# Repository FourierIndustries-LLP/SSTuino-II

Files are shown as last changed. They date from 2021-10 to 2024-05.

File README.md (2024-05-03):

Designed by FourierIndustries LLP | Designed and tested in Singapore

# SSTuino II

SSTuino II is an easy to use and industrial-ready Wi-Fi enabled microcontroller, designed and fabricated by SST Alumni. With a smaller form factor, improved Wi-Fi and processing capabilities, this is the next generation of SSTuino.

**SSTuino II documentation available at: https://knowledge.fourier.industries**

## Technical information

### Pinout diagram

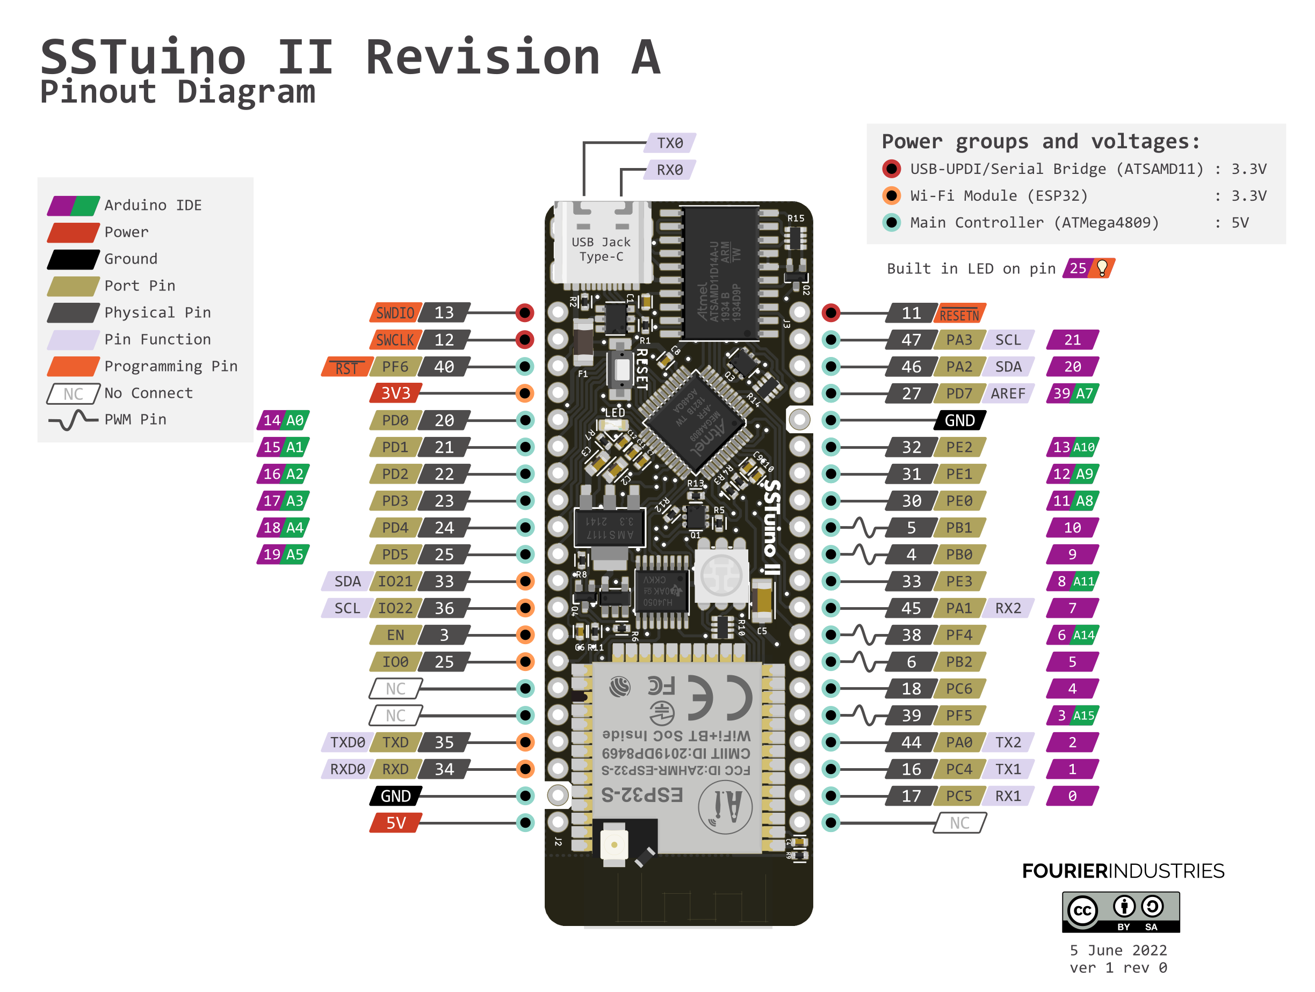
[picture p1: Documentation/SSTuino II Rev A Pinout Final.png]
Pinout


### Repository Layout

* **SSTuino_II**: CAD files for SSTuino II
* **SSTuinoII_Jig**: CAD files for the SSTuino II test jig
* **Manufacturing**: Manufacturing files (Gerbers, BOM, component placement)
* **Documentation**: Documentation for design and manufacturing (not user manuals)
* **Tooling**: Software tools for production and debugging of the SSTuino II

### Automatic repair tool

Paste and run the following command in your terminal to run the autorepair tool, should you run into difficulty launching Arduino IDE or uploading programs onto your SSTuino II. Follow the on-screen instructions carefully. 

Note: This tool is only compatible with Arduino IDE 2. 

```shell
/bin/bash -c "$(curl -fsSL https://raw.githubusercontent.com/FourierIndustries-LLP/SSTuino-II/HEAD/Tooling/sstuino-autorepair.sh)"
```

## Contributing

Contributing to the SSTuino II Git Repository requires you to have EAGLE 8.4 or newer which supports Managed Libraries.

SSTuino II primarily uses EAGLE's Managed Libraries made by Sparkfun, but also contain our own custom footprints and SMD component footprints from various manufacturers.

SSTuino II is derived from the [Arduino Uno WiFi REV2](https://store-usa.arduino.cc/products/arduino-uno-wifi-rev2), and is licensed under a [CC BY-SA 4.0 International license](http://creativecommons.org/licenses/by-sa/4.0/).



## Our team

* Goh Qian Zhe ([@QianZheGoh](https://twitter.com/QianZheGoh))
* Pan Ziyue ([@d3lta-v](https://twitter.com/sammy0025))

And special acknowledgement to the awesome folks at Arduino, Sparkfun and Adafruit for technical reference and ECAD models.

OSHW

Open Source Hardware (OSHW)

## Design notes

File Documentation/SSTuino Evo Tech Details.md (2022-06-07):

# SSTuino Evo Technical Information

This document outlines the deep technical information regarding the SSTuino Evo ("the device") and its constituent modules on the board ("module"), ensuring a high level of design stability, documentation and conformity to standards.

{{TOC}}

## Board layout

The board is routed in imperial units on a 12.5 mil (mili-inch, thousandths of an inch, 1/1000).

Power traces are mostly 24-16 mils, while signal traces are 10 mils standard, going down to a minimum of 8 mils when needed.

Isolate is set at 10 mils, same as majority of signal traces to ensure good manufacturability. 

Text is set at 32 mils, 14% ratio for component identifiers for optimal legibility across manufacturers.

## External Interface (pins)

The pinout of the device is as follows:

**Left Side:**

| Pin | Name | Purpose |
| :-: | :--- | :--- |
|  1  | SWDIO | COM: Programming port |
|  2  | RST (PF6) | MCU: Reset (active low) |
|  3  | 3.3V | Power, 3.3V out |
|  4  | SWCLK | COM: Programming port |
|  5  |  A0 (PD0) | MCU: Analog in |
|  6  |  A1 (PD1) | MCU: Analog in |
|  7  |  A2 (PD2) | MCU: Analog in |
|  8  |  A3 (PD3) | MCU: Analog in |
|  9  |  A4 (PD4) | MCU: Analog in |
|  10 |  A5 (PD5) | MCU: Analog in |
|  11 |  ESP/SDA  | ESP: I2C SDA pin |
|  12 |  ESP/SCL  | ESP: I2C SCL pin |
|  13 | ESP/EN  | ESP: EN pin (active high) |
|  14 |  ESP/IO0  | ESP: IO0 pin for bootup |
|  15 | NC | |
|  16 | NC | |
|  17 | ESP/TX  | ESP: UART Tx (5v logic) |
|  18 | ESP/RX  | ESP: UART Rx (5v logic) |
|  19 | GND | Ground |
|  20 | 5V | Power, 5V out/in |

**Right Side:** 

| Pin | Name | Purpose |
| :-: | :--- | :--- |
|  1  | RESETN | COM: Programming port |
|  2  | 21 (SCL/PA3) | MCU: I2C SCL pin |
|  3  | 20 (SDA/PA2) | MCU: I2C SDA pin |
|  4  | AREF (7/PD7) | MCU: AREF pin |
|  5  | GND | GND |
|  6  | 13 (PE2) | MCU: digital IO 13 |
|  7  | 12 (PE1) | MCU: digital IO 12 |
|  8  | 11 (PE0) | MCU: digital IO 11 |
|  9  | 10 (PB1) | MCU: digital IO 10 (PWM capable) |
|  10 | 9 (PB0) | MCU: digital IO 9 (PWM capable)  |
|  11 | 8 (PE3) | MCU: digital IO 8 |
|  12 | 7 (PA1) | MCU: digital IO 7 |
|  13 | 6 (PF4) | MCU: digital IO 6 (PWM capable)  |
|  14 | 5 (PB2) | MCU: digital IO 5 (PWM capable)  |
|  15 | 4 (PC6) | MCU: digital IO 4 |
|  16 | 3 (PF5) | MCU: digital IO 3 (PWM capable)  |
|  17 | 2 (PA0) | MCU: digital IO 2 |
|  18 | 1 (PC4) | MCU: digital IO 1 (TX) |
|  19 | 0 (PC5) | MCU: digital IO 0 (RX) |

This needs further validation with the MegaCoreX pin designations.

| Validation Type | Result  |
| :--- | :--- |
| Pinout Validation | Pending |
| Logic Validation  | Pending |

## USB Interface

### USB 2.0 Type C Plug

This module includes the Type-C (USB 2.0 protocol only) receptacle and the appropriate CC1 and CC2 pull-down resistors of 5.1kOhm 0402 SMD resistors. 

For standards surrounding the USB PD protocol for Type-C, please refer to [Microchip's AN1953 Application Note](http://ww1.microchip.com/downloads/en/appnotes/00001953a.pdf), section 3.2.

It is very similar to a [reference design made by Tyler Ward](https://www.scorpia.co.uk/2016/03/17/using-usb-type-c-on-hobyist-projects/)

| Validation Type | Result |
| :--- | :----- |
| Pinout Validation | PASS |
| Logic Validation  | PASS |

The shield of the USB Connector is connected to ground, as per design reference from many designs such as the Adafruit Feather series. A potential future improvement is to connect it to an RC circuit of 4.7nF and 1MOhm components. As mentioned in the SAMD11 data sheet, "Tying the shield directly to ground would create a direct path from the ground plane to the shield, turning the USB cable into an antenna. To limit the USB cable antenna effect, it is recommended to connect the shield and ground through an RC filter.".

### Overcurrent and ESD Protection

This module protects the rest of the device from dangerous electrical conditions, namely overcurrent and electrostatic discharge (ESD). 

The overcurrent protection is handled by a [Littelfuse 1206L075THYR](https://datasheet.lcsc.com/lcsc/1810111934_Littelfuse-1206L075THYR_C99563.pdf) polyfuse packaged in 1206, which cuts off at 6V, 0.75A, with a maximum time to trip of 0.2s at 8A.

ESD protection is handled by a [TechPublic TPUSBLC6](https://datasheet.lcsc.com/lcsc/2005211235_TECH-PUBLIC-TPUSBLC6-2SC6_C558442.pdf) TVS diode array specifically designed for USB 2.0 interfaces.

| Validation Type | Result |
| :--- | :----- |
| Pinout Validation | PASS |
| Logic Validation  | PASS |

### Serial Interface

#### Hardware

The serial interface of the device is provided by an ATSAMD11D14A-SSUT/SSNT (20-pin SOIC) ARM Cortex-M0 processor acting as a USB to TTL Serial and USB to UPDI two-in-one converter. This design is based on the Arduino Nano Every, modified to use a larger 20-pin SOIC chip due to board density constraints as well as the 2020/2021 global chip shortage.

The chip itself contains a pinout for RESETN, SWDIO and SWCLK (standard ARM MCU programming port using CWSIS-DAP). Keep in mind that all of this is 3.3V I/O.

The chip is supported by a 0.1uF (100nF) capacitor for decoupling.

RESETN (PA28) and SWCLK (PA30) is tied to logic high through a 4.7kOhm resistor, while SWDIO (PA31) is floating. This is validated.

PA24 and PA25 on the MCU are connected to USB D- and D+ respectively. This pinout is validated.

PA14 and PA15 are programmed as a normal serial port, bit-banged to UPDI spec, and goes through bidirectional level shifting `(3.3V<->5V)`. This pinout is validated.

PA22 and PA23 are the TX and RX lines respectively. Both of them go through bidirectional voltage shifting `(3.3V<->5V)`.

The only component that was not integrated with this design compared with the Arduino Nano Every are the two LED lights sitting on the TX/RX lines.

| Validation Type | Result  |
| :--- | :--- |
| Pinout Validation | PASS |
| Logic Validation  | PASS |

#### Software

The software of the Serial Interface shall convert USB signals to TTL-Serial and Atmel UPDI signals for programming and communication between the host computer and the device.

Reprogramming the software on the SAMD11 requires a CMSIS-DAP ARM programmer running at 3.3V logic levels, to target the RESETN, SWDIO and SWCLK pins exposed on the board. Power is still provided by 5V and GND.

The [breadboard SAMD11 tutorial](https://funwithsoftware.org/posts/2019-09-01-breadboard-samd11-part1.html) is an excellent place to start for ARM-based firmware flashing.

The full procedures are [here](https://www.avrfreaks.net/comment/2832921#comment-2832921).

How to load the Bootloader:

1. Install OpenOCD on your Mac if you haven't already: `brew install openocd`
2. Create a folder for two files: the bootloader file itself (looks like `sam_ba_arduino_MuxTO_SAMD11D14AM.bin`) and the `openocd.cfg` file
3. Copy the SAMD11 tutorial's default code for OpenOCD into the configuration file and edit the file name
4. Type `sudo openocd` to begin programming

How to load the Bootloader (PyOCD version)

1. Install PyOCD if you have not: `brew install libusb; python3 -mpip install -U pyocd`
2. Create a folder for 3 important files: the target chip's .pack file, the programmer's .pack file, and the bootloader
3. Download the bootloaders from the [Arduino Core SAMD MuxTO branch repo](https://github.com/arduino/ArduinoCore-samd/tree/muxto/bootloaders/zero/binaries)
4. Erase the chip with `pyocd erase -t atsamd11d14as --chip --pack ~/Downloads/Microchip.SAMD11_DFP.2.5.61.atpack`
5. Execute the command `pyocd flash -t atsamd11d14as --base-address 0x0 sam_ba_arduino_MuxTO_SAMD11D14AM.bin --pack ~/Downloads/Microchip.SAMD11_DFP.2.5.61.atpack`
6. Protect the bootloader by executing a custom OpenOCD script to set the bootloader length to 4096 bits. Run `sudo openocd -f protect_bootloader.cfg`

After the Bootloader is loaded onto the SAMD11, it's time to load the firmware. You might want to compile the firmware for yourself first with the [steps in this guide](https://forum.arduino.cc/t/compiling-and-loading-the-muxto-code/627145)

1.  Add board manager URL: 
2.  Install MattairTech SAM D|L|C core for Arduino - Beta build v1.6.18-beta-b1
3.  Download **bootloader** binary blob from 
4.  Flash bootloader to device
5.  Short SWDIO to GND
6.  Flash the MuxTO **firmware** to device with the following command over the native USB port: 
        
    ```
    ./bossac --port=/dev/cu.usbmodem14101 -U true -i -e -w -v ./MuxTO_SST.bin -R
    ```

Alternatively, it should be possible to flash the hex file directly to the system through the same CMSIS-DAP PyOCD interface by running the following command: `pyocd flash -t atsamd11d14as ~/Library/Arduino15/packages/arduino/hardware/megaavr/1.8.7/firmwares/MuxTO/MuxTO.hex --pack ~/Downloads/Microchip.SAMD11_DFP.2.5.61.atpack`

At this point, we're not done yet. We need to patch MegaCoreX's `boards.txt` with our own custom configuration to let MuxTO work through a hacky version of JTAG2UPDI:

```
################################################
4809.menu.pinout.sstuinoii=SSTuino II
4809.menu.pinout.sstuinoii.build.variant=uno-wifi
4809.menu.pinout.sstuinoii.upload.tool=avrdude_nanoevery
4809.menu.pinout.sstuinoii.upload.use_1200bps_touch=true
4809.menu.pinout.sstuinoii.upload.protocol=jtag2updi
4809.menu.pinout.sstuinoii.program.extra_params=-P{serial.port} -e
4809.menu.pinout.sstuinoii.build.compat=
#################################################
```

If you need to build from source, you will need to patch Arduino specific changes to MT's core. 

Compilation options available here: `arduino:samd:muxto:float=default,config=enabled,clock=internal_usb,timer=timer_732Hz,bootloader=4kb,serial=two_uart,usb=cdc`

[Link](https://github.com/arduino/ArduinoCore-megaavr/blob/master/.github/workflows/compile-muxto.yml)

If you wish to change the MuxTO firmware without recompilation, you can directly edit the `MuxTO.bin` file using a hex editor. 

For example, the USB VID and PID can be edited at offset 0x2E3C, with an order of `[VID LSB][VID MSB][PID LSB][PID MSB]` (least and most significant *byte*, not bit). For more details, see this [line of code in Arduino Core](https://github.com/arduino/ArduinoCore-samd/blob/9f91accecc8298976670234e4d6ac0afef5c7a39/bootloaders/zero/sam_ba_usb.c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)

If the bootloader + an existing firmware is already on the chip, short SWDIO to GND to enter bootloader mode for direct USB programming.

During the flashing of the ATmega4809 target, the programmer type needs to be JTAG2UPDI, as it essentially pretends to be a JTAG device, with a bit of a special 1200bps handshake in between to initiate the UPDI process. You will need to specify the target serial port.

These were the fuses returned by avrdude:

```
fuse0: 0x0 (WDTCFG)
fuse1: 0x0 (BODCFG)
fuse2: 0x2 (OSCCFG)
fuse4: 0x0
fuse5: 0xe4 (SYSCFG0)
fuse6: 0x7 (SYSCFG1: startup time only)
fuse7: 0x0 (APPEND: end of application section)
fuse8: 0x0 (BOOTEND: end of boot section)
lock: 0xc5 (LOCK)
```

`OSCCFG` is configured as: 0x02, same as default factory setting, which is to run at 20MHz, with no oscillator lock meaning that calibration registers can be adjusted at runtime.

`SYSCFG0` seems to be configured as: 0xe4. Note that default factory value is 0xCO, which echoes exactly the same fuse settings (but not as corrupted)! It appears that the reserved fuses are not even properly cleared as 0? The correct hex value is 0xc9,

**Current chip settings**: 

* CRCSRC: BOOTAPP
* RSTPINCFG: GPIO <- this is interesting! Because it should have been set to RESET. A fuse configuration error?
* EESAVE: EEPROM erased by chip erase

**Correct settings as per board definition**:

* CRCSRC: BOOTAPP
* RSTPINCFG: RESET
* EESAVE: EEPROM NOT erased by chip erase

`LOCK` is as factory default, no need to change as altering it will lock the chip.

Comparison between the two settings:

```
0xe4: 1110 0100
0xc9: 1100 1001
```

**Further Reading**

* [PyOCD Tutorial](https://www.hackster.io/sabas1080/how-to-debug-hardware-with-openocd-or-pyocd-e7e718)
* [PyOCD Tutorial #2](https://chowdera.com/2021/08/20210825013223713b.html)
* [PiOCD GitHub](https://github.com/pyocd/pyOCD)
* [Keil .pack library](https://www.keil.com/dd2/pack/#!#third-party-download-dialog)
* [OpenOCD CPU configuration](https://openocd.org/doc/html/CPU-Configuration.html)
* [OpenOCD Debug Adapter config](https://openocd.org/doc/html/Debug-Adapter-Configuration.html)
* [OpenOCD Config File Guide](https://openocd.org/doc/html/Config-File-Guidelines.html)

### Level Shifting

The level shifting portion of the USB interface is handled by a dual transistor BSS138PS IC and a single transistor BSS138PW, which shifts 3.3V to 5V and vice versa, fully bidirectional.

All transistors use 4.7kOhm resistors.

| Validation Type | Result  |
| :--- | :--- |
| Pinout Validation | PASS |
| Logic Validation  | PASS |

## Voltage Regulator

The onboard voltage regulation is handled by an AMS1117-3.3 Low Dropout (LDO) linear voltage regulator. The voltage regulator is responsible for delivering adequate current and stable power at the correct voltage to the ESP32 and ATSAMD11D14A chips. 

This particular type of LDO is cheap and widely available, but is not the most efficient, especially at low power, due to its higher quiescent current.

For reference, [Andrea's video on ESP32 boards](https://www.youtube.com/watch?v=ajt7vtgKNNM) offers a fantastic comparison of the different power supplies used by the different boards. Future boards may use more efficient power conversion circuitry.

The current voltage regulator circuitry has an input and output capacitor of 10uF. Further decoupling capacitors are closer to the individual chips and will not be discussed in this section.

| Validation Type | Result |
| :--- | :----- |
| Pinout Validation | PASS |
| Logic Validation  | PASS |

## Main Controller

### Pinout

The pinout of the main controller needs to be validated against the datasheet and firmware. The current firmware we are intending to run is the MegaCoreX (Uno Wifi Rev2) configuration, with the following settings:

* Chip: 4809
* Clock: Internal 16MHz
* BOD: 2.6V
* Pinout: Uno Wifi
* Reset pin: Reset
* Bootloader: No
* Programmer: JTAG2UPDI

```
#define SPIWIFI_SS    35   // Chip select pin PF2
#define SPIWIFI_ACK   36   // a.k.a BUSY or READY pin PF3
#define ESP32_RESETN  29   // Reset pin PA7
#define ESP32_GPIO0   28   // GPIO0 PA6
// MOSI: PC0
// MISO: PC1
// SCK:  PC2
```

### Reset switch

The reset switch is tied to PF6, which is pulled to logic high by a 100kOhm resistor. This design has been proven in the Curiosity Nano demo board.

| Validation Type | Result  |
| :--- | :--- |
| Pinout Validation | PASS |
| Logic Validation  | PASS |

### Decoupling

The decoupling capacitors C7-C12 are important in decoupling the MCU from the rest of the electrical noise on the board. VDD1 and AVDD uses 0.1uF capacitors, while VDD2 and PD7/AREF uses a 0.1uF and 4.7uF capacitor in parallel.

This design has been validated with the Arduino Uno Wifi's design for correctness.

| Validation Type | Result  |
| :--- | :--- |
| Pinout Validation | PASS |
| Logic Validation  | PASS |

### Built-in LED

The device comes with a user-controllable built in LED on PD06 (A6), which can be invoked with the LED_BUILTIN. It is connected to a 1kOhm resistor to prevent burnout. (Might want to calculate the LED's brightness here) This design is validated against the Arduino Uno Wifi Rev2.

Need to double check the LED's polarity markings for a proper placement.

| Validation Type | Result  |
| :--- | :--- |
| Pinout Validation | PASS |
| Logic Validation  | PASS |

## ESP32 Module

The ESP32 Module acts as a wireless coprocessor and handles Wi-Fi and Bluetooth connections. Given the right tools, it can be modified or "hacked" to behave as if it's the master. The design of the ESP32 Module can be traced back to the design of the [Adafruit AirLift breakout board](https://learn.adafruit.com/adafruit-airlift-breakout/downloads)

### Firmware uploading

One can upload the firmware using a Serial bypass called `SerialNINAPassthrough`, which passes through the USB serial port to Serial1, which is then manually linked to the ESP32's 5V tolerant serial port (so you just need a jumper cable).

Flash the firmware using the following command:

`esptool.py --port /dev/cu.usbmodem14101 --before no_reset --baud 115200 write_flash 0 ~/Downloads/NINA_W102-1.7.4.bin`

### Decoupling circuitry

Decoupling is handled by a 100uF tantalum capacitor and a 0.1uF ceramic capacitor. This design is validated with the NodeMCU-32 design.

| Validation Type | Result  |
| :--- | :--- |
| Pinout Validation | PASS |
| Logic Validation  | PASS |

### Voltage shifting circuitry

#### MOSFET parts

The voltage shifting circuitry closely tied to the ESP32 are based on the BSS138 MOSFET. Design is based on Arduino Uno Wifi Rev2 and will require further validation. In addition, IO0 has a  jumper to D28/PA6 for ATMega to ESP32 reprogramming needs.

| Validation Type | Result  |
| :--- | :--- |
| Pinout Validation | PASS |
| Logic Validation  | PASS |

#### Logic IC parts

The voltage shifting circuitry that is further away from the ESP32 module on the schematic includes a CD74HC4050 buffer (operating at 3.3V, referred as the '4050 for brevity) and a 74AHC1G125 single buffer gate (referred to as the '1G125 for brevity)

The '4050 acts as a uni-directional logic level shifter to convert 5V to 3.3V at reasonable signal speeds. The '1G125 has a single buffered gate through which MISO is toggled by the ESP side "chip select" pin. This is to free up the MISO bus when the ESP is not actively communicating with the Main Controller, and doubles as a logic level shifter.

| Validation Type | Result  |
| :--- | :--- |
| Pinout Validation | PASS |
| Logic Validation  | PASS |

### RGB LED

The RGB LED is a 5050 sized RGB LED utilising a 1k resistor array. It is controllable from the Arduino by instructing the ESP32 module to power up and down those pins to indicate state.
The model of the RGB LED is [TC5050RGBF08](https://datasheet.lcsc.com/lcsc/2009231707_TCWIN-TC5050RGBF08-3CJH-AF53A_C784540.pdf).

Do take note of a few things during validation: cathode/anode markings and pinout with ESP32.

| Validation Type | Result  |
| :--- | :--- |
| Pinout Validation | PASS |
| Logic Validation  | PASS |

## Testing programs

The SSTuino II shall be put through a series of acceptance testing to ensure it fully meets the needs of our customers. We adapted our testing program from a select subset of industry-standard testing programs.

The tests are: Engineering Validation Test (EVT), Product Validation Test (PVT), and finally Mass Production QC (MPQC). 

For an overview of standard development processes, please check out [this article](https://formlabs.com/asia/blog/validation-testing-product-development-poc-evt-dvt-pvt-mp/)

### Engineering Validation Testing (EVT)

The primary goal of EVT is to determine the feasibility of the entire project in technical terms. Essentially, it boils to "whether the product works as a fully built prototype".

This section will go through all the exact tests that the EVT stage will conduct to ensure the success of the product. This will also involve replicating common projects from previous existing SSTuino 1 projects so that we can be assured that all previous projects will work perfectly.

#### EVT1: Digital I/O

All digital I/O must be able to write and read a digital signal with no error. They must be able to generate a stable clock signal and inspected by an oscilloscope to verify their signal characteristics (bit-bang). For pins with PWM capability, they must be able to emit the desired PWM percentage at the pre-defined frequency, validated by means of an oscilloscope. For the purposes of this test, a simple program is used to trigger pins based on serial input. [WORKING]

It would also be good to test the performance of Servo-related libraries, to check if it is able to actuate a servo under certain circumstances. [WORKING]

For digital inputs, they must be tested with a simple pushbutton test with pull-up/down resistor. [WORKING]

#### EVT2: Analogue inputs

All pins capable of analogue inputs must be tested with a simple potentiometer and serial readout of the analogue voltage. [WORKING]

#### EVT3: Serial ports

The sole external serial port provided to the user, `Serial1`, will need to be validated with a simple loopback functionality (connect TX to RX and watch it read back whatever you type into it) at 9600bps 8N1 and 115200bps 8N1 protocols. [WORKING]

#### EVT4: I2C functionality

Test out I2C peripherals, such as screen and sensors. [WORKING]

#### EVT5 Series: Basic projects

This section will go over all the basic projects that the SSTuino II should be perfectly capable of performing.

##### EVT5-1: Ultrasonic sensor

An ultrasonic sensor is a basic sensor that requires precise signal timing to produce correct results. As such, an ultrasonic sensor should be tested with the SSTuino for accuracy. [WORKING]

##### EVT5-2: HTTP(S) connected applications

The device shall be able to connect to HTTP(S) endpoints to GET as well as to POST requests. Adafruit IO's HTTP interface is an ideal playground to get started with these requests. To extend the HTTP(S) testing, simple JSON decoding should also be tested. [WORKING]

##### EVT5-3: MQTT connected applications

The device shall be able to connect to MQTT endpoints to publish and subscribe to endpoints. More importantly, the publish and subscribe should be mixed together in the same program (reflecting many real life applications) and the subscribe function must not drop out during normal operations due to signal integrity issues. A good example would be to subscribe to a colour and hence reprogram the RGB LED on the board through the internet. [WORKING]

In addition, a test should be done for simultaneous subscribe and publish, to ensure that extended functionality like this works. [WORKING]

This is also a good chance to test the QoS capabilities of MQTT, with the ability to guarantee delivery of messages with QoS level 1. [WORKING]

#### EVT6: Connection with host computers

This device will need to test its connection of device with various host computers including:

* Intel Mac with USB-A (USB 3) [WORKING]
* Intel Mac with USB-C (TB3/4) [WORKING]
* Apple Silicon Mac with USB-C (TB4) [WORKING]
* Windows PC with USB-A (USB 3/2) [WORKING]
* Windows PC with USB-C (USB 3/TB3/TB4) [WORKING]

Our USB PID/VID combo is 0x557D/0x1206. For reference to our application on `pidcodes`, please click [this link](https://github.com/pidcodes/pidcodes.github.com/pull/704)

### Product Validation Test (PVT)

PVT performs an initial production batch of 5% of the full production run, locking in all aspects of the project such as the Bill-of-Materials, circuit board and mechanical design, circuit board specifications among many other factors.

This final test will run identical tests to those defined in EVT, but on a different subset of products. Additionally, it will lay down the required specifications for the test jigs and automated testing programs in anticipation of the next stage, MPQC. 

### Mass Production Quality Control (MPQC)

In mass production, the product will have to go through a short but comprehensive automated test to both flash the firmwares to the 3 major chips on the board, but also to test for end-to-end functionality.

For more information regarding the good use of rigorous testing programs, check out [this article](https://www.bunniestudios.com/blog/?p=5450). For testing and reverse logistics, check out [this article](https://www.bunniestudios.com/blog/?p=4981).

The proposed program scheme is as follows. It will be split into 2 phases:

Phase 1, ARM Mode:

1. Upload **SAMD11**'s bootloader and program both through PyOCD
2. (Optional) Protect the bootloader by locking the boot sector

Phase 2, USB Mode:
1. Check if USB device is connected and recognised (with VID and PID)
2. Upload to **Mega4809** the passthrough program to reprogram the ESP32
3. Invoke `esptool.py` to upload to **ESP32** the AirLift firmware
4. Upload to the **Mega4809** a testing firmware to QC it, with serial responses

The final QC program will consist of the following functions:

* Blink the LED_BUILTIN for 3 seconds [DONE]
* Run an RGB routine on the ESP32's RGB LED for 3 seconds, all the way to full power [DONE]
* (Optional?) Test every pin's digital power out. This will need some sort of an external device that's reading every single pin. A cheaper way is to use LED lights, but that may result in more operator error. In addition, add a buzzer connected to one of the pins to indicate success or failure of QC. [NOT IMPLEMENTED]
* (Optional?) Test analog values (maybe using resistive dividers?) for all the analog pins [NOT IMPLEMENTED]
* Connect to Wi-Fi [DONE]
* Run a MQTT publish operation
* Run a HTTPS GET operation on an endpoint (validating if the MQTT publish action has completed correctly, for example)

Some of the other factors we need to take into consideration are:

* "Auditability" of test: how auditable the test is. The article above proposed a log that's burnt into the chip, giving each and every board a fully auditable history right in the silicon.
* Updating the test jig and remote testing: make sure that in larger production runs where the testing is done offsite, that you are able to OTA update the test jig and to be able to fully replicate a test jig's behaviour locally before transmitting the testing firmware offsite. Currently the SSTuino II has no such requirement

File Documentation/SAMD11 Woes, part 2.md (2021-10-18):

# SAMD11 Woes, part 2

The SAMD11D14A (hereby referred to as SAMD11, not to be confused with the other variants like the C14) solution for a unified UPDI programmer and TTL serial device is elegant and cheap to implement, relative to the more in demand USB-UART chips that we've seen go out of stock everywhere, with existing stock rising to sky-high prices.

However, it is not without its downsides, as shown in the badly documented procedures and ill-maintained repositories, the SAMD11 approach to solving the two-birds-in-one-stone UPDI+UART problem is hardly a straightforward one.

## Rough overview

The SAMD11 acts as a bridge between the host computer's USB port  and the Mega4809, and utilises a total of 3 protocols: USB, UPDI and Serial. 

The SAMD11 is quite different from the AVR microcontrollers that we've seen so far, but are also similar in some major ways. For example, the SAMD11 has a bootloader that allows users to flash programs directly through its native USB port without having to use its specialised programming port called SWD. This is similar to how AVR microcontrollers can be flashed directly with their Serial ports instead of going through a complicated AVR-ISP.

On the firmware side, this implementation of a hybrid adapter, called MuxTO, exposes 3 peripherals: the USB port and 2 Serial ports. One of the Serial ports is bitbanged to simulate a UPDI interface, connected to USB. The other Serial port communicates with the Mega4809, and forwards information to and from this physical Serial port to USB as a virtual Serial port. 

## Prelude

The first problem started when I attempted uploading the bootloader: OpenOCD refused to upload regardless of the settings I used. I eventually solved the issue by using PyOCD for actual erasure and uploading of flash, while using OpenOCD to perform maintenance tasks such as locking the boot sector (4096 bytes). 

## The "last known working"

The last known working method I used to upload the MuxTO firmware is as below:

1. Connect the board to an SWD programmer
2. Erase the chip with `pyocd erase -t atsamd11d14as --chip --pack ~/Downloads/Microchip.SAMD11_DFP.2.5.61.atpack`
3. Flash the bootloader with `pyocd flash -t atsamd11d14as --base-address 0x0 sam_ba_arduino_MuxTO_SAMD11D14AM.bin --pack ~/Downloads/Microchip.SAMD11_DFP.2.5.61.atpack`
4. Protect the bootloader by executing a custom OpenOCD script to set the bootloader length to 4096 bits. Run `sudo openocd -f protect_bootloader.cfg`
5. Flash the rest of the firmware with `pyocd flash -t atsamd11d14as ~/Library/Arduino15/packages/arduino/hardware/megaavr/1.8.7/firmwares/MuxTO/MuxTO.hex --pack ~/Downloads/Microchip.SAMD11_DFP.2.5.61.atpack`

The alternative using `bossac` and the native USB port would be to replace step 5 with: Flash the rest of the firmware with `./bossac --port=/dev/cu.usbmodem14101 -U true -i -e -w -v ~/Library/Arduino15/packages/arduino/hardware/megaavr/1.8.7/firmwares/MuxTO/MuxTO.bin -R`.

## The problem

The SAMD11 solution worked flawlessly for its 1st goal: to flash the Mega4809 target through UPDI. However, the 2nd goal, which is to deliver a serial interface bridge between USB at the ATmega4809's serial port, had serious issues. Getting the serial port to write strings to the host computer resulted in consistently garbled text, implying there's something wrong with the serial signal timings. 

The flow of data is as below:

```
[ATmega4809] -> (Serial) -> [SAMD11] -> (USB) -> [USB on host computer]
```

The garbled text seems to have a consistency to it, and is not resolved by changing around the serial configuration (adding parity and stop bits, changing the baud rate).

## Possibilities

The possibilities here are ordered in easiest to hardest to identify and/or fix.

### Board design or build

It could possibly be a design/build issue with the board, with how thin the serial lines are, they might have caused signal integrity issues. However, at these low speeds, signal integrity is very unlikely to be a concern...

This possibility of a build issue can be more or less eliminated by flashing the firmware to a different board, but for design issue that would need a more skilled pair of eyes to take a look...

### Flash overfill

My first suspicion focused on the bootloader and program size. The MuxTO firmware is known to be too large to feasibly fit into the flash. I was unable to flash the firmware through the native USB port with `bossac` as it complained about flash overfill, but was able to flash the firmware over SWD. This is weird and possibly implies a flash corruption, which will certainly explain the corrupted transmission when transmitting back to the host.

Through a flash dump and by comparing the hex files of the original and the data retrieved from the chip, we might be able to inspect what went wrong with the flashing process (and whether PyOCD overfilled the flash without warning the user). This issue can be extended to my next point, which would be an inherent issue with the firmware provided on official repositories.

### Inherent issue with the firmware or build environment

We preferably want to have a copy of the exact build environment (including pinning down the exact `arm-eabi-g++` toolchain) to ensure that the build passes with no problems or overflows.

Alternatively...it appears from some forum posts imply that a newer compiler might fix the issues. Alternatively, an older version of MattairTech's SAMD11 Core might also be the key to the fix, although all of this are just speculations.

### Mega4809 at fault?

All of our efforts have focused on the SAMD11, but it's also possible that the Mega4809 was at fault. `MCUdude/MegaCoreX` repository had [Issue #59](https://github.com/MCUdude/MegaCoreX/issues/59) saying that the Serial baud rate was incorrect at a certain clock speed, due to a very specific host and client configuration. The author said that it is possibly a chip level issue on the 4809 (internal oscillator being out of whack), while the contributor said it is likely an issue with the host machine. 

Given this precedence, an out-of-whack oscillator theory may not be far fetched. SAMD11 is able to calibrate its own oscillator through its USB host, but the Mega4809 has no such capability. If this was really the fault of the Mega4809, it means we may have to "eat up" some of the responsibility through either a partial redesign, or to perform board-level repairs as and when it fails QC.

### Mega4809 at fault: validation

This theory might be able to be validated through a serial monitor on any of the Mega4809's other serial pins (although this may not be a perfect fix).

## Recreating the build chain

Given the lack of Arduino's official documentation on the matter, it is very difficult to recreate their build chain. 

To recreate Arduino's build chain, we need to construct a timeline of how they built MuxTO:

* Dec 2017 - The last stable version of `mattairtech/ArduinoCore-samd` was introduced, 1.6.17
* June 2018 - The last beta version of `mattairtech/ArduinoCore-samd` was introduced, 1.6.18-beta-b1
* May 2019 - Nano Every is announced, MuxTO bootloader and modifications added to `arduino/ArduinoCore-samd/muxto` branch (bootloader) <- need to find out which version of `mattairtech/ArduinoCore-samd` was used around this time. According to the commits, they were using the bleeding edge beta release
* June 2019 - first units of Nano Every is shipped
* July 2019 - Issue #51 was lodged on `arduino/ArduinoCore-megaavr` that the serial interface locks up when transferring >128 chars
* Aug 2019 - Issue #51 was patched in `arduino/ArduinoCore-samd/muxto`
* Sept 2019 - Issue #52 was flagged out and some improvements were made to the bootloader. This is when the bootloader was last updated. You can go to [this link](https://github.com/arduino/ArduinoCore-megaavr/pull/52) and proceed to the files changed section to download that particular build of MuxTO.
* May 2021 - Issue #103 was filed in `arduino/ArduinoCore-megaavr` that the custom firmware was too large. The creator of MuxTO [commented](https://github.com/arduino/ArduinoCore-megaavr/issues/103#issuecomment-849440652) that using a newer compiler might fix the issue. Eventually someone set up a CI workflow for MuxTO using `mattairtech/ArduinoCore-samd` 1.6.17 (which every build failed :^))

## Allocation of boot flash

0-4096 bytes [4096]: Bootloader
4097-16384 bytes [12288]: Program

It appears that the latest version of the precompiled MuxTO firmware fully bursts the 12288 byte cap allocated to the program.

## Conclusion

Overall quite the frustrating experience with the SAMD11 as a universal UART+UPDI gateway. 

We can try the old firmware compiled by the firmware author in [this link](https://github.com/arduino/ArduinoCore-megaavr/issues/51#issuecomment-517702530)

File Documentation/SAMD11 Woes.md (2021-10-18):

# SAMD11 Failed to write memory using OpenOCD

This little writing is all about the insanity that is debugging this SAMD11 and why it's not working:

## Environment:

**Software**:
* macOS 11.5.2
* OpenOCD 0.11.0 installed through Homebrew

**Hardware**:
* [NanoDAP (CMSIS-DAP compatible)](https://github.com/wuxx/nanoDAP)
* Custom board

## Problem

I designed a custom board with an ATSAMD11D14A-SSNT onboard, to act as an USB-UART interface and UPDI programmer similar to the Arduino Nano Every's design:

<insert Arduino every's diagram here>

I was attempting to flash a generic bootloader onto the SAMD11 using the helpful [Breadboard SAMD11 Tutorial](https://funwithsoftware.org/posts/2019-09-01-breadboard-samd11-part1.html), but the OpenOCD prompt threw errors in the console log below:

```
Open On-Chip Debugger 0.11.0
Licensed under GNU GPL v2
For bug reports, read
	http://openocd.org/doc/doxygen/bugs.html
DEPRECATED! use 'adapter srst delay' not 'adapter_nsrst_delay'
DEPRECATED! use 'adapter srst pulse_width' not 'adapter_nsrst_assert_width'
Info : CMSIS-DAP: SWD  Supported
Info : CMSIS-DAP: JTAG Supported
Info : CMSIS-DAP: FW Version = 0254
Info : CMSIS-DAP: Serial# = 0700000105dbff343634564643237741a5a5a5a597969908
Info : CMSIS-DAP: Interface Initialised (SWD)
Info : SWCLK/TCK = 1 SWDIO/TMS = 1 TDI = 0 TDO = 1 nTRST = 0 nRESET = 1
Info : CMSIS-DAP: Interface ready
Info : clock speed 400 kHz
Info : SWD DPIDR 0x0bc11477
Info : at91samd11d14ass.cpu: hardware has 4 breakpoints, 2 watchpoints
Error: at91samd11d14ass.cpu -- clearing lockup after double fault
Polling target at91samd11d14ass.cpu failed, trying to reexamine
Info : at91samd11d14ass.cpu: hardware has 4 breakpoints, 2 watchpoints
Info : starting gdb server for at91samd11d14ass.cpu on 3333
Info : Listening on port 3333 for gdb connections
target halted due to debug-request, current mode: Thread 
xPSR: 0x91000000 pc: 0x000004a0 msp: 0x20000ffc
target halted due to debug-request, current mode: Thread 
xPSR: 0x91000000 pc: 0x000004a0 msp: 0x20000ffc
** Programming Started **
Info : SAMD MCU: SAMD11D14ASS (16KB Flash, 4KB RAM)
Info : SWD DPIDR 0x0bc11477
Error: Failed to write memory at 0x00000040
Error: samd_write: 889
Error: error writing to flash at address 0x00000000 at offset 0x00000000
embedded:startup.tcl:530: Error: ** Programming Failed **
in procedure 'script' 
at file "embedded:startup.tcl", line 26
in procedure 'program' called at file "openocd.cfg", line 17
in procedure 'program_error' called at file "embedded:startup.tcl", line 595
at file "embedded:startup.tcl", line 530
Info : Listening on port 6666 for tcl connections
Info : Listening on port 4444 for telnet connections
```

The following diagram is a section of my own design which involved the SAMD11:

<insert my own design here>

My `openocd.cfg` is as below: 

```
source [find interface/cmsis-dap.cfg]
transport select swd

set CHIPNAME at91samd11d14ass
source [find target/at91samdXX.cfg]

reset_config srst_nogate

adapter_nsrst_delay 100
adapter_nsrst_assert_width 100

init
targets
reset halt

at91samd bootloader 0
program sam_ba_Generic_D11D14AS_SAMD11D14AS.bin verify
at91samd bootloader 4096
reset
shutdown
```

## Steps taken

### Hardware inspection

I have previously checked my wiring and design, and did not find any issues that indicated a fault in wiring, although an extra pair of eyes would be helpful. I have tried this on 2 boards and got identical results, which hopefully rules out a faulty chip or board.

I have also swapped the cables around and have tested all hookup cables for continuity. All cables are known good.

### Environment

As I'm a first-time ARM microcontroller user (previously only tinkered with AVRs), I'm not very familiar with some of the tools used. My first instinct was perhaps a specific software environment that resulted in the error.

I have attempted this in a Windows 10 environment as well, with OpenOCD 0.10.0 instead of 0.11.0, and resulted in identical console output.

### Chip-erase

I tried running the `at91samd chip-erase` through the OpenOCD telnet interface, followed by running OpenOCD as usual with the .cfg file, but that does not appear to resolve any issues. 

### Reducing frequency

I also attempted to reduce the speed of the adapter from 400kHz to 40kHz as outlined in an [Arduino.cc forum post](https://forum.arduino.cc/t/flash-problem-with-samd21g18a-using-openocd-swd/609867/4), but that did not solve anything; the output was identical.

## Other possibilities to explore

### Lack of an external crystal?

[One post](https://community.atmel.com/comment/2541201#comment-2541201) on a tangentially related device, a SAMD21, proposed that a lack of an external crystal might be the issue. However, as there is no program loaded to the microcontroller, I doubt that it's looking for an external crystal, especially when the tutorial I followed made no mention of a crystal.

### Something wrong with my CMSIS-DAP?

My CMSIS-DAP compatible programmer might be faulty, hopefully this is not the case as I'm not quite ready to throw down the cash for an Atmel-ICE :')

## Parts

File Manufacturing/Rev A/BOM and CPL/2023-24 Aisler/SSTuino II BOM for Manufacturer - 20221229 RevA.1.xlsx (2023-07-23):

Customer's Name: |  | FourierIndustries LLP
PCB part No.: |  | SSTuino_II_2022-12-29_Aisler.zip
Date of updating: |  | 2022-12-30 |  |  |  | Qty of PCBA: | 300 | Pcs
 | Please note:
 | 1. This is only example of BOM list. Customer should followed by your own design to fill in information of components which in gray color in below list.
 | 2. The basic information of components must fill up, such as designator, value, MFG part No. and quantity.
 | 3. Please prived "MFG part No." or Order Code, which will avoid misunderstanding or mis-order. (The Order Code can be from Element14, Digi-Key, Mouser or RS)
 | 4. Red highlight means that this source is out of stock
S/N | Designator * | Comment/ value* | Footprint | Comment | MFG part No. * | Qty(per PCB)* | Qty(Total) | Digi-key order code | LCSC Order Code
1 | C1 C4 C7 C8 C9 C11 | 0.1uF | CAPC1005X60 |  | CL05B104KO5NNNC | 6 | 1800 |  | C1525
2 | R7 | 1k | RESC1005X40 |  | 0402WGF1001TCE | 1 | 300 |  | C11702
3 | R10 | 1k | RESPACK_4X0402 |  | 4D02WGJ0102TCE | 1 | 300 |  | C25726
4 | C6 | 1uF | CAPC1005X60 |  | CL05A105KA5NQNC | 1 | 300 |  | C52923
5 | R4 R5 R11 R12 R13 | 4.7k | RESC1005X40 |  | 0402WGF4701TCE | 5 | 1500 |  | C25900
6 | R14 R15 | 4.7k | RESPACK_4X0402 |  | 4D02WGJ0472TCE | 2 | 600 |  | C29586
7 | C10 C12 | 4.7uF | CAPC1005X60 |  | CL05A475MP5NRNC | 2 | 600 |  | C23733
8 | R1 R2 | 5.1k | RESC1005X40 |  | 0402WGF5101TCE | 2 | 600 |  | C25905
9 | F1 | 6V/0.75A | 1206 |  | 1206L075THYR | 1 | 300 |  | C99563
10 | R6 R8 | 10k | RESC1005X40 |  | 0402WGF1002TCE | 2 | 600 |  | C25744
11 | C2 C3 | 10uF | CAPC1608X85 |  | CL10A106KP8NNNC | 2 | 600 |  | C19702
12 | R9 | 12k | RESC1005X40 |  | 0402WGF1202TCE | 1 | 300 |  | C25752
13 | U5 | SN74AHC1G125DBVR | SOT23-5L |  | SN74AHC1G125DBVR | 1 | 300 | 74AHC1G125W5-7DICT-ND
14 | U4 | 74HC4050 | TSSOP16 |  | CD74HC4050PWR | 1 | 300 | 296-9215-1-ND
15 | R3 | 100k | RESC1005X40 |  | 0402WGF1003TCE | 1 | 300 |  | C25741
16 | C5 | 100uF | CAPC3216X135 |  | CL31A107MQHNNNE | 1 | 300 |  | C15008
17 | D1 | 5050 SMD LED | LED-TRICOLOR-5050 |  | TC5050RGBF08-3CJH-AF53A | 1 | 300 |  | C784540
18 | VR1 | AMS1117-3.3 | SOT230P696X180-4N |  | AMS1117-3.3 | 1 | 300 |  | C6186
19 | U3 | ATSAMD11D14A-SSUT | SOIC127P1030X265-20N |  |  | 1 | 300 | ATSAMD11D14A-SSUTCT-ND
20 | Q1 Q3 | BSS138PS | ARDUINO-TRANSISTORS_SOT363 |  | BSS138PS | 2 | 600 |  | C2912548
21 | Q2 Q4 | BSS138PW | SOT65P210X110-3N |  | BSS138W-7-F | 2 | 600 |  | C24553
22 | U2 | ESP32-WROOM-32D-N4 | ESP-32S |  | ESP32-WROOM-32D-N4 | 1 | 300 |  | C473012
23 | U1 | MEGA4809 | TQFP48 |  |  | 1 | 300 | 150-ATMEGA4809-AURCT-ND
24 | Z1 | TPUSBLC6-2SC6 | SOT95P280X110-6N |  | TPUSBLC6-2SC6 | 1 | 300 |  | C558442
25 | RESET | TS-1088-AR02016 | SW2-2.6-3.9X2.9X1.5+0.4MM |  | TS-1088-AR02016 | 1 | 300 |  | C720477
26 | J1 | TYPE-C-31-M-12 | HRO_TYPE-C-31-M-12 |  | TYPE-C-31-M-12 | 1 | 300 |  | C165948
27 | LED | YELLOW | LED-0603 |  | 19-213/Y2C-CQ2R2L/3T(CY) | 1 | 300 |  | C72038
28 | SPI | JST SH 4P | BOOMELE(Boom Precision Elec) C145956 |  |  | 2 | 600 |  | C145956
29 | J2 J3 | 1X20P | 1x20P Stacking Headers | DO NOT ASSEMBLE |  | 2 | 600
30

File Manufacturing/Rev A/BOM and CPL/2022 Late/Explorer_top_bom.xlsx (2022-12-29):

Comment | Designator | Footprint | LCSC Part #
 | D2 D3 D4 D5 D6 D7 D8 D9 D10 D11 D12 D13 | LED-0603 | C2286
 | D14 | LED-0805 | C2296
 | J1 J9 | 1X04_1MM_JST_SH | C145956
 | J2 J3 | 1X20P_FEMALE | C50984
 | S2 | SWITCH_DPDT_SMD_AYZ0202 | C318998
1k | R1 R15 R16 R17 R18 R19 R20 R21 R22 R23 R24 R25 R26 | RES-0603 | C21190
3M3 | R3 R4 R5 R6 R7 R8 R9 R10 R11 R12 R13 R14 | RES-0603 | C26096
10k | R27 R28 R29 R30 | RES-0603 | C25804
BSS138 | Q1 Q2 Q3 Q4 Q5 Q6 Q7 Q8 Q9 Q10 Q11 Q12 Q13 Q14 | SOT23-3 | C435876
SKRKAEE020 | WIFI-BOOT | SW2-2.6-3.9X2.9X1.5+0.4MM | C455280
 | J5 | 1X10P_FEMALE | C35445
 | J6 J7 | 1X8P_FEMALE | C27438
 | J8 | 1X6P_FEMALE | C40877

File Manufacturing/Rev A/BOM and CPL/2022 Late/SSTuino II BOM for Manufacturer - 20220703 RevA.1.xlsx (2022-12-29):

Customer's Name: |  | FourierIndustries LLP
PCB part No.: |  | SSTuino_II_2021-12-26
Date of updating: |  | 2022-07-03 |  |  |  | Qty of PCBA: | 250 | Pcs
 | Please note:
 | 1. This is only example of BOM list. Customer should followed by your own design to fill in information of components which in gray color in below list.
 | 2. The basic information of components must fill up, such as designator, value, MFG part No. and quantity.
 | 3. Please prived "MFG part No." or Order Code, which will avoid misunderstanding or mis-order. (The Order Code can be from Element14, Digi-Key, Mouser or RS)
 | 4. Red highlight means that this source is out of stock
S/N | Designator * | Comment/ value* | Footprint | Comment | MFG part No. * | Qty(per PCB)* | Qty(Total) | Digi-key order code | Element14 order code | Mouser Order Code | LCSC Order Code | RS Order Code
1 | C1 C4 C7 C8 C9 C11 | 0.1uF | CAPC1005X60 | Can replace w/ equivalent to save costs | CL05B104KO5NNNC | 6 | 1500 |  |  |  | C1525
2 | R7 | 1k | RESC1005X40 | Can replace w/ equivalent to save costs | 0402WGF1001TCE | 1 | 250 |  |  |  | C11702
3 | R10 | 1k | RESPACK_4X0402 | Can replace w/ equivalent to save costs | 4D02WGJ0102TCE | 1 | 250 |  |  |  | C25726
4 | C6 | 1uF | CAPC1005X60 | Can replace w/ equivalent to save costs | CL05A105KA5NQNC | 1 | 250 |  |  |  | C52923
5 | R4 R5 R11 R12 R13 | 4.7k | RESC1005X40 | Can replace w/ equivalent to save costs | 0402WGF4701TCE | 5 | 1250 |  |  |  | C25900
6 | R14 R15 | 4.7k | RESPACK_4X0402 | Can replace w/ equivalent to save costs | 4D02WGJ0472TCE | 2 | 500 |  |  |  | C29586
7 | C10 C12 | 4.7uF | CAPC1005X60 | Can replace w/ equivalent to save costs | CL05A475MP5NRNC | 2 | 500 |  |  |  | C23733
8 | R1 R2 | 5.1k | RESC1005X40 | Can replace w/ equivalent to save costs | 0402WGF5101TCE | 2 | 500 |  |  |  | C25905
9 | F1 | 6V/0.75A | 1206 |  | 1206L075THYR | 1 | 250 |  |  |  | C99563
10 | R6 R8 | 10k | RESC1005X40 | Can replace w/ equivalent to save costs | 0402WGF1002TCE | 2 | 500 |  |  |  | C25744
11 | C2 C3 | 10uF | CAPC1608X85 | Can replace w/ equivalent to save costs | CL10A106KP8NNNC | 2 | 500 |  |  |  | C19702
12 | R9 | 12k | RESC1005X40 | Can replace w/ equivalent to save costs | 0402WGF1202TCE | 1 | 250 |  |  |  | C25752
13 | U5 | SN74AHC1G125DBVR | SOT23-5L |  | SN74AHC1G125DBVR | 1 | 250 | 74AHC1G125W5-7DICT-ND |  |  | C7468
14 | U4 | 74HC4050 | TSSOP16 | Provided by customer | CD74HC4050PWR | 1 | 250 | 296-9215-1-ND |  |  | C352825
15 | R3 | 100k | RESC1005X40 | Can replace w/ equivalent to save costs | 0402WGF1003TCE | 1 | 250 |  |  |  | C25741
16 | C5 | 100uF | CAPC3216X135 | Can replace w/ equivalent to save costs | CL31A107MQHNNNE | 1 | 250 |  |  |  | C15008
17 | D1 | 5050 SMD LED | LED-TRICOLOR-5050 |  | TC5050RGBF08-3CJH-AF53A | 1 | 250 |  |  |  | C784540
18 | VR1 | AMS1117-3.3 | SOT230P696X180-4N |  | AMS1117-3.3 | 1 | 250 |  |  |  | C6186
19 | U3 | ATSAMD11D14A-SSNT | SOIC127P1030X265-20N | Provided by customer |  | 1 | 250 |  |  |  | C614858
20 | Q1 Q3 | NX138AKSX | ARDUINO-TRANSISTORS_SOT363 | Provided by customer | NX138AKSX | 2 | 500 | 1727-2732-2-ND |  |  | C2912548
21 | Q2 Q4 | BSS138PW | SOT65P210X110-3N |  | BSS138W-7-F | 2 | 500 |  |  |  | C24553
22 | U2 | ESP32-WROOM-32E(4MB) | ESP-32S | Provided by customer | ESP32-WROOM-32E(4MB) | 1 | 250 |  |  |  | C701341
23 | U1 | MEGA4809 | TQFP48 | Provided by customer |  | 1 | 250 |  |  |  | C189475
24 | Z1 | TPUSBLC6-2SC6 | SOT95P280X110-6N |  | TPUSBLC6-2SC6 | 1 | 250 |  |  |  | C558442
25 | RESET | TS-1088-AR02016 | SW2-2.6-3.9X2.9X1.5+0.4MM |  | TS-1088-AR02016 | 1 | 250 |  |  |  | C720477
26 | J1 | TYPE-C-31-M-12 | HRO_TYPE-C-31-M-12 |  | TYPE-C-31-M-12 | 1 | 250 |  |  |  | C165948
27 | LED | YELLOW | LED-0603 |  | 19-213/Y2C-CQ2R2L/3T(CY) | 1 | 250 |  |  |  | C72038
28 | J2 J3 | 1X20P | 1x20P Stacking Headers | Provided by customer in mid-Aug 2022 |  | 2 | 500
29 | SPI | JST SH 4P | BOOMELE(Boom Precision Elec) C145956 |  |  | 1 | 250 |  |  |  | C145956
30

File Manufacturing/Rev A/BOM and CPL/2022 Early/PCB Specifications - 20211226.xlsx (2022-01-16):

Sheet: Fabrication Capability
Please note 1 | This excel including two sheets; Please make sure the Gerber followed the "fabrication capability" sheet before filling this "Requirements" sheet.
Please note 2 | "Requirements" sheet is used for quotation only, PCB factory side will do futher check and provide the DFM before proceed fabrication.(If have)
Fast Prototype Sample(IPC Class I) PCB Fabrication
Items |  | Technical Parameter
Layer number |  | 1-6 Layer
Type of dielectric material |  | FR-4
Board thickness |  | 0.4mm - 2.0mm
Outer layer copper thickness |  | 1-2 oz
Inter layer copper thickness |  | 0.5 oz
Min trace width/space |  | 0.1524mm (6mil)
Min via diameter |  | 0.3mm
Min via ring |  | 0.153mm（6mil）
 | Board thickness | ± 10%
Tolerance | Line width | Line Width ±20％
 | Hole Diameter | PTH±0.05mm (2mil) | NPTH±0.075mm (3mil)
Surface treating technic of pad |  | Tin / Gold immersion / HAL(Osp)
IPC Class II & III PCB Fabrication
Items |  | Technical Parameter
Layer number |  | 1-68 Layer
Type of dielectric material |  | FR4(Tg135, 150, 160, 170, 180, 190); Alu-based; Cu-based; Rogers; Ceramic; Isola; Tacolnic, Teflon, Panasonic, EM, Flex; Rigid-Flex etc;
Mini board thickness |  | 0.1mm(1 layer FPC) / 0.2mm (2 layers) / 0.4mm (4 layers) / 0.9mm(8 layers) / 1.2mm (10 layers) / 1.3mm (12 layers) / 1.5mm (14 layers) / 1.7mm (16 layers) / 1.8mm / 2.0 mm (18 layers) / 2.2mm (20 layers) / 2.4mm ( 22 layers) / 2.6mm (24 layers)
Max copper thickness (Outer layer) |  | 19 OZ
Max copper thickness (Inter layer) |  | 12 OZ
Min inter layer trace width/space(mil) |  | 2.5mil
Min outer layer trace width/space(mil) |  | 2.5mil
Min drilling diameter |  | 0.05mm
 | Hole position | ±0.05mm (2mil)
Tolerance | Line width | ± 0.1mm (4mil)
 | Diameter | PTH: ±0.05mm (2mil) | NPTH: ±0.025mm (1mil)
Surface treating technic of pad |  | Lead Tin / Lead-free / Gold immersion / Soft bonding gold / HAL(Osp)
Surface Treatment | Nickel Thickness | Au Thickness | Palladium Thickness | Total Thickness
 |  | Thickness | Thickness
Gold Immersion(ENIG) | 100-120u'' | 2u'' |  | 2.55-3.05um
Gold Plating | 120u'' | 2-50u'' |  | 3.05-4.25um
Soft Bonding Gold | 120u'' | 3-20u'' |  | 3.075-3.5um
ENEPIG | 120-320u'' | 2-4u'' | 2-6u'' | 3.1-8.25um
1um=40u''
Stencil Size |  |  | Stencil Thickness
S/N | Stencil Size | PCB Size
#Type A | 37*47cm | 19*29cm | if <=0402 components, stencil use 0.1mm; if >=0603 components stencil use 0.15mm
#Type B | 42*52cm | 24*34cm
#Type C | 45*55cm | 27*37cm
#Type D | 55*65cm | 37*47cm
#Type E | 58.4*58.4cm | 40*40cm

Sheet: Requirements
MPN TECH PTE. LTD.
PCB, Assembly and Components Technical Requirements
Supplier： |  | MPN Tech Pte. Ltd. |  |  |  |  |  |  |  |  |  |  |  | MPN Ref No.:
Buyer: |  | FourierIndustries LLP |  |  |  |  |  |  |  |  |  |  |  | Your Ref No.:
Name: |  | Mr. Pan Ziyue |  |  |  |  |  |  |  |  |  |  |  | Date: | 2021-12-27
Please note 1 |  | This excel including two sheets; Please make sure the Gerber followed the "fabrication capability" sheet before filling this "Requirements" sheet.
Please note 2 |  | "Requirements" sheet is used for quotation only, our PCB factory side will do futher check and provide the DFM before proceed fabrication.(If have).
PCB file name |  | PCB Requirements |  |  |  |  |  |  |  |  |  |  |  |  |  |  |  |  |  |  |  |  |  | Assembly Requirements(Singapore Local Machine Assembly)
 |  | Size (mm) Width*Height | Board Material | Tg Standard | Board Thickness (mm) | Layers | Copper Thickness (OZ) |  | Surface Treatment (Finishing) | Minimum Via size (mm) | Minimum trace width/space (mil) | Blind / bury holes | Stack up/Layer Sequence (>=4 layer PCB) | Other Techniques requirement 1 | Other Techniques requirement 2 (If needed) | Other Techniques requirement 3 (If needed) | Solder Mask | Legend Color | Solder mask tenting | Fabrication IPC standard | Need PCB fabrication Report? (Sample PCB will not provide) | PCB Qty (pcs) | Standard or Expedite Process | PCB Assembly Qty (pcs) | Include 0201/BGA/LGA components? | Stencil for PCB Assembly | Assembly Standard | Standard or Expedite Process | Need MPN to purchase components ?
 |  |  |  |  |  |  | Outer layers | Inter layers (only for multi-layer PCB )
1 | SSTuino_II_2021-12-26 | 68.6 * 25.4 | FR-4 | Tg 130-140 | 1.6 | Double | 1oz(35um) | N.A. | Lead-Free HASL | ≥0.3 | ≥6/6mil | No |  | N.A. | N.A. | N.A. | Black | White | Yes | IPC Class 2 |  | 12 | Standard | 12 | No | Yes need standard stencil | RoHS(Lead-Free) | Standard | Yes
2 | SSTuino_II_2021-12-26 | 68.6 * 25.4 | FR-4 | Tg 130-140 | 1.6 | Double | 1oz(35um) | N.A. | Lead-Free HASL | ≥0.3 | ≥6/6mil | No |  | N.A. | N.A. | N.A. | Black | White | Yes | IPC Class 2 |  | 238 | Standard | 238 | No | Yes need standard stencil | RoHS(Lead-Free) | Standard | Yes
3
4
5
6
7 |  | If cell list can't match requirements, please clarify here.
 | Note: | Please specify the proper requirements from the list above
 | Please click the cells to select your requirements.
 |  |  |  |  |  |  |  |  |  |  |  | * |  | Please double click left "icon" to view PCB solder mask tenting sample pic:
 |  |  |  |  |  |  |  |  |  |  |  | ** |  | PCB fabrication including below requirments, need to select IPC Class II or III standard:
 |  |  |  |  |  |  |  |  | 11 |  |  |  |  | - 6 layer PCB and above;
 |  |  |  |  |  |  |  |  |  |  |  |  |  | - PCB with minimum Via size < 0.3mm;
 |  |  |  |  |  |  |  |  |  |  |  |  |  | - PCB with minimum trace width/ space < 6mil;
 |  |  |  |  |  |  |  |  |  |  |  |  |  | - PCB copper thickness more than 2OZ;
#1 | PCB and Assembly expedite arrangement will have extra cost. |  |  |  |  |  |  |  |  |  |  |  |  | - Board thickness lesser than 0.4mm or thicker than 2.0mm;
#2 | Components no expedite services. |  |  |  |  |  |  |  |  |  |  |  |  | - PCB surface treatment as "soft bonding gold";
#3 | Batch PCB recommend IPC Class II or IPC Class III standard fabrication. |  |  |  |  |  |  |  |  |  |  |  |  | - PCB including blind or/and bury holes;
#4 | 1, 2 and 4 layer PCB can do panel fabrication but have limitation. |  |  |  |  |  |  |  |  |  |  |  |  | - Request impedance control;
#4.1 | Panel PCB must have same PCB specs.(material, thickness, surface, IPC standard etc). |  |  |  |  |  |  |  |  |  |  |  |  | - PCB size is more than 50*50 cm.
#5 | IPC Class II and III standard PCB, fabrication lead time will be 5-6 days more than fast prototype fabrication period.
#6 | If PCB assembly including surface mount components(SMD), need to customize stencil;
#7 | If need components order service, MPN TECH can't control the components lead time if any delay from shipping and supplier.

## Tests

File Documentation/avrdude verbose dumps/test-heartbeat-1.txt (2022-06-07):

avrdude: Version 6.3-20201216
         Copyright (c) 2000-2005 Brian Dean, http://www.bdmicro.com/
         Copyright (c) 2007-2014 Joerg Wunsch

         System wide configuration file is "/Users/panziyue/Library/Arduino15/packages/MegaCoreX/hardware/megaavr/1.0.8/avrdude.conf"
         User configuration file is "/Users/panziyue/.avrduderc"
         User configuration file does not exist or is not a regular file, skipping

         Using Port                    : /dev/cu.usbmodem14101
         Using Programmer              : jtag2updi
avrdude: jtagmkII_open_pdi()
avrdude: jtagmkII_getsync()
avrdude: jtagmkII_getsync(): Sending sign-on command: 
avrdude: jtagmkII_send(): sending 1 bytes
avrdude: Send: . [1b] . [00] . [00] . [01] . [00] . [00] . [00] . [0e] . [01] . [f3] . [97] 
avrdude: jtagmkII_recv():
avrdude: Recv: . [1b] 
avrdude: Recv: . [00] 
avrdude: Recv: . [00] 
avrdude: Recv: . [1d] 
avrdude: Recv: . [00] 
avrdude: Recv: . [00] 
avrdude: Recv: . [00] 
avrdude: Recv: . [0e] 
avrdude: Recv: . [86] . [01] . [01] . [07] . [01] . [01] . [01] . [07] . [06] . [01] . [00] . [00] . [00] . [00] . [00] . [00] J [4a] T [54] A [41] G [47] I [49] C [43] E [45]   [20] m [6d] k [6b] I [49] I [49] . [00] 
avrdude: Recv: o [6f] 
avrdude: Recv: V [56] 

avrdude: jtagmkII_recv(): Got message seqno 0 (command_sequence == 0)
avrdude: Recv: . [86] . [01] . [01] . [07] . [01] . [01] . [01] . [07] . [06] . [01] . [00] . [00] . [00] . [00] . [00] . [00] J [4a] T [54] A [41] G [47] I [49] C [43] E [45]   [20] m [6d] k [6b] I [49] I [49] . [00] 

Raw message:
0x86 0x01 0x01 0x07 0x01 0x01 0x01 0x07 0x06 0x01 0x00 0x00 0x00 0x00 0x00 0x00
0x4a 0x54 0x41 0x47 0x49 0x43 0x45 0x20 0x6d 0x6b 0x49 0x49 0x00 
Sign-on succeeded

JTAG ICE mkII sign-on message:
Communications protocol version: 1
M_MCU:
  boot-loader FW version:        1
  firmware version:              1.07
  hardware version:              1
S_MCU:
  boot-loader FW version:        1
  firmware version:              6.07
  hardware version:              1
Serial number:                   00:00:00:00:00:00
Device ID:                       JTAGICE mkII
avrdude: jtagmkII_getsync(): Using a 298-byte device descriptor
avrdude: jtagmkII_setparm()
avrdude: jtagmkII_setparm(): Sending set parameter command (parm 0x03, 1 bytes): 
avrdude: jtagmkII_send(): sending 3 bytes
avrdude: Send: . [1b] . [01] . [00] . [03] . [00] . [00] . [00] . [0e] . [02] . [03] . [06] $ [24] 1 [31] 
avrdude: jtagmkII_recv():
avrdude: Recv: . [1b] 
avrdude: Recv: . [01] 
avrdude: Recv: . [00] 
avrdude: Recv: . [01] 
avrdude: Recv: . [00] 
avrdude: Recv: . [00] 
avrdude: Recv: . [00] 
avrdude: Recv: . [0e] 
avrdude: Recv: . [80] 
avrdude: Recv: . [cd] 
avrdude: Recv: . [83] 

avrdude: jtagmkII_recv(): Got message seqno 1 (command_sequence == 1)
avrdude: Recv: . [80] 

Raw message:
0x80 
OK

avrdude: jtagmkII_getsync(): Sending get sync command: 
avrdude: jtagmkII_send(): sending 1 bytes
avrdude: Send: . [1b] . [02] . [00] . [01] . [00] . [00] . [00] . [0e] . [0f] . [e2] u [75] 
avrdude: jtagmkII_recv():
avrdude: Recv: . [1b] 
avrdude: Recv: . [02] 
avrdude: Recv: . [00] 
avrdude: Recv: . [01] 
avrdude: Recv: . [00] 
avrdude: Recv: . [00] 
avrdude: Recv: . [00] 
avrdude: Recv: . [0e] 
avrdude: Recv: . [80] 
avrdude: Recv: . [1d] 
avrdude: Recv: . [09] 

avrdude: jtagmkII_recv(): Got message seqno 2 (command_sequence == 2)
avrdude: Recv: . [80] 

Raw message:
0x80 
OK

         AVR Part                      : ATmega4809
         Chip Erase delay              : 0 us
         PAGEL                         : P00
         BS2                           : P00
         RESET disposition             : dedicated
         RETRY pulse                   : SCK
         serial program mode           : yes
         parallel program mode         : yes
         Timeout                       : 0
         StabDelay                     : 0
         CmdexeDelay                   : 0
         SyncLoops                     : 0
         ByteDelay                     : 0
         PollIndex                     : 0
         PollValue                     : 0x00
         Memory Detail                 :

                                  Block Poll               Page                       Polled
           Memory Type Mode Delay Size  Indx Paged  Size   Size #Pages MinW  MaxW   ReadBack
           ----------- ---- ----- ----- ---- ------ ------ ---- ------ ----- ----- ---------
           signature      0     0     0    0 no          3    0      0     0     0 0x00 0x00
                                  Block Poll               Page                       Polled
           Memory Type Mode Delay Size  Indx Paged  Size   Size #Pages MinW  MaxW   ReadBack
           ----------- ---- ----- ----- ---- ------ ------ ---- ------ ----- ----- ---------
           prodsig        0     0     0    0 no         61   61      0     0     0 0x00 0x00
                                  Block Poll               Page                       Polled
           Memory Type Mode Delay Size  Indx Paged  Size   Size #Pages MinW  MaxW   ReadBack
           ----------- ---- ----- ----- ---- ------ ------ ---- ------ ----- ----- ---------
           fuses          0     0     0    0 no          9    0      0     0     0 0x00 0x00
                                  Block Poll               Page                       Polled
           Memory Type Mode Delay Size  Indx Paged  Size   Size #Pages MinW  MaxW   ReadBack
           ----------- ---- ----- ----- ---- ------ ------ ---- ------ ----- ----- ---------
           fuse0          0     0     0    0 no          1    0      0     0     0 0x00 0x00
                                  Block Poll               Page                       Polled
           Memory Type Mode Delay Size  Indx Paged  Size   Size #Pages MinW  MaxW   ReadBack
           ----------- ---- ----- ----- ---- ------ ------ ---- ------ ----- ----- ---------
           fuse1          0     0     0    0 no          1    0      0     0     0 0x00 0x00
                                  Block Poll               Page                       Polled
           Memory Type Mode Delay Size  Indx Paged  Size   Size #Pages MinW  MaxW   ReadBack
           ----------- ---- ----- ----- ---- ------ ------ ---- ------ ----- ----- ---------
           fuse2          0     0     0    0 no          1    0      0     0     0 0x00 0x00
                                  Block Poll               Page                       Polled
           Memory Type Mode Delay Size  Indx Paged  Size   Size #Pages MinW  MaxW   ReadBack
           ----------- ---- ----- ----- ---- ------ ------ ---- ------ ----- ----- ---------
           fuse4          0     0     0    0 no          1    0      0     0     0 0x00 0x00
                                  Block Poll               Page                       Polled
           Memory Type Mode Delay Size  Indx Paged  Size   Size #Pages MinW  MaxW   ReadBack
           ----------- ---- ----- ----- ---- ------ ------ ---- ------ ----- ----- ---------
           fuse5          0     0     0    0 no          1    0      0     0     0 0x00 0x00
                                  Block Poll               Page                       Polled
           Memory Type Mode Delay Size  Indx Paged  Size   Size #Pages MinW  MaxW   ReadBack
           ----------- ---- ----- ----- ---- ------ ------ ---- ------ ----- ----- ---------
           fuse6          0     0     0    0 no          1    0      0     0     0 0x00 0x00
                                  Block Poll               Page                       Polled
           Memory Type Mode Delay Size  Indx Paged  Size   Size #Pages MinW  MaxW   ReadBack
           ----------- ---- ----- ----- ---- ------ ------ ---- ------ ----- ----- ---------
           fuse7          0     0     0    0 no          1    0      0     0     0 0x00 0x00
                                  Block Poll               Page                       Polled
           Memory Type Mode Delay Size  Indx Paged  Size   Size #Pages MinW  MaxW   ReadBack
           ----------- ---- ----- ----- ---- ------ ------ ---- ------ ----- ----- ---------
           fuse8          0     0     0    0 no          1    0      0     0     0 0x00 0x00
                                  Block Poll               Page                       Polled
           Memory Type Mode Delay Size  Indx Paged  Size   Size #Pages MinW  MaxW   ReadBack
           ----------- ---- ----- ----- ---- ------ ------ ---- ------ ----- ----- ---------
           lock           0     0     0    0 no          1    0      0     0     0 0x00 0x00
                                  Block Poll               Page                       Polled
           Memory Type Mode Delay Size  Indx Paged  Size   Size #Pages MinW  MaxW   ReadBack
           ----------- ---- ----- ----- ---- ------ ------ ---- ------ ----- ----- ---------
           data           0     0     0    0 no          0    0      0     0     0 0x00 0x00
                                  Block Poll               Page                       Polled
           Memory Type Mode Delay Size  Indx Paged  Size   Size #Pages MinW  MaxW   ReadBack
           ----------- ---- ----- ----- ---- ------ ------ ---- ------ ----- ----- ---------
           usersig        0     0     0    0 no         64   64      0     0     0 0x00 0x00
                                  Block Poll               Page                       Polled
           Memory Type Mode Delay Size  Indx Paged  Size   Size #Pages MinW  MaxW   ReadBack
           ----------- ---- ----- ----- ---- ------ ------ ---- ------ ----- ----- ---------
           flash          0     0     0    0 no      49152  128      0     0     0 0x00 0x00
                                  Block Poll               Page                       Polled
           Memory Type Mode Delay Size  Indx Paged  Size   Size #Pages MinW  MaxW   ReadBack
           ----------- ---- ----- ----- ---- ------ ------ ---- ------ ----- ----- ---------
           eeprom         0     0     0    0 no        256   64      0     0     0 0x00 0x00

         Programmer Type : JTAGMKII_PDI
         Description     : JTAGv2 to UPDI bridge
avrdude: jtagmkII_getparm()
avrdude: jtagmkII_getparm(): Sending get parameter command (parm 0x01): 
avrdude: jtagmkII_send(): sending 2 bytes
avrdude: Send: . [1b] . [03] . [00] . [02] . [00] . [00] . [00] . [0e] . [03] . [01] . [d3] . [99] 
avrdude: jtagmkII_recv():
avrdude: Recv: . [1b] 
avrdude: Recv: . [03] 
avrdude: Recv: . [00] 
avrdude: Recv: . [03] 
avrdude: Recv: . [00] 
avrdude: Recv: . [00] 
avrdude: Recv: . [00] 
avrdude: Recv: . [0e] 
avrdude: Recv: . [81] . [01] . [01] 
avrdude: Recv: . [ed] 
avrdude: Recv: . [cd] 

avrdude: jtagmkII_recv(): Got message seqno 3 (command_sequence == 3)
avrdude: Recv: . [81] . [01] . [01] 

Raw message:
0x81 0x01 0x01 
parameter values:
0x01  0x01  

avrdude: jtagmkII_getparm()
avrdude: jtagmkII_getparm(): Sending get parameter command (parm 0x02): 
avrdude: jtagmkII_send(): sending 2 bytes
avrdude: Send: . [1b] . [04] . [00] . [02] . [00] . [00] . [00] . [0e] . [03] . [02] . [aa] B [42] 
avrdude: jtagmkII_recv():
avrdude: Recv: . [1b] 
avrdude: Recv: . [04] 
avrdude: Recv: . [00] 
avrdude: Recv: . [05] 
avrdude: Recv: . [00] 
avrdude: Recv: . [00] 
avrdude: Recv: . [00] 
avrdude: Recv: . [0e] 
avrdude: Recv: . [81] . [07] . [01] . [07] . [06] 
avrdude: Recv: . [e6] 
avrdude: Recv: M [4d] 

avrdude: jtagmkII_recv(): Got message seqno 4 (command_sequence == 4)
avrdude: Recv: . [81] . [07] . [01] . [07] . [06] 

Raw message:
0x81 0x07 0x01 0x07 0x06 
parameter values:
0x07  0x01  0x07  0x06  

         M_MCU hardware version: 1
         M_MCU firmware version: 1.07
         S_MCU hardware version: 1
         S_MCU firmware version: 6.07
         Serial number:          00:00:00:00:00:00
avrdude: jtagmkII_getparm()
avrdude: jtagmkII_getparm(): Sending get parameter command (parm 0x06): 
avrdude: jtagmkII_send(): sending 2 bytes
avrdude: Send: . [1b] . [05] . [00] . [02] . [00] . [00] . [00] . [0e] . [03] . [06] s [73] I [49] 
avrdude: jtagmkII_recv():
avrdude: Recv: . [1b] 
avrdude: Recv: . [05] 
avrdude: Recv: . [00] 
avrdude: Recv: . [03] 
avrdude: Recv: . [00] 
avrdude: Recv: . [00] 
avrdude: Recv: . [00] 
avrdude: Recv: . [0e] 
avrdude: Recv: . [81] . [88] . [13] 
avrdude: Recv: x [78] 
avrdude: Recv: M [4d] 

avrdude: jtagmkII_recv(): Got message seqno 5 (command_sequence == 5)
avrdude: Recv: . [81] . [88] . [13] 

Raw message:
0x81 0x88 0x13 
parameter values:
0x88  0x13  

         Vtarget         : 5.0 V
avrdude: jtagmkII_initialize(): trying to set baudrate to 115200
avrdude: jtagmkII_setparm()
avrdude: jtagmkII_setparm(): Sending set parameter command (parm 0x05, 1 bytes): 
avrdude: jtagmkII_send(): sending 3 bytes
avrdude: Send: . [1b] . [06] . [00] . [03] . [00] . [00] . [00] . [0e] . [02] . [05] . [07] . [88] . [b0] 
avrdude: jtagmkII_recv():
avrdude: Recv: . [1b] 
avrdude: Recv: . [06] 
avrdude: Recv: . [00] 
avrdude: Recv: . [01] 
avrdude: Recv: . [00] 
avrdude: Recv: . [00] 
avrdude: Recv: . [00] 
avrdude: Recv: . [0e] 
avrdude: Recv: . [80] 
avrdude: Recv: . [c3] 
avrdude: Recv: . [1f] 

avrdude: jtagmkII_recv(): Got message seqno 6 (command_sequence == 6)
avrdude: Recv: . [80] 

Raw message:
0x80 
OK

avrdude: jtagmkII_set_devdescr(): Sending set device descriptor command: 
avrdude: jtagmkII_send(): sending 299 bytes
avrdude: Send: . [1b] . [07] . [00] + [2b] . [01] . [00] . [00] . [0e] . [0c] . [00] . [00] . [00] . [00] . [00] . [00] . [00] . [00] . [00] . [00] . [00] . [00] . [00] . [00] . [00] . [00] . [00] . [00] . [00] . [00] . [00] . [00] . [00] . [00] . [00] . [00] . [00] . [00] . [00] . [00] . [00] . [00] . [00] . [00] . [00] . [00] . [00] . [00] . [00] . [00] . [00] . [00] . [00] . [00] . [00] . [00] . [00] . [00] . [00] . [00] . [00] . [00] . [00] . [00] . [00] . [00] . [00] . [00] . [00] . [00] . [00] . [00] . [00] . [00] . [00] . [00] . [00] . [00] . [00] . [00] . [00] . [00] . [00] . [00] . [00] . [00] . [00] . [00] . [00] . [00] . [00] . [00] . [00] . [00] . [00] . [00] . [00] . [00] . [00] . [00] . [00] . [00] . [00] . [00] . [00] . [00] . [00] . [00] . [00] . [00] . [00] . [00] . [00] . [00] . [00] . [00] . [00] . [00] . [00] . [00] . [00] . [00] . [00] . [00] . [00] . [00] . [00] . [00] . [00] . [00] . [00] . [00] . [00] . [00] . [00] . [00] . [00] . [00] . [00] . [00] . [00] . [00] . [00] . [00] . [00] . [00] . [00] . [00] . [00] . [00] . [00] . [00] . [00] . [00] . [00] . [00] . [00] . [00] . [00] . [00] . [00] . [00] . [00] . [00] . [00] . [00] . [00] . [00] . [00] . [00] . [00] . [00] . [00] . [00] . [00] . [00] . [00] . [00] . [00] . [00] . [00] . [00] . [00] . [00] . [00] . [00] . [00] . [00] . [00] . [00] . [00] . [00] . [00] . [00] . [00] . [00] . [00] . [00] . [00] . [00] . [00] . [00] . [00] . [00] . [00] . [00] . [00] . [00] . [00] . [00] . [00] . [00] . [00] . [00] . [00] . [00] . [00] . [00] . [00] . [00] . [00] . [00] . [00] . [00] . [00] . [00] . [00] . [00] . [00] . [00] . [00] . [00] . [00] . [00] . [00] . [00] . [00] . [00] . [00] . [00] . [00] . [00] . [00] . [00] . [00] . [00] . [00] . [00] . [00] . [00] . [00] . [00] . [00] . [80] . [00] @ [40] . [00] . [00] . [00] . [00] . [00] . [00] . [00] . [c0] . [00] . [00] . [00] . [00] . [00] . [00] . [00] . [00] . [00] . [00] . [00] . [00] . [00] . [00] . [00] . [00] . [00] . [00] . [00] . [00] . [00] . [00] . [00] . [00] . [00] . [00] . [00] . [80] . [01] . [00] . [00] . [00] . [00] . [00] . [01] . [02] . [00] . [00] . [00] . [00] . [00] . [00] . [00] . [00] . [e8] . [c8] 
avrdude: jtagmkII_recv():
avrdude: Recv: . [1b] 
avrdude: Recv: . [07] 
avrdude: Recv: . [00] 
avrdude: Recv: . [01] 
avrdude: Recv: . [00] 
avrdude: Recv: . [00] 
avrdude: Recv: . [00] 
avrdude: Recv: . [0e] 
avrdude: Recv: . [80] 
avrdude: Recv: | [7c] 
avrdude: Recv: . [9e] 

avrdude: jtagmkII_recv(): Got message seqno 7 (command_sequence == 7)
avrdude: Recv: . [80] 

Raw message:
0x80 
OK

avrdude: jtagmkII_initialize(): Cannot locate "flash" and "boot" memories in description
avrdude: jtagmkII_reset(): Sending reset command: 
avrdude: jtagmkII_send(): sending 2 bytes
avrdude: Send: . [1b] . [08] . [00] . [02] . [00] . [00] . [00] . [0e] . [0b] . [01] . [de] . [fe] 
avrdude: jtagmkII_recv():
avrdude: Recv: . [1b] 
avrdude: Recv: . [08] 
avrdude: Recv: . [00] 
avrdude: Recv: . [01] 
avrdude: Recv: . [00] 
avrdude: Recv: . [00] 
avrdude: Recv: . [00] 
avrdude: Recv: . [0e] 
avrdude: Recv: . [80] 
avrdude: Recv: . [ce] 
avrdude: Recv: / [2f] 

avrdude: jtagmkII_recv(): Got message seqno 8 (command_sequence == 8)
avrdude: Recv: . [80] 

Raw message:
0x80 
OK

avrdude: jtagmkII_read_byte(.., signature, 0x0, ...)
avrdude: jtagmkII_program_enable(): Sending enter progmode command: 
avrdude: jtagmkII_send(): sending 1 bytes
avrdude: Send: . [1b] . [09] . [00] . [01] . [00] . [00] . [00] . [0e] . [14] . [dc] | [7c] 
avrdude: jtagmkII_recv():
avrdude: Recv: . [1b] 
avrdude: Recv: . [09] 
avrdude: Recv: . [00] 
avrdude: Recv: . [01] 
avrdude: Recv: . [00] 
avrdude: Recv: . [00] 
avrdude: Recv: . [00] 
avrdude: Recv: . [0e] 
avrdude: Recv: . [80] 
avrdude: Recv: q [71] 
avrdude: Recv: . [ae] 

avrdude: jtagmkII_recv(): Got message seqno 9 (command_sequence == 9)
avrdude: Recv: . [80] 

Raw message:
0x80 
OK

avrdude: jtagmkII_program_enable(): Sending enter progmode command: 
avrdude: jtagmkII_send(): sending 1 bytes
avrdude: Send: . [1b] . [0a] . [00] . [01] . [00] . [00] . [00] . [0e] . [14] . [0c] . [f6] 
avrdude: jtagmkII_recv():
avrdude: Recv: . [1b] 
avrdude: Recv: . [0a] 
avrdude: Recv: . [00] 
avrdude: Recv: . [01] 
avrdude: Recv: . [00] 
avrdude: Recv: . [00] 
avrdude: Recv: . [00] 
avrdude: Recv: . [0e] 
avrdude: Recv: . [80] 
avrdude: Recv: . [a1] 
avrdude: Recv: $ [24] 

avrdude: jtagmkII_recv(): Got message seqno 10 (command_sequence == 10)
avrdude: Recv: . [80] 

Raw message:
0x80 
OK

avrdude: jtagmkII_read_byte(): Sending read memory command: 
avrdude: jtagmkII_send(): sending 10 bytes
avrdude: Send: . [1b] . [0b] . [00] . [0a] . [00] . [00] . [00] . [0e] . [05] . [b4] . [01] . [00] . [00] . [00] . [00] . [11] . [00] . [00] . [1a] . [d4] 
avrdude: jtagmkII_recv():
avrdude: Recv: . [1b] 
avrdude: Recv: . [0b] 
avrdude: Recv: . [00] 
avrdude: Recv: . [02] 
avrdude: Recv: . [00] 
avrdude: Recv: . [00] 
avrdude: Recv: . [00] 
avrdude: Recv: . [0e] 
avrdude: Recv: . [82] . [1e] 
avrdude: Recv: { [7b] 
avrdude: Recv: . [9b] 

avrdude: jtagmkII_recv(): Got message seqno 11 (command_sequence == 11)
avrdude: Recv: . [82] . [1e] 

Raw message:
0x82 0x1e 
memory contents:
0x1e  

avrdude: jtagmkII_read_byte(.., signature, 0x1, ...)
avrdude: jtagmkII_read_byte(): Sending read memory command: 
avrdude: jtagmkII_send(): sending 10 bytes
avrdude: Send: . [1b] . [0c] . [00] . [0a] . [00] . [00] . [00] . [0e] . [05] . [b4] . [01] . [00] . [00] . [00] . [01] . [11] . [00] . [00] . [8c] . [b8] 
avrdude: jtagmkII_recv():
avrdude: Recv: . [1b] 
avrdude: Recv: . [0c] 
avrdude: Recv: . [00] 
avrdude: Recv: . [02] 
avrdude: Recv: . [00] 
avrdude: Recv: . [00] 
avrdude: Recv: . [00] 
avrdude: Recv: . [0e] 
avrdude: Recv: . [82] . [96] 
avrdude: Recv: . [d9] 
avrdude: Recv: z [7a] 

avrdude: jtagmkII_recv(): Got message seqno 12 (command_sequence == 12)
avrdude: Recv: . [82] . [96] 

Raw message:
0x82 0x96 
memory contents:
0x96  

avrdude: jtagmkII_read_byte(.., signature, 0x2, ...)
avrdude: jtagmkII_read_byte(): Sending read memory command: 
avrdude: jtagmkII_send(): sending 10 bytes
avrdude: Send: . [1b] . [0d] . [00] . [0a] . [00] . [00] . [00] . [0e] . [05] . [b4] . [01] . [00] . [00] . [00] . [02] . [11] . [00] . [00] N [4e] . [8d] 
avrdude: jtagmkII_recv():
avrdude: Recv: . [1b] 
avrdude: Recv: . [0d] 
avrdude: Recv: . [00] 
avrdude: Recv: . [02] 
avrdude: Recv: . [00] 
avrdude: Recv: . [00] 
avrdude: Recv: . [00] 
avrdude: Recv: . [0e] 
avrdude: Recv: . [82] Q [51] 
avrdude: Recv: . [97] 
avrdude: Recv: . [85] 

avrdude: jtagmkII_recv(): Got message seqno 13 (command_sequence == 13)
avrdude: Recv: . [82] Q [51] 

Raw message:
0x82 0x51 
memory contents:
0x51  

avrdude: jtagmkII_chip_erase(): Sending Xmega chip erase command: 
avrdude: jtagmkII_send(): sending 6 bytes
avrdude: Send: . [1b] . [0e] . [00] . [06] . [00] . [00] . [00] . [0e] 4 [34] . [00] . [00] . [00] . [00] . [00] . [b3] x [78] 
avrdude: jtagmkII_recv():
avrdude: Recv: . [1b] 
avrdude: Recv: . [0e] 
avrdude: Recv: . [00] 
avrdude: Recv: . [01] 
avrdude: Recv: . [00] 
avrdude: Recv: . [00] 
avrdude: Recv: . [00] 
avrdude: Recv: . [0e] 
avrdude: Recv: . [80] 
avrdude: Recv: . [7f] 
avrdude: Recv: 2 [32] 

avrdude: jtagmkII_recv(): Got message seqno 14 (command_sequence == 14)
avrdude: Recv: . [80] 

Raw message:
0x80 
OK

avrdude: jtagmkII_paged_write(.., flash, 128, 128)
avrdude: jtagmkII_paged_write(): block_size at addr 0 is 128
avrdude: jtagmkII_paged_write(): Sending write memory command: 
avrdude: jtagmkII_send(): sending 138 bytes
avrdude: Send: . [1b] . [0f] . [00] . [8a] . [00] . [00] . [00] . [0e] . [04] . [c0] . [80] . [00] . [00] . [00] . [00] @ [40] . [00] . [00] . [0c] . [94] P [50] . [00] . [0c] . [94] b [62] . [00] . [0c] . [94] b [62] . [00] . [0c] . [94] b [62] . [00] . [0c] . [94] b [62] . [00] . [0c] . [94] b [62] . [00] . [0c] . [94] b [62] . [00] . [0c] . [94] b [62] . [00] . [0c] . [94] b [62] . [00] . [0c] . [94] b [62] . [00] . [0c] . [94] b [62] . [00] . [0c] . [94] b [62] . [00] . [0c] . [94] b [62] . [00] . [0c] . [94] b [62] . [00] . [0c] . [94] b [62] . [00] . [0c] . [94] b [62] . [00] . [0c] . [94] b [62] . [00] . [0c] . [94] b [62] . [00] . [0c] . [94] b [62] . [00] . [0c] . [94] b [62] . [00] . [0c] . [94] b [62] . [00] . [0c] . [94] b [62] . [00] . [0c] . [94] b [62] . [00] . [0c] . [94] b [62] . [00] . [0c] . [94] b [62] . [00] . [0c] . [94] b [62] . [00] . [0c] . [94] b [62] . [00] . [0c] . [94] b [62] . [00] . [0c] . [94] b [62] . [00] . [0c] . [94] b [62] . [00] . [0c] . [94] b [62] . [00] . [0c] . [94] b [62] . [00] r [72] e [65] 
avrdude: jtagmkII_recv():
avrdude: Recv: . [1b] 
avrdude: Recv: . [0f] 
avrdude: Recv: . [00] 
avrdude: Recv: . [01] 
avrdude: Recv: . [00] 
avrdude: Recv: . [00] 
avrdude: Recv: . [00] 
avrdude: Recv: . [0e] 
avrdude: Recv: . [80] 
avrdude: Recv: . [c0] 
avrdude: Recv: . [b3] 

avrdude: jtagmkII_recv(): Got message seqno 15 (command_sequence == 15)
avrdude: Recv: . [80] 

Raw message:
0x80 
OK
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

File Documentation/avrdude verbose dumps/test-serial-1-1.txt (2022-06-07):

$ arduino-cli compile --upload -p $DEVICE --fqbn "MegaCoreX:megaavr:4809:pinout=uno-wifi" --build-property clock=internal_16MHz --build-property bootloader=no_bootloader --build-property BOD=2v6 SerialNINAPassthrough

Sketch uses 3428 bytes (6%) of program storage space. Maximum is 49152 bytes.
Global variables use 323 bytes (5%) of dynamic memory, leaving 5821 bytes for local variables. Maximum is 6144 bytes.
"/Users/panziyue/Library/Arduino15/packages/arduino/tools/avrdude/6.3.0-arduino18/bin/avrdude" "-C/Users/panziyue/Library/Arduino15/packages/MegaCoreX/hardware/megaavr/1.0.8/avrdude.conf" -v -V -patmega4809 -cjtag2updi -P/dev/cu.usbmodem14101 -e "-Uflash:w:/private/var/folders/dx/mwn31wlj3db_q1112jfbg5qc0000gn/T/arduino-sketch-04E22168BB4D031D6D209DA77BD741B7/SerialNINAPassthrough.ino.hex:i" "-Ufuse0:w:0x00:m" "-Ufuse1:w:0x54:m" "-Ufuse2:w:0x01:m" "-Ufuse4:w:0x00:m" "-Ufuse5:w:0xC9:m" "-Ufuse6:w:0x06:m" "-Ufuse7:w:0x00:m" "-Ufuse8:w:0x00:m" "-Ulock:w:0xC5:m" -vvvv

avrdude: Version 6.3-20201216
         Copyright (c) 2000-2005 Brian Dean, http://www.bdmicro.com/
         Copyright (c) 2007-2014 Joerg Wunsch

         System wide configuration file is "/Users/panziyue/Library/Arduino15/packages/MegaCoreX/hardware/megaavr/1.0.8/avrdude.conf"
         User configuration file is "/Users/panziyue/.avrduderc"
         User configuration file does not exist or is not a regular file, skipping

         Using Port                    : /dev/cu.usbmodem14101
         Using Programmer              : jtag2updi
avrdude: jtagmkII_open_pdi()
avrdude: jtagmkII_getsync()
avrdude: jtagmkII_getsync(): Sending sign-on command: 
avrdude: jtagmkII_send(): sending 1 bytes
avrdude: Send: . [1b] . [00] . [00] . [01] . [00] . [00] . [00] . [0e] . [01] . [f3] . [97] 
avrdude: jtagmkII_recv():
avrdude: Recv: . [1b] 
avrdude: Recv: . [00] 
avrdude: Recv: . [00] 
avrdude: Recv: . [1d] 
avrdude: Recv: . [00] 
avrdude: Recv: . [00] 
avrdude: Recv: . [00] 
avrdude: Recv: . [0e] 
avrdude: Recv: . [86] . [01] . [01] . [07] . [01] . [01] . [01] . [07] . [06] . [01] . [00] . [00] . [00] . [00] . [00] . [00] J [4a] T [54] A [41] G [47] I [49] C [43] E [45]   [20] m [6d] k [6b] I [49] I [49] . [00] 
avrdude: Recv: o [6f] 
avrdude: Recv: V [56] 

avrdude: jtagmkII_recv(): Got message seqno 0 (command_sequence == 0)
avrdude: Recv: . [86] . [01] . [01] . [07] . [01] . [01] . [01] . [07] . [06] . [01] . [00] . [00] . [00] . [00] . [00] . [00] J [4a] T [54] A [41] G [47] I [49] C [43] E [45]   [20] m [6d] k [6b] I [49] I [49] . [00] 

Raw message:
0x86 0x01 0x01 0x07 0x01 0x01 0x01 0x07 0x06 0x01 0x00 0x00 0x00 0x00 0x00 0x00
0x4a 0x54 0x41 0x47 0x49 0x43 0x45 0x20 0x6d 0x6b 0x49 0x49 0x00 
Sign-on succeeded

JTAG ICE mkII sign-on message:
Communications protocol version: 1
M_MCU:
  boot-loader FW version:        1
  firmware version:              1.07
  hardware version:              1
S_MCU:
  boot-loader FW version:        1
  firmware version:              6.07
  hardware version:              1
Serial number:                   00:00:00:00:00:00
Device ID:                       JTAGICE mkII
avrdude: jtagmkII_getsync(): Using a 298-byte device descriptor
avrdude: jtagmkII_setparm()
avrdude: jtagmkII_setparm(): Sending set parameter command (parm 0x03, 1 bytes): 
avrdude: jtagmkII_send(): sending 3 bytes
avrdude: Send: . [1b] . [01] . [00] . [03] . [00] . [00] . [00] . [0e] . [02] . [03] . [06] $ [24] 1 [31] 
avrdude: jtagmkII_recv():
avrdude: Recv: . [1b] 
avrdude: Recv: . [01] 
avrdude: Recv: . [00] 
avrdude: Recv: . [01] 
avrdude: Recv: . [00] 
avrdude: Recv: . [00] 
avrdude: Recv: . [00] 
avrdude: Recv: . [0e] 
avrdude: Recv: . [80] 
avrdude: Recv: . [cd] 
avrdude: Recv: . [83] 

avrdude: jtagmkII_recv(): Got message seqno 1 (command_sequence == 1)
avrdude: Recv: . [80] 

Raw message:
0x80 
OK

avrdude: jtagmkII_getsync(): Sending get sync command: 
avrdude: jtagmkII_send(): sending 1 bytes
avrdude: Send: . [1b] . [02] . [00] . [01] . [00] . [00] . [00] . [0e] . [0f] . [e2] u [75] 
avrdude: jtagmkII_recv():
avrdude: Recv: . [1b] 
avrdude: Recv: . [02] 
avrdude: Recv: . [00] 
avrdude: Recv: . [01] 
avrdude: Recv: . [00] 
avrdude: Recv: . [00] 
avrdude: Recv: . [00] 
avrdude: Recv: . [0e] 
avrdude: Recv: . [80] 
avrdude: Recv: . [1d] 
avrdude: Recv: . [09] 

avrdude: jtagmkII_recv(): Got message seqno 2 (command_sequence == 2)
avrdude: Recv: . [80] 

Raw message:
0x80 
OK

         AVR Part                      : ATmega4809
         Chip Erase delay              : 0 us
         PAGEL                         : P00
         BS2                           : P00
         RESET disposition             : dedicated
         RETRY pulse                   : SCK
         serial program mode           : yes
         parallel program mode         : yes
         Timeout                       : 0
         StabDelay                     : 0
         CmdexeDelay                   : 0
         SyncLoops                     : 0
         ByteDelay                     : 0
         PollIndex                     : 0
         PollValue                     : 0x00
         Memory Detail                 :

                                  Block Poll               Page                       Polled
           Memory Type Mode Delay Size  Indx Paged  Size   Size #Pages MinW  MaxW   ReadBack
           ----------- ---- ----- ----- ---- ------ ------ ---- ------ ----- ----- ---------
           signature      0     0     0    0 no          3    0      0     0     0 0x00 0x00
                                  Block Poll               Page                       Polled
           Memory Type Mode Delay Size  Indx Paged  Size   Size #Pages MinW  MaxW   ReadBack
           ----------- ---- ----- ----- ---- ------ ------ ---- ------ ----- ----- ---------
           prodsig        0     0     0    0 no         61   61      0     0     0 0x00 0x00
                                  Block Poll               Page                       Polled
           Memory Type Mode Delay Size  Indx Paged  Size   Size #Pages MinW  MaxW   ReadBack
           ----------- ---- ----- ----- ---- ------ ------ ---- ------ ----- ----- ---------
           fuses          0     0     0    0 no          9    0      0     0     0 0x00 0x00
                                  Block Poll               Page                       Polled
           Memory Type Mode Delay Size  Indx Paged  Size   Size #Pages MinW  MaxW   ReadBack
           ----------- ---- ----- ----- ---- ------ ------ ---- ------ ----- ----- ---------
           fuse0          0     0     0    0 no          1    0      0     0     0 0x00 0x00
                                  Block Poll               Page                       Polled
           Memory Type Mode Delay Size  Indx Paged  Size   Size #Pages MinW  MaxW   ReadBack
           ----------- ---- ----- ----- ---- ------ ------ ---- ------ ----- ----- ---------
           fuse1          0     0     0    0 no          1    0      0     0     0 0x00 0x00
                                  Block Poll               Page                       Polled
           Memory Type Mode Delay Size  Indx Paged  Size   Size #Pages MinW  MaxW   ReadBack
           ----------- ---- ----- ----- ---- ------ ------ ---- ------ ----- ----- ---------
           fuse2          0     0     0    0 no          1    0      0     0     0 0x00 0x00
                                  Block Poll               Page                       Polled
           Memory Type Mode Delay Size  Indx Paged  Size   Size #Pages MinW  MaxW   ReadBack
           ----------- ---- ----- ----- ---- ------ ------ ---- ------ ----- ----- ---------
           fuse4          0     0     0    0 no          1    0      0     0     0 0x00 0x00
                                  Block Poll               Page                       Polled
           Memory Type Mode Delay Size  Indx Paged  Size   Size #Pages MinW  MaxW   ReadBack
           ----------- ---- ----- ----- ---- ------ ------ ---- ------ ----- ----- ---------
           fuse5          0     0     0    0 no          1    0      0     0     0 0x00 0x00
                                  Block Poll               Page                       Polled
           Memory Type Mode Delay Size  Indx Paged  Size   Size #Pages MinW  MaxW   ReadBack
           ----------- ---- ----- ----- ---- ------ ------ ---- ------ ----- ----- ---------
           fuse6          0     0     0    0 no          1    0      0     0     0 0x00 0x00
                                  Block Poll               Page                       Polled
           Memory Type Mode Delay Size  Indx Paged  Size   Size #Pages MinW  MaxW   ReadBack
           ----------- ---- ----- ----- ---- ------ ------ ---- ------ ----- ----- ---------
           fuse7          0     0     0    0 no          1    0      0     0     0 0x00 0x00
                                  Block Poll               Page                       Polled
           Memory Type Mode Delay Size  Indx Paged  Size   Size #Pages MinW  MaxW   ReadBack
           ----------- ---- ----- ----- ---- ------ ------ ---- ------ ----- ----- ---------
           fuse8          0     0     0    0 no          1    0      0     0     0 0x00 0x00
                                  Block Poll               Page                       Polled
           Memory Type Mode Delay Size  Indx Paged  Size   Size #Pages MinW  MaxW   ReadBack
           ----------- ---- ----- ----- ---- ------ ------ ---- ------ ----- ----- ---------
           lock           0     0     0    0 no          1    0      0     0     0 0x00 0x00
                                  Block Poll               Page                       Polled
           Memory Type Mode Delay Size  Indx Paged  Size   Size #Pages MinW  MaxW   ReadBack
           ----------- ---- ----- ----- ---- ------ ------ ---- ------ ----- ----- ---------
           data           0     0     0    0 no          0    0      0     0     0 0x00 0x00
                                  Block Poll               Page                       Polled
           Memory Type Mode Delay Size  Indx Paged  Size   Size #Pages MinW  MaxW   ReadBack
           ----------- ---- ----- ----- ---- ------ ------ ---- ------ ----- ----- ---------
           usersig        0     0     0    0 no         64   64      0     0     0 0x00 0x00
                                  Block Poll               Page                       Polled
           Memory Type Mode Delay Size  Indx Paged  Size   Size #Pages MinW  MaxW   ReadBack
           ----------- ---- ----- ----- ---- ------ ------ ---- ------ ----- ----- ---------
           flash          0     0     0    0 no      49152  128      0     0     0 0x00 0x00
                                  Block Poll               Page                       Polled
           Memory Type Mode Delay Size  Indx Paged  Size   Size #Pages MinW  MaxW   ReadBack
           ----------- ---- ----- ----- ---- ------ ------ ---- ------ ----- ----- ---------
           eeprom         0     0     0    0 no        256   64      0     0     0 0x00 0x00

         Programmer Type : JTAGMKII_PDI
         Description     : JTAGv2 to UPDI bridge
avrdude: jtagmkII_getparm()
avrdude: jtagmkII_getparm(): Sending get parameter command (parm 0x01): 
avrdude: jtagmkII_send(): sending 2 bytes
avrdude: Send: . [1b] . [03] . [00] . [02] . [00] . [00] . [00] . [0e] . [03] . [01] . [d3] . [99] 
avrdude: jtagmkII_recv():
avrdude: Recv: . [1b] 
avrdude: Recv: . [03] 
avrdude: Recv: . [00] 
avrdude: Recv: . [03] 
avrdude: Recv: . [00] 
avrdude: Recv: . [00] 
avrdude: Recv: . [00] 
avrdude: Recv: . [0e] 
avrdude: Recv: . [81] . [01] . [01] 
avrdude: Recv: . [ed] 
avrdude: Recv: . [cd] 

avrdude: jtagmkII_recv(): Got message seqno 3 (command_sequence == 3)
avrdude: Recv: . [81] . [01] . [01] 

Raw message:
0x81 0x01 0x01 
parameter values:
0x01  0x01  

avrdude: jtagmkII_getparm()
avrdude: jtagmkII_getparm(): Sending get parameter command (parm 0x02): 
avrdude: jtagmkII_send(): sending 2 bytes
avrdude: Send: . [1b] . [04] . [00] . [02] . [00] . [00] . [00] . [0e] . [03] . [02] . [aa] B [42] 
avrdude: jtagmkII_recv():
avrdude: Recv: . [1b] 
avrdude: Recv: . [04] 
avrdude: Recv: . [00] 
avrdude: Recv: . [05] 
avrdude: Recv: . [00] 
avrdude: Recv: . [00] 
avrdude: Recv: . [00] 
avrdude: Recv: . [0e] 
avrdude: Recv: . [81] . [07] . [01] . [07] . [06] 
avrdude: Recv: . [e6] 
avrdude: Recv: M [4d] 

avrdude: jtagmkII_recv(): Got message seqno 4 (command_sequence == 4)
avrdude: Recv: . [81] . [07] . [01] . [07] . [06] 

Raw message:
0x81 0x07 0x01 0x07 0x06 
parameter values:
0x07  0x01  0x07  0x06  

         M_MCU hardware version: 1
         M_MCU firmware version: 1.07
         S_MCU hardware version: 1
         S_MCU firmware version: 6.07
         Serial number:          00:00:00:00:00:00
avrdude: jtagmkII_getparm()
avrdude: jtagmkII_getparm(): Sending get parameter command (parm 0x06): 
avrdude: jtagmkII_send(): sending 2 bytes
avrdude: Send: . [1b] . [05] . [00] . [02] . [00] . [00] . [00] . [0e] . [03] . [06] s [73] I [49] 
avrdude: jtagmkII_recv():
avrdude: Recv: . [1b] 
avrdude: Recv: . [05] 
avrdude: Recv: . [00] 
avrdude: Recv: . [03] 
avrdude: Recv: . [00] 
avrdude: Recv: . [00] 
avrdude: Recv: . [00] 
avrdude: Recv: . [0e] 
avrdude: Recv: . [81] . [88] . [13] 
avrdude: Recv: x [78] 
avrdude: Recv: M [4d] 

avrdude: jtagmkII_recv(): Got message seqno 5 (command_sequence == 5)
avrdude: Recv: . [81] . [88] . [13] 

Raw message:
0x81 0x88 0x13 
parameter values:
0x88  0x13  

         Vtarget         : 5.0 V
avrdude: jtagmkII_initialize(): trying to set baudrate to 115200
avrdude: jtagmkII_setparm()
avrdude: jtagmkII_setparm(): Sending set parameter command (parm 0x05, 1 bytes): 
avrdude: jtagmkII_send(): sending 3 bytes
avrdude: Send: . [1b] . [06] . [00] . [03] . [00] . [00] . [00] . [0e] . [02] . [05] . [07] . [88] . [b0] 
avrdude: jtagmkII_recv():
avrdude: Recv: . [1b] 
avrdude: Recv: . [06] 
avrdude: Recv: . [00] 
avrdude: Recv: . [01] 
avrdude: Recv: . [00] 
avrdude: Recv: . [00] 
avrdude: Recv: . [00] 
avrdude: Recv: . [0e] 
avrdude: Recv: . [80] 
avrdude: Recv: . [c3] 
avrdude: Recv: . [1f] 

avrdude: jtagmkII_recv(): Got message seqno 6 (command_sequence == 6)
avrdude: Recv: . [80] 

Raw message:
0x80 
OK

avrdude: jtagmkII_set_devdescr(): Sending set device descriptor command: 
avrdude: jtagmkII_send(): sending 299 bytes
avrdude: Send: . [1b] . [07] . [00] + [2b] . [01] . [00] . [00] . [0e] . [0c] . [00] . [00] . [00] . [00] . [00] . [00] . [00] . [00] . [00] . [00] . [00] . [00] . [00] . [00] . [00] . [00] . [00] . [00] . [00] . [00] . [00] . [00] . [00] . [00] . [00] . [00] . [00] . [00] . [00] . [00] . [00] . [00] . [00] . [00] . [00] . [00] . [00] . [00] . [00] . [00] . [00] . [00] . [00] . [00] . [00] . [00] . [00] . [00] . [00] . [00] . [00] . [00] . [00] . [00] . [00] . [00] . [00] . [00] . [00] . [00] . [00] . [00] . [00] . [00] . [00] . [00] . [00] . [00] . [00] . [00] . [00] . [00] . [00] . [00] . [00] . [00] . [00] . [00] . [00] . [00] . [00] . [00] . [00] . [00] . [00] . [00] . [00] . [00] . [00] . [00] . [00] . [00] . [00] . [00] . [00] . [00] . [00] . [00] . [00] . [00] . [00] . [00] . [00] . [00] . [00] . [00] . [00] . [00] . [00] . [00] . [00] . [00] . [00] . [00] . [00] . [00] . [00] . [00] . [00] . [00] . [00] . [00] . [00] . [00] . [00] . [00] . [00] . [00] . [00] . [00] . [00] . [00] . [00] . [00] . [00] . [00] . [00] . [00] . [00] . [00] . [00] . [00] . [00] . [00] . [00] . [00] . [00] . [00] . [00] . [00] . [00] . [00] . [00] . [00] . [00] . [00] . [00] . [00] . [00] . [00] . [00] . [00] . [00] . [00] . [00] . [00] . [00] . [00] . [00] . [00] . [00] . [00] . [00] . [00] . [00] . [00] . [00] . [00] . [00] . [00] . [00] . [00] . [00] . [00] . [00] . [00] . [00] . [00] . [00] . [00] . [00] . [00] . [00] . [00] . [00] . [00] . [00] . [00] . [00] . [00] . [00] . [00] . [00] . [00] . [00] . [00] . [00] . [00] . [00] . [00] . [00] . [00] . [00] . [00] . [00] . [00] . [00] . [00] . [00] . [00] . [00] . [00] . [00] . [00] . [00] . [00] . [00] . [00] . [00] . [00] . [00] . [00] . [00] . [00] . [00] . [00] . [00] . [00] . [00] . [00] . [00] . [00] . [00] . [80] . [00] @ [40] . [00] . [00] . [00] . [00] . [00] . [00] . [00] . [c0] . [00] . [00] . [00] . [00] . [00] . [00] . [00] . [00] . [00] . [00] . [00] . [00] . [00] . [00] . [00] . [00] . [00] . [00] . [00] . [00] . [00] . [00] . [00] . [00] . [00] . [00] . [00] . [80] . [01] . [00] . [00] . [00] . [00] . [00] . [01] . [02] . [00] . [00] . [00] . [00] . [00] . [00] . [00] . [00] . [e8] . [c8] 
avrdude: jtagmkII_recv():
avrdude: Recv: . [1b] 
avrdude: Recv: . [07] 
avrdude: Recv: . [00] 
avrdude: Recv: . [01] 
avrdude: Recv: . [00] 
avrdude: Recv: . [00] 
avrdude: Recv: . [00] 
avrdude: Recv: . [0e] 
avrdude: Recv: . [80] 
avrdude: Recv: | [7c] 
avrdude: Recv: . [9e] 

avrdude: jtagmkII_recv(): Got message seqno 7 (command_sequence == 7)
avrdude: Recv: . [80] 

Raw message:
0x80 
OK
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

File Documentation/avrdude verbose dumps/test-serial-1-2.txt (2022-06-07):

$ arduino-cli compile --upload -p $DEVICE --fqbn "MegaCoreX:megaavr:4809:pinout=uno-wifi" --build-property clock=internal_16MHz --build-property bootloader=no_bootloader --build-property BOD=2v6 SerialNINAPassthrough

Sketch uses 3428 bytes (6%) of program storage space. Maximum is 49152 bytes.
Global variables use 323 bytes (5%) of dynamic memory, leaving 5821 bytes for local variables. Maximum is 6144 bytes.
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

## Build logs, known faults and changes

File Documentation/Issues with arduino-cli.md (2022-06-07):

Original post available at https://github.com/MCUdude/MegaCoreX/issues/143

Hi there,

Thank you for creating this open-source Arduino core! I recently ran into a serious issue with `arduino-cli` and your core and I wasn't quite able to figure out what exactly happened. My environment is as below:

Hardware:
- Custom board with ATmega4809 (internal 16MHz oscillator), SAMD11 acting as UPDI through `jtag2updi`
- MacBook Pro running macOS 12.1

Software:
- Arduino IDE: 1.8.19
- Arduino CLI: 0.21.0 commit 10107d24

I was recently flashing Arduino programs to my prototype units through `arduino-cli` on a Mac with MegaCoreX 1.0.8. I have previously done this many times before and encountered little to no issues. However, I tried flashing an Arduino program through `arduino-cli` today and noticed that while the program uploaded successfully, subsequent programs could not be uploaded - in effect bricking my boards. 

The only difference I noticed with `arduino-cli` was that it was installing an update today, which I thought to be inconsequential.

```
Downloading missing tool builtin:serial-discovery@1.3.2...
builtin:serial-discovery@1.3.2 downloaded                                       
Installing builtin:serial-discovery@1.3.2...
builtin:serial-discovery@1.3.2 installed
Sketch uses 3428 bytes (6%) of program storage space. Maximum is 49152 bytes.
Global variables use 323 bytes (5%) of dynamic memory, leaving 5821 bytes for local variables. Maximum is 6144 bytes.
avrdude: jtagmkII_initialize(): Cannot locate "flash" and "boot" memories in description
avrdude: jtagmkII_reset(): bad response to reset command: RSP_ILLEGAL_MCU_STATE
avrdude: jtagmkII_close(): bad response to sign-off command: RSP_ILLEGAL_MCU_STATE
```

*^ Full console output of the first time it bricked my board ^*

I confirmed this after a second board had the same Arduino program uploaded successfully through Arduino IDE 1.8.19, but was bricked in an identical sequence of events with `arduino-cli`.

The `-vvvv` dump of avrdude is available at [this GitHub gist](https://gist.github.com/d3lta-v/3ed9a9af7f2e65bfcb978f4c68e754a2). By comparison, I also did an avrdude `-vvvv` dump of a known good board [here](https://gist.github.com/d3lta-v/037b3eaa1a266f62e7e05fed128f805f). It was completely identical up until `avrdude: jtagmkII_reset(): Sending reset command:`, at which the reset command was sent. 

The correct sequence of bytes to be received after the reset command is:
```
avrdude: Recv: . [1b]
avrdude: Recv: . [08] 
avrdude: Recv: . [00] 
avrdude: Recv: . [01] 
avrdude: Recv: . [00] 
avrdude: Recv: . [00] 
avrdude: Recv: . [00] 
avrdude: Recv: . [0e] 
avrdude: Recv: . [80] 
avrdude: Recv: . [ce] 
avrdude: Recv: / [2f] 
```

The sequence of bytes I got instead was (refer to arrows for diff):
```
avrdude: Recv: . [1b] 
avrdude: Recv: . [08] 
avrdude: Recv: . [00] 
avrdude: Recv: . [02]        <---
avrdude: Recv: . [00] 
avrdude: Recv: . [00] 
avrdude: Recv: . [00] 
avrdude: Recv: . [0e] 
avrdude: Recv: . [a5] . [83] <---
avrdude: Recv: + [2b]        <---
avrdude: Recv: l [6c]        <---
```

Unfortunately I did not manage to capture the verbose dump of avrdude commands when the board was bricked. I referred to the [JTAGICE MkII protocol spec sheet](http://www.professordan.com/avr/techlib/techlib8/appnotes/pdf_avr/AVR067.pdf) and noted that 0xa5 is "5.2.10 Operation cannot be performed (RSP_ILLEGAL_MCU_STATE)", but the very next byte for the current mode the MCU is in is not documented (0x83).

Weirdly enough, the commands emitted from the Arduino CLI version and the Arduino IDE version were basically the same as far as fuses are concerned (only fuse1 is different as I had a different setting on the IDE). 

Arduino CLI:

```
"/Users/panziyue/Library/Arduino15/packages/arduino/tools/avrdude/6.3.0-arduino18/bin/avrdude" "-C/Users/panziyue/Library/Arduino15/packages/MegaCoreX/hardware/megaavr/1.0.8/avrdude.conf" -v -V -patmega4809 -cjtag2updi -P/dev/cu.usbmodem14101 -e "-Uflash:w:/private/var/folders/dx/mwn31wlj3db_q1112jfbg5qc0000gn/T/arduino-sketch-269C1E9B0F6B6C5D3659CC2C8E76FDFC/QCTest.ino.hex:i" 
"-Ufuse0:w:0x00:m" "-Ufuse1:w:0x54:m" "-Ufuse2:w:0x01:m" "-Ufuse4:w:0x00:m" "-Ufuse5:w:0xC9:m" "-Ufuse6:w:0x06:m" "-Ufuse7:w:0x00:m" "-Ufuse8:w:0x00:m" "-Ulock:w:0xC5:m"
```

Arduino IDE:

```
/Users/panziyue/Library/Arduino15/packages/arduino/tools/avrdude/6.3.0-arduino18/bin/avrdude -C/Users/panziyue/Library/Arduino15/packages/MegaCoreX/hardware/megaavr/1.0.8/avrdude.conf -v -patmega4809 -cjtag2updi -P/dev/cu.usbmodem14101 -e -Uflash:w:/var/folders/dx/mwn31wlj3db_q1112jfbg5qc0000gn/T/arduino_build_131524/QCTest.ino.hex:i 
-Ufuse0:w:0x00:m -Ufuse1:w:0xF4:m -Ufuse2:w:0x01:m -Ufuse4:w:0x00:m -Ufuse5:w:0xC9:m -Ufuse6:w:0x06:m -Ufuse7:w:0x00:m -Ufuse8:w:0x00:m -Ulock:w:0xC5:m
```

At this point I have not tried using an external UPDI compatible programmer to rescue these two devices, so as far as `jtag2updi` is concerned, it's effectively bricked. I couldn't dump the fuses from these devices to check what's wrong as a result of this as well.

I browsed around forums as well and noticed that there's a few odd instances where the official Arduino Nano Every was bricked with the exact same error in [2017](https://forum.arduino.cc/t/arduino-nano-every-unable-to-upload-program-any-sketch-error-rsp-illegal-mcu-state/960461) and twice in [2021](https://forum.arduino.cc/t/arduino-nano-every-atmega4809-locked-bad-response-to-sign-off-command-rsp-illegal-mcu-state/908016), albeit due to different circumstances. There was another interesting thread in [2021](https://forum.arduino.cc/t/atmega4809-fuse-settings-via-arduino-boards-txt/902643) regarding modifying fuse settings that locked the fella out, **with the exact same errors**. Perhaps it's an issue with setting "corrupted" fuse bits causing the MCU to stop/result in undefined behaviour?

At this stage, I'm not really sure if the issue is inherent of some bug within `arduino-cli`, or an in issue of the interaction of `arduino-cli` with this core and was hoping if you might be able to shed some light on this. What I'm currently speculating is that `arduino-cli` caused some sort of "invalid configuration" to occur. This actually happened to me before but in a less destructive fashion, it failed to program the right frequency fuse and caused serial to output garbage, and it was remedied by updating `arduino-cli` in homebrew at that time.

Update: 

Thanks for the idea and I concur with that UPDI should in theory mean that the controller is "unbrickable" by design. I managed to restore it to working condition with a spare Curiosity Nano (nEDBG) I had lying around by cutting the programming traces out and hooking its UPDI port into my custom board's UPDI pin, while disabling my SAMD11 based `jtag2updi` programmer by pulling its reset pin to ground.

This is the command that fixed the issue: `avrdude -C ~/Library/Arduino15/packages/MegaCoreX/hardware/megaavr/1.0.8/avrdude.conf -v -patmega4809 -ccuriosity_updi -Pusb -e -F` which performed a chip erase with that nEDBG debugger.

My device uses the same firmware and design as the Nano Every (running the Arduino MuxTO firmware, with code derived from [jtag2updi](https://github.com/ElTangas/jtag2updi)) as its mechanism for flashing firmware and serial communications. As a result of the SAMD11's limited flash, I wasn't able to recompile another version of MuxTO that supports [chip erase through interactive mode](https://github.com/ElTangas/jtag2updi/blob/master/README.md#using-with-avrdude) as the non-interactive mode (i.e. simply using `-e -F` as avrdude arguments) doesn't work as recorded by [some others](https://github.com/ElTangas/jtag2updi/issues/44#issuecomment-802211602)...although it is proposed that [avrdude may require changes](https://github.com/ElTangas/jtag2updi/issues/43#issuecomment-1046886009) so one could erase a locked chip without modifying the firmware of the programmer. In my custom board's original layout, it would be quite difficult to rescue the board without an external (non jtag2updi based) UPDI programmer to initiate a chip erase.

Since I was able to unbrick my device, I thought it was time to "brick" it again for science and document the exact sequence of events:

1. Flashed an Arduino program through Arduino IDE -> No issues, even after repeatedly flashing it (as it should be) [Full verbose dump available here](https://gist.github.com/d3lta-v/faa7301fd2d40c5c64fb2dd1da36b2d4)
2. Flashed the same program through CLI -> No issues. [Full verbose dump available here](https://gist.github.com/d3lta-v/feef27181c091c8e4d1a6dfb53c5cbeb)
3. Flashed the same program again through CLI -> program loaded successfully with identical output but the final reset and sign-off commands sent to the MCU failed. [Full verbose dump available here](https://gist.github.com/d3lta-v/e9579ccf601baece5cb1b3c69eb7708d)
4. Flashed the same program through CLI -> Fails completely as the device is locked.

At this point I'm not quite sure on what was the exact difference between `arduino-cli` and Arduino IDE that caused this error. The only one difference I spotted in the avrdude command was that `arduino-cli` used `-V` which disabled automatic verification. I will follow up this issue with `arduino-cli`'s repo, thanks for your help :)

Update:

I tried Arduino-CLI again but with `-t` to enforce a verification pass during upload and there were no further issues. I now believe that the lack of the `-V` argument is the cause.

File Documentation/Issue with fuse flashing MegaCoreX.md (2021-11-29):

# Issue with fuse flashing in MegaCoreX

I am currently developing my own board with a blend of design choices: 

- Uses a SAMD11 for a combined UART+UPDI to USB interface, with JTAG2UPDI and the need for 1200bps touch (identical to the Arduino Nano)
- Uses an ATmega4809
- Uses Arduino Uno Wifi pinout and is attached to an onboard ESP32 Wi-Fi chipset

I modified the core by duplicating the Nano Every's board definition and changed the `build.variant` to `uno-wifi` for that specific pinout, while still retaining the other properties for a SAMD11 based programmer (1200bps touch, JTAG2UPDI).

```
4809.menu.pinout.sstuinoii=SSTuino II
4809.menu.pinout.sstuinoii.build.variant=uno-wifi
4809.menu.pinout.sstuinoii.upload.tool=avrdude_nanoevery
4809.menu.pinout.sstuinoii.upload.use_1200bps_touch=true
4809.menu.pinout.sstuinoii.upload.protocol=jtag2updi
4809.menu.pinout.sstuinoii.program.extra_params=-P{serial.port} -e
4809.menu.pinout.sstuinoii.build.compat=
```

I started running into UART issues when I changed the board frequency from 20MHz to 16MHz (and by extension, all clock speeds that depend on the 16MHz oscillator). I tried to dump the fuses from the ATmega4809 and found out that the fuses were not burnt, meaning that while `F_CPU` was altered, the relevant fuse was never changed to reflect the correct frequency.

The original version of the upload pattern used by the `avrdude_nanoevery` is:

```
tools.avrdude_nanoevery.upload.pattern="{runtime.tools.avrdude.path}/bin/avrdude" "-C{runtime.platform.path}/avrdude.conf" {upload.verbose} {upload.verify} -p{build.mcu} -c{upload.protocol} {program.extra_params} "-Uflash:w:{build.path}/{build.project_name}.hex:i" {bootloader.fuse0} {bootloader.fuse1} {bootloader.fuse2} {bootloader.fuse4} {bootloader.fuse5} {bootloader.fuse6} {bootloader.fuse7} {bootloader.fuse8} {bootloader.lock}
```

It uploads the program perfectly, but does not upload any of the fuses.

The upload pattern below burns a single fuse, and it does the job perfectly fine, but only burns a fuse.

```
tools.avrdude_nanoevery.upload.pattern="{runtime.tools.avrdude.path}/bin/avrdude" "-C{runtime.platform.path}/avrdude.conf" {upload.verbose} {upload.verify} -p{build.mcu} -c{upload.protocol} {program.extra_params} "-Ufuse5:w:0xc9:m"
```

I tried to put the `-Uflash` parameter to the last part of the command like the example below, but that didn't help either: 

```
tools.avrdude_nanoevery.upload.pattern="{runtime.tools.avrdude.path}/bin/avrdude" "-C{runtime.platform.path}/avrdude.conf" {upload.verbose} {upload.verify} -p{build.mcu} -c{upload.protocol} {program.extra_params} {bootloader.fuse0} {bootloader.fuse1} {bootloader.fuse2} {bootloader.fuse4} {bootloader.fuse5} {bootloader.fuse6} {bootloader.fuse7} {bootloader.fuse8} {bootloader.lock} "-Uflash:w:{build.path}/{build.project_name}.hex:i"
```

An alternate version would be to upload only fuses, but no program:

```
tools.avrdude_nanoevery.upload.pattern="{runtime.tools.avrdude.path}/bin/avrdude" "-C{runtime.platform.path}/avrdude.conf" {upload.verbose} {upload.verify} -p{build.mcu} -c{upload.protocol} {program.extra_params} {bootloader.fuse0} {bootloader.fuse1} {bootloader.fuse2} {bootloader.fuse4} {bootloader.fuse5} {bootloader.fuse6} {bootloader.fuse7} {bootloader.fuse8} {bootloader.lock}
```

I'm wondering if there is a known issue specifically with Nano Every style of uploading the flash and uploading fuses in tandem with the flash memory.

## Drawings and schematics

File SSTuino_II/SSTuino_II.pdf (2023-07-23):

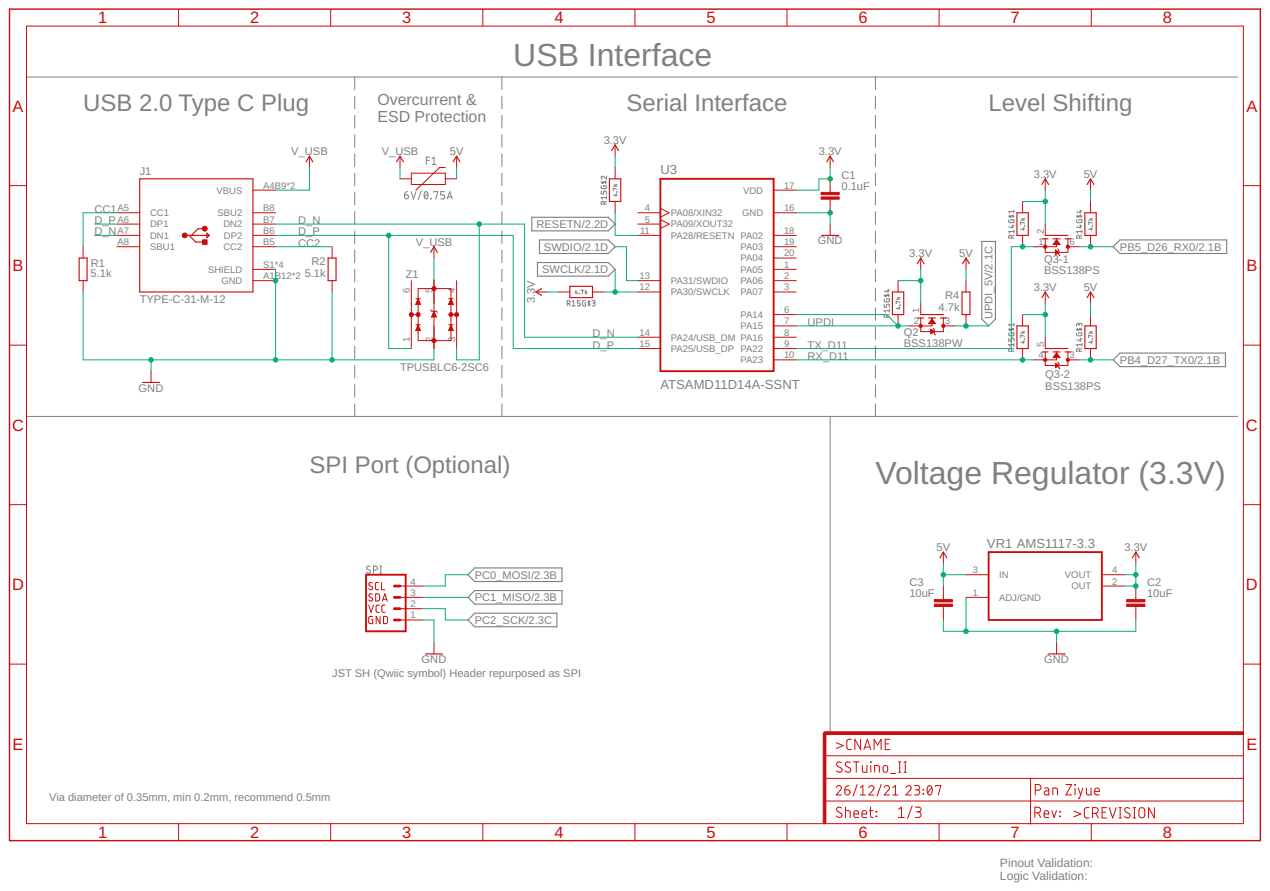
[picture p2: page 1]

USB Interface

JST SH (Qwiic symbol) Header repurposed as SPI

Via diameter of 0.35mm, min 0.2mm, recommend 0.5mm

Pinout Validation: Logic Validation:

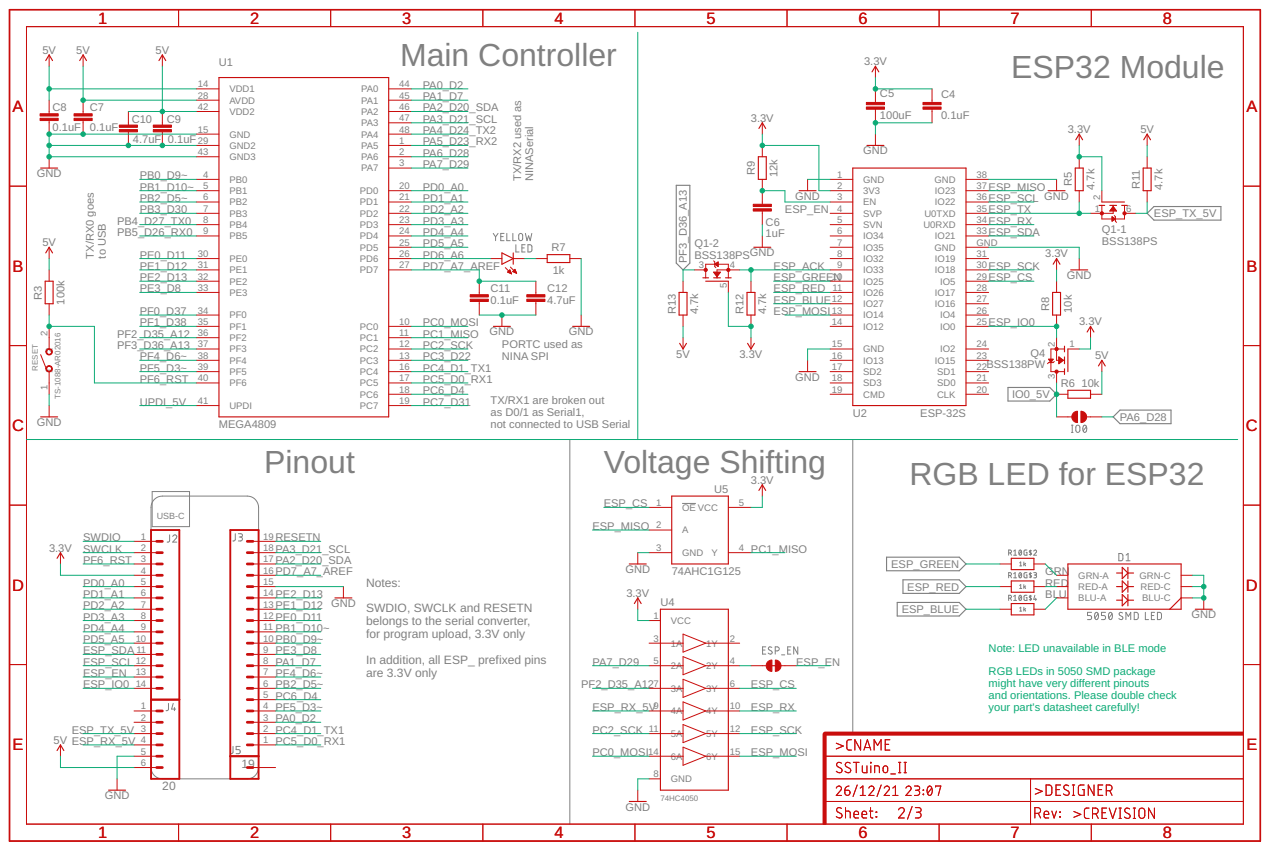
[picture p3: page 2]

TX/RX2 used as NINASerial PORTC used as NINA SPI

TX/RX1 are broken out as D0/1 as Serial1, not connected to USB Serial

Notes: SWDIO, SWCLK and RESETN
GND
belongs to the serial converter,
for program upload, 3.3V only

Note: LED unavailable in BLE mode RGB LEDs in 5050 SMD package might have very different pinouts and orientations. Please double check

In addition, all ESP_ prefixed pins are 3.3V only

your part's datasheet carefully!

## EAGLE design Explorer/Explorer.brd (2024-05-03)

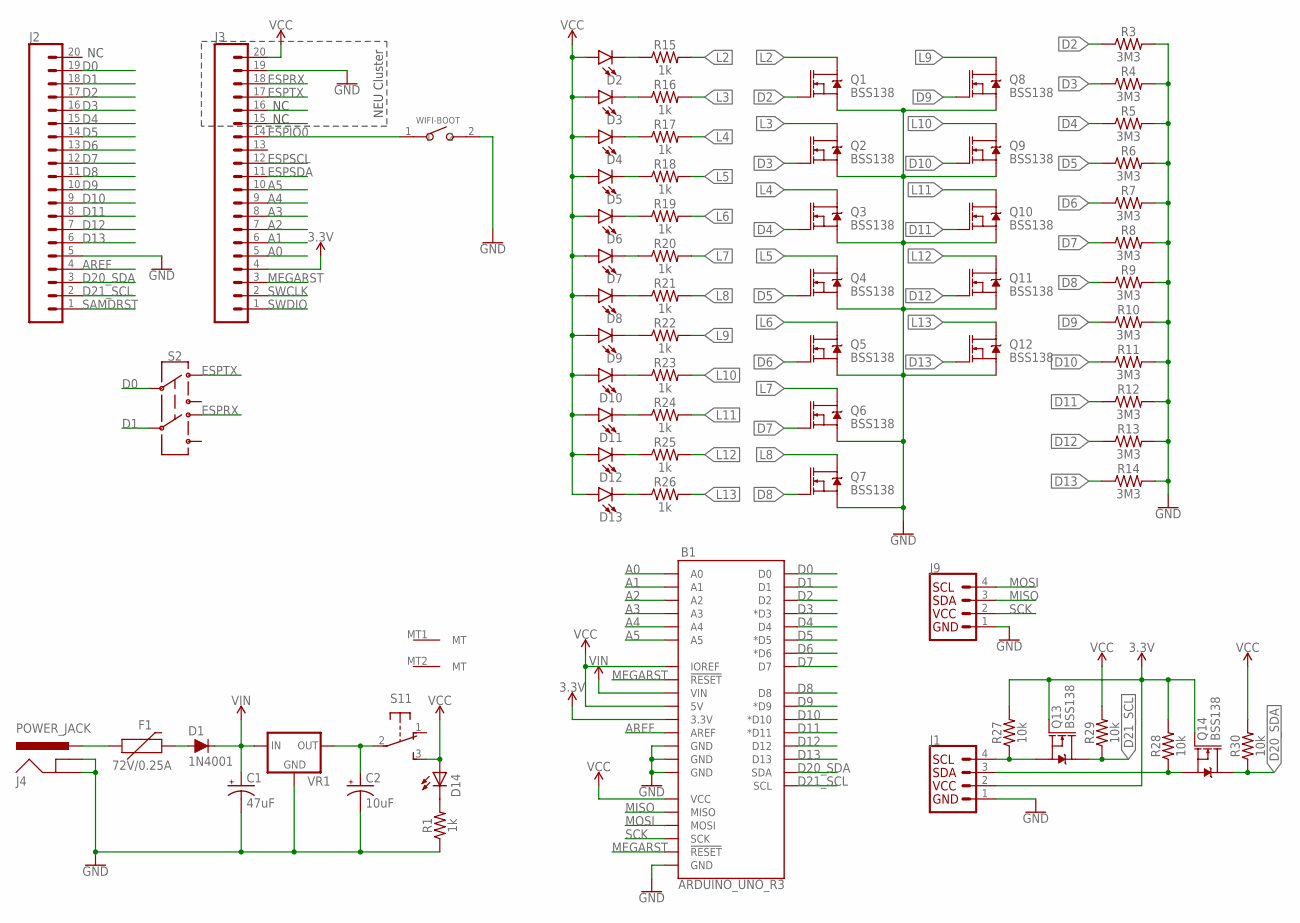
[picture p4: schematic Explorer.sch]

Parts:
B1: ARDUINO_UNO_R3; ARDUINO_R3
C1: 47uF; CPOL-RADIAL-2.5MM-6.5MM
C2: 10uF; CPOL-RADIAL-2.5MM-6.5MM
D1: 1N4001; DIODE-1N4001-KIT
D2, D3, D4, D5, D6, D7, D8, D9, D10, D11, D12, D13: LED0603; LED-0603; LCSC_PART C2286
D14: LEDCHIPLED_0805; CHIPLED_0805; LCSC_PART C2296
F1: 72V/0.25A; PTH
J1, J9: QWIIC_CONNECTORJS-1MM; 1X04_1MM_RA; LCSC_PART C239522
J2, J3: CONN_20; 1X20; LCSC_PART C50984
J4: POWER_JACK; POWER_JACK_PTH
Q1, Q2, Q3, Q4, Q5, Q6, Q7, Q8, Q9, Q10, Q11, Q12, Q13, Q14: BSS138; SOT23-3; LCSC_PART C435876
R1, R15, R16, R17, R18, R19, R20, R21, R22, R23, R24, R25, R26: 1k; 0603; LCSC_PART C21190
R3, R4, R5, R6, R7, R8, R9, R10, R11, R12, R13, R14: 3M3; 0603; LCSC_PART C103556
R27, R28, R29, R30: 10k; 0603; LCSC_PART C25804
S1: EG1213
S2: SWITCH-DPDT-SMD-AYZ0202; SWITCH_DPDT_SMD_AYZ0202; LCSC_PART C318999
VR1: V_REG_78XXSINK; TO220-IGO
WIFI-BOOT: SKRKAEE020; SW2-2.6-3.9X2.9X1.5+0.4MM; LCSC_PART C455280

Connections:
3.3V: B1.3.3V, J1.2 (VCC), J3.4, Q13.1 (G), Q14.1 (G), R27.2, R28.2
A0: B1.A0, J3.5
A1: B1.A1, J3.6
A2: B1.A2, J3.7
A3: B1.A3, J3.8
A4: B1.A4, J3.9
A5: B1.A5, J3.10
AREF: B1.AREF, J2.4
D0: B1.D0, J2.19, S2.2
D1: B1.D1, J2.18, S2.5
D2: B1.D2, J2.17, Q1.1 (G), R3.1
D3: B1.D3 (*D3), J2.16, Q2.1 (G), R4.1
D4: B1.D4, J2.15, Q3.1 (G), R5.1
D5: B1.D5 (*D5), J2.14, Q4.1 (G), R6.1
D6: B1.D6 (*D6), J2.13, Q5.1 (G), R7.1
D7: B1.D7, J2.12, Q6.1 (G), R8.1
D8: B1.D8, J2.11, Q7.1 (G), R9.1
D9: B1.D9 (*D9), J2.10, Q8.1 (G), R10.1
D10: B1.D10 (*D10), J2.9, Q9.1 (G), R11.1
D11: B1.D11 (*D11), J2.8, Q10.1 (G), R12.1
D12: B1.D12, J2.7, Q11.1 (G), R13.1
D13: B1.D13, J2.6, Q12.1 (G), R14.1
D20_SDA: B1.SDA, J2.3, Q14.3 (D), R30.1
D21_SCL: B1.SCL, J2.2, Q13.3 (D), R29.1
ESPIO0: J3.14, WIFI-BOOT.1
ESPRX: J3.18, S2.4
ESPSCL: J3.12
ESPSDA: J3.11
ESPTX: J3.17, S2.1
GND: B1.GND@1 (GND), B1.GND@2 (GND), B1.GND@3 (GND), B1.GND@4 (GND), C1.2 (-), C2.2 (-), J1.1 (GND), J2.5, J3.19, J4.GND, J4.GNDBREAK, J9.1 (GND), Q1.2 (S), Q2.2 (S), Q3.2 (S), Q4.2 (S), Q5.2 (S), Q6.2 (S), Q7.2 (S), Q8.2 (S), Q9.2 (S), Q10.2 (S), Q11.2 (S), Q12.2 (S), R1.1, R3.2, R4.2, R5.2, R6.2, R7.2, R8.2, R9.2, R10.2, R11.2, R12.2, R13.2, R14.2, VR1.GND, WIFI-BOOT.2
L2: Q1.3 (D), R15.2
L3: Q2.3 (D), R16.2
L4: Q3.3 (D), R17.2
L5: Q4.3 (D), R18.2
L6: Q5.3 (D), R19.2
L7: Q6.3 (D), R20.2
L8: Q7.3 (D), R21.2
L9: Q8.3 (D), R22.2
L10: Q9.3 (D), R23.2
L11: Q10.3 (D), R24.2
L12: Q11.3 (D), R25.2
L13: Q12.3 (D), R26.2
MEGARST: B1.RESET@1 (!RESET!), B1.RESET@2 (!RESET!), J3.3
MISO: B1.MISO, J9.3 (SDA)
MOSI: B1.MOSI, J9.4 (SCL)
unnamed: F1.P$1 (1), J4.PWR
unnamed: D1.A, F1.P$2 (2)
unnamed: D14.C, R1.2
unnamed: C2.1 (+), S1.2, VR1.OUT
unnamed: D13.C, R26.1
unnamed: D12.C, R25.1
unnamed: D11.C, R24.1
unnamed: D10.C, R23.1
unnamed: D9.C, R22.1
unnamed: D8.C, R21.1
unnamed: D7.C, R20.1
unnamed: D6.C, R19.1
unnamed: D5.C, R18.1
unnamed: D4.C, R17.1
unnamed: D3.C, R16.1
unnamed: D2.C, R15.1
SAMDRST: J2.1
SCK: B1.SCK, J9.2 (VCC)
SCL_3V: J1.4 (SCL), Q13.2 (S), R27.1
SDA_3V: J1.3 (SDA), Q14.2 (S), R28.1
SWCLK: J3.2
SWDIO: J3.1
VCC: B1.5V, B1.IOREF, B1.VCC, D2.A, D3.A, D4.A, D5.A, D6.A, D7.A, D8.A, D9.A, D10.A, D11.A, D12.A, D13.A, D14.A, J3.20, R29.2, R30.2, S1.3 (S)
VIN: B1.VIN, C1.1 (+), D1.C, VR1.IN

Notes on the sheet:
NEU Cluster

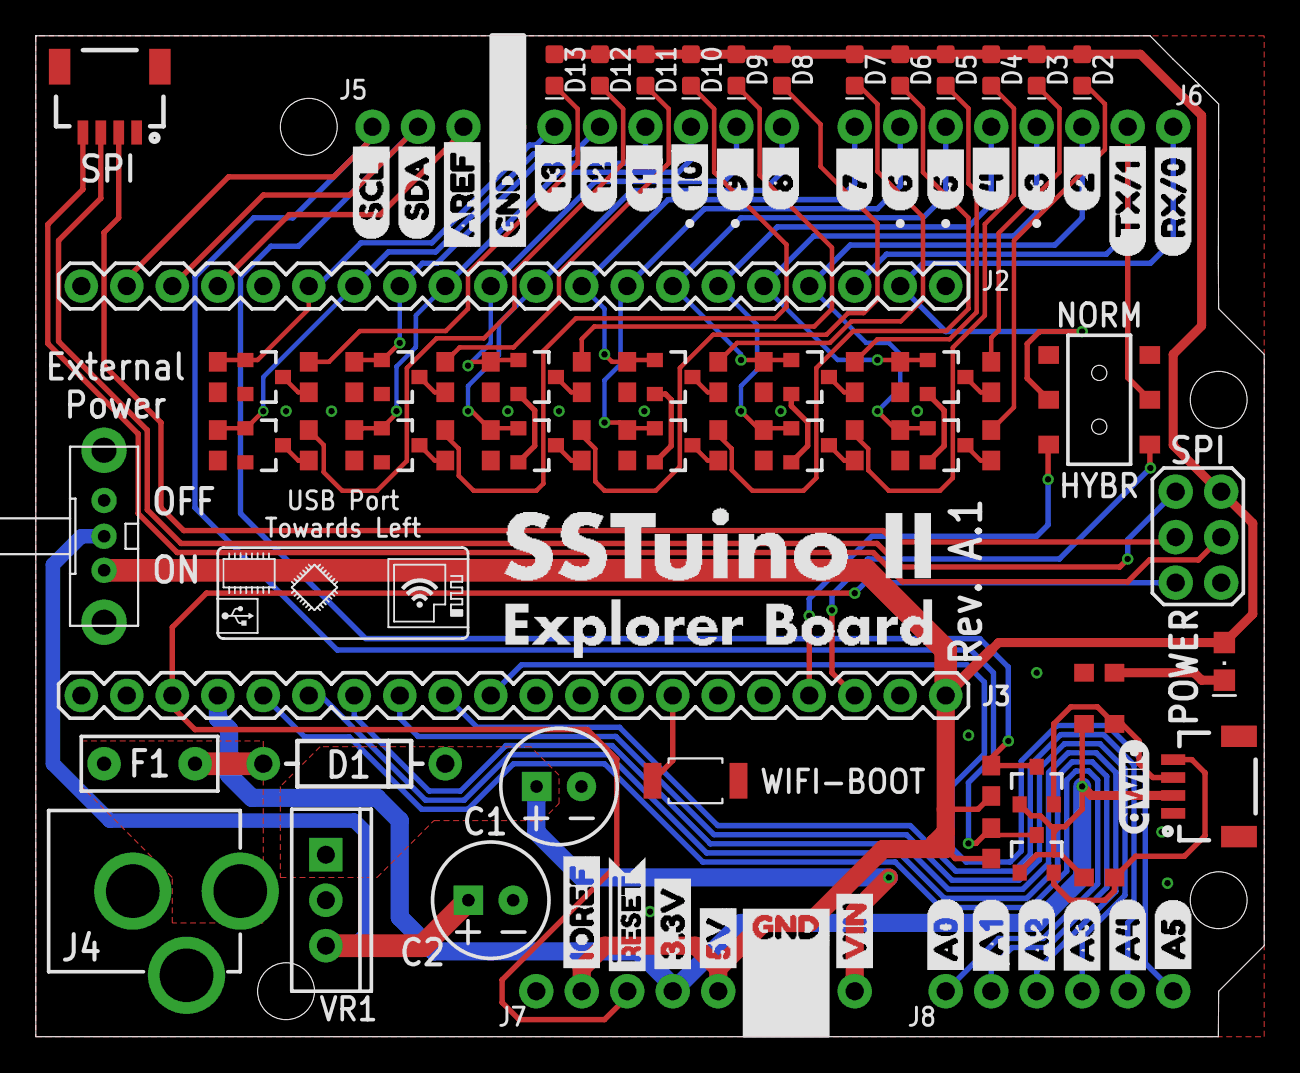
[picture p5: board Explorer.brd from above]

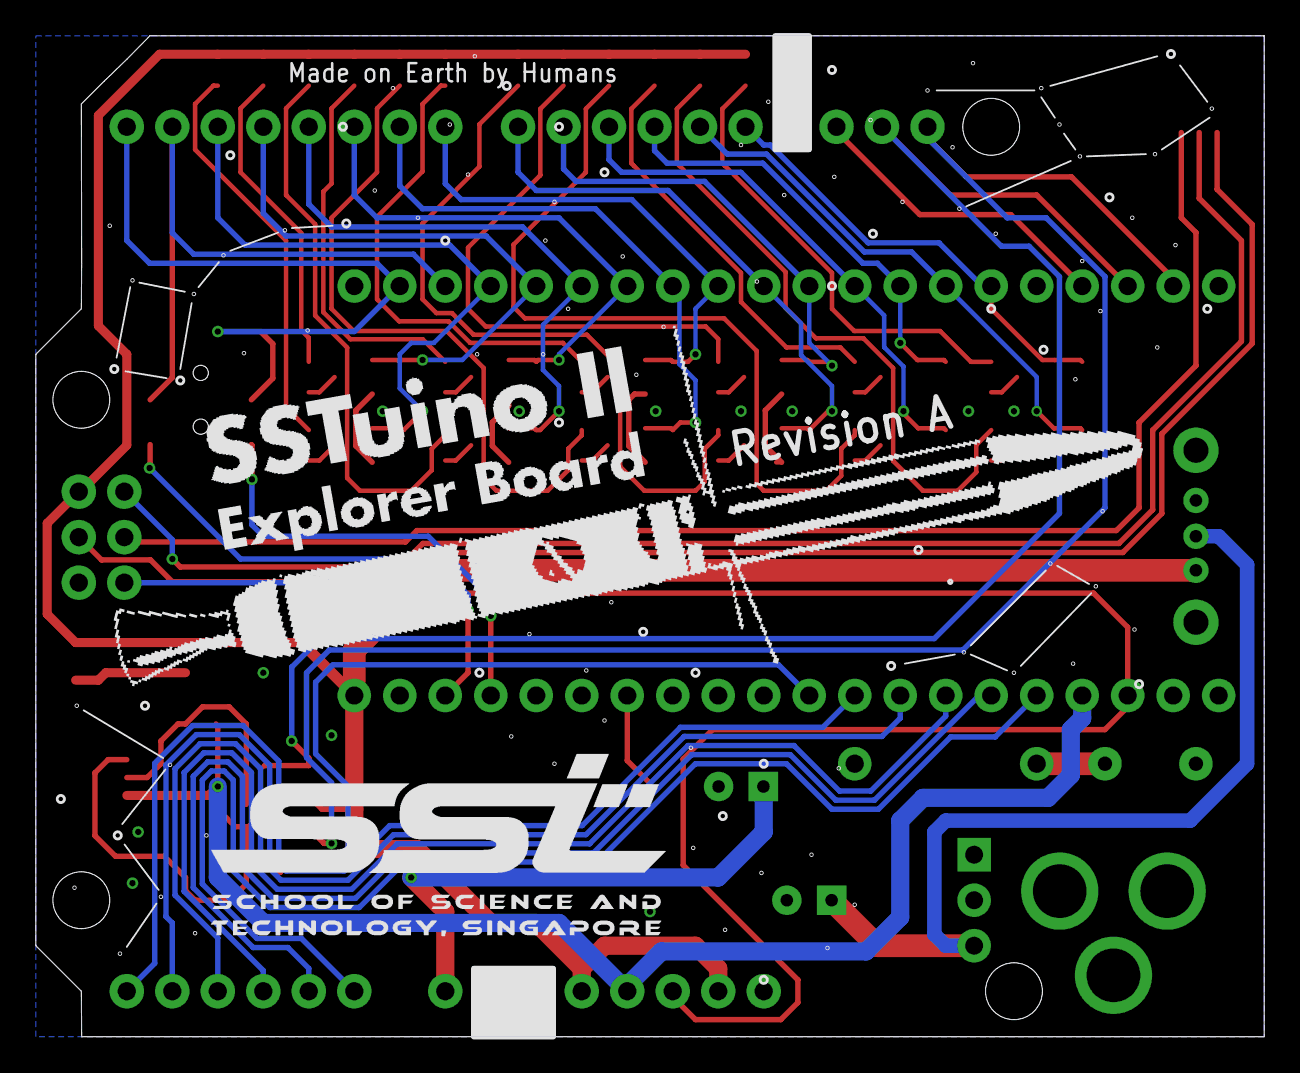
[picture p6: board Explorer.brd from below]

Board: 2 copper layers, 68.6 x 55.9 mm, 117 parts (13 on the bottom side), 64 nets.

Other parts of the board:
U$1: IOREF9
U$2: 3#3V7
U$3: #RESET28
U$4: 5V8
U$5, U$25: GND6
U$6: A00
U$7: A11
U$8: SST-BIG
U$9: EXPLORER
U$10: STARFIELD_URSAMINOR
U$11: STARFIELD_SMALL
U$12: STARFIELD_ORION
U$13: STARFIELD_LYRA
U$14: STARFIELD_CASSIOPEIA
U$15, U$16, U$17, U$18, U$19: STARFIELD_SMALL2
U$20: A22
U$21, U$45: EXPLORER_BOARD_LARGE
U$22: A33
U$23: A44
U$24: A55
U$26: 1314
U$27: 1215
U$28: 1116
U$29: 1017
U$30: 9__18
U$31: 8__19
U$32: 7__20
U$33: 6__21
U$34: 5__22
U$35: 4__23
U$36: 3__24
U$37: 2__25
U$38: TX#127
U$39: RX#026
U$40: AREF13
U$41: SDA25
U$42: SCL26
U$43: VIN10
U$44: QWIIC_LOGO
U$46: USBLOGO#PNG
U$47: WIFILOGO#JPG

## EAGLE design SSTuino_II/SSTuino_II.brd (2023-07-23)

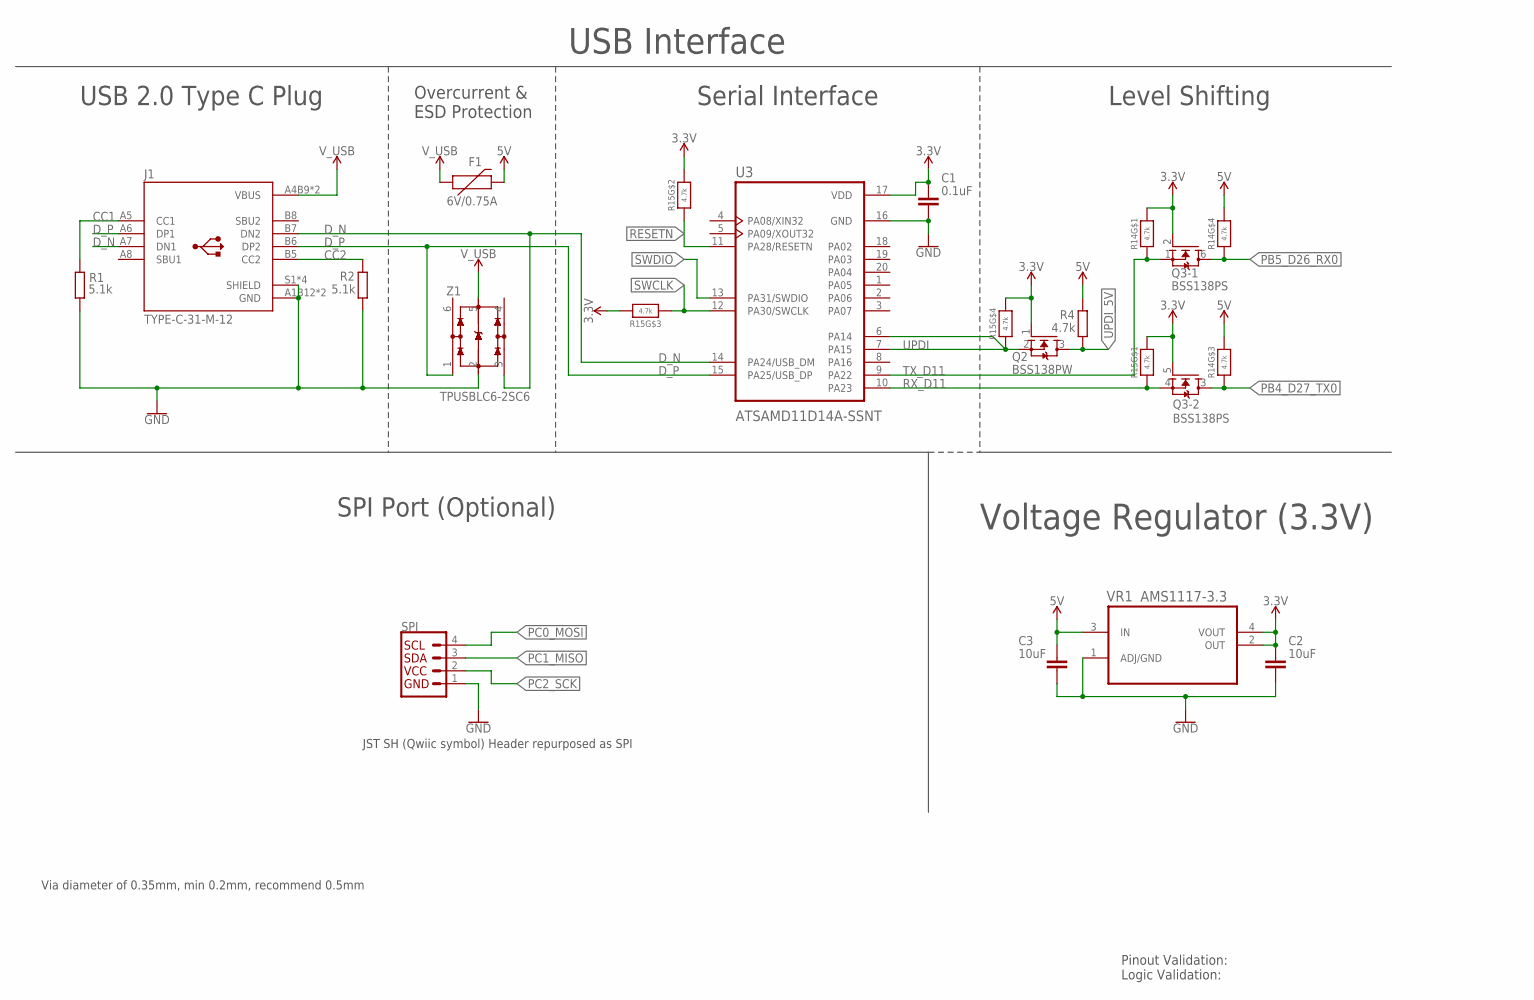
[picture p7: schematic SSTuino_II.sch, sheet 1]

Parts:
C1: 0.1uF; CAPC1005X60; LCSC_PART C696352
C2, C3: 10uF; CAPC1608X85; LCSC_PART C19702
F1: 6V/0.75A; 1206; LCSC_PART C99563
J1: TYPE-C-31-M-12; HRO_TYPE-C-31-M-12; LCSC_PART C165948
Q2: BSS138PW; SOT65P210X110-3N; LCSC_PART C193366
Q3: BSS138PS; ARDUINO-TRANSISTORS_SOT363; LCSC_PART C193381
R1, R2: 5.1k; RESC1005X40; LCSC_PART C25905
R4: 4.7k; RESC1005X40; LCSC_PART C25900
R14, R15: 4.7k; RESPACK_4X0402; LCSC_PART C29586
SPI: QWIIC_CONNECTORJS-1MM; 1X04_1MM_RA
U3: ATSAMD11D14A-SSNT; SOIC127P1030X265-20N; LCSC_PART C2053599
VR1: AMS1117-3.3; SOT230P696X180-4N; LCSC_PART C6186
Z1: TPUSBLC6-2SC6; SOT95P280X110-6N; LCSC_PART C558442

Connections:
3.3V: C1.1, C2.1, Q2.1 (G), Q3.2 (G), Q3.5 (G), R14.8 (2), R15.5 (2), R15.6 (2), R15.7 (2), R15.8 (2), U3.17 (VDD), VR1.2 (OUT), VR1.4 (VOUT); also elsewhere on the board
5V: C3.1, F1.2, R4.2, R14.5 (2), R14.6 (2), VR1.3 (IN); also elsewhere on the board
CC1: J1.A5 (CC1), R1.1
CC2: J1.B5 (CC2), R2.2
D_N: J1.A7 (DN1), J1.B7 (DN2), U3.14 (PA24/USB_DM), Z1.3 (IO2)
D_P: J1.A6 (DP1), J1.B6 (DP2), U3.15 (PA25/USB_DP), Z1.1 (IO1)
GND: C1.2, C2.2, C3.2, J1.A1B12 (GND), J1.B1A12 (GND), J1.S1 (SHIELD), J1.S2 (SHIELD), J1.S3 (SHIELD), J1.S4 (SHIELD), R1.2, R2.1, SPI.1 (GND), U3.16 (GND), VR1.1 (ADJ/GND), Z1.2 (VSS); also elsewhere on the board
PB4_D27_TX0: Q3.3 (D), R14.3 (1); also elsewhere on the board
PB5_D26_RX0: Q3.6 (D), R14.4 (1); also elsewhere on the board
PC0_MOSI: SPI.4 (SCL); also elsewhere on the board
PC1_MISO: SPI.3 (SDA); also elsewhere on the board
PC2_SCK: SPI.2 (VCC); also elsewhere on the board
RESETN: R15.2 (1), U3.11 (PA28/RESETN); also elsewhere on the board
RX_D11: Q3.4 (S), R15.1, U3.10 (PA23)
SWCLK: R15.3 (1), U3.12 (PA30/SWCLK); also elsewhere on the board
SWDIO: U3.13 (PA31/SWDIO); also elsewhere on the board
TX_D11: Q3.1 (S), R14.1, U3.9 (PA22)
UPDI: Q2.2 (S), R15.4 (1), U3.6 (PA14), U3.7 (PA15)
UPDI_5V: Q2.3 (D), R4.1; also elsewhere on the board
V_USB: F1.1, J1.A4B9 (VBUS), J1.B4A9 (VBUS), Z1.5 (VCC)

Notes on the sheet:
Via diameter of 0.35mm, min 0.2mm, recommend 0.5mm
USB Interface
Voltage Regulator (3.3V)
USB 2.0 Type C Plug
Overcurrent & ESD Protection
Serial Interface
Level Shifting
Pinout Validation: Logic Validation:
JST SH (Qwiic symbol) Header repurposed as SPI
SPI Port (Optional)

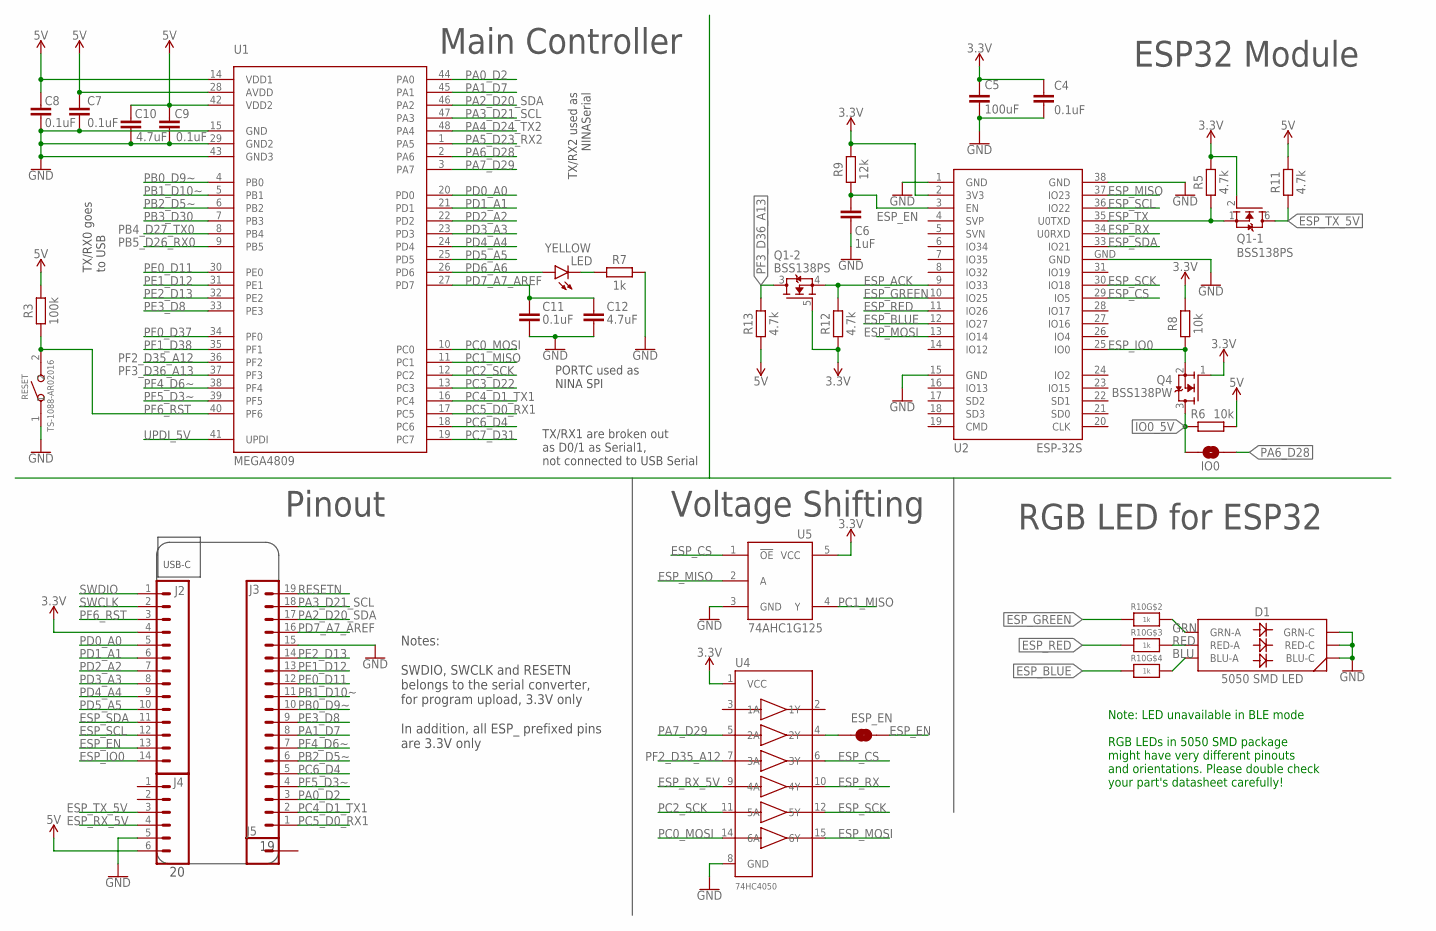
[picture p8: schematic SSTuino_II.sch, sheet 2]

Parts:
C4, C11: 0.1uF; CAPC1005X60; LCSC_PART C1525
C5: 100uF; CAPC3216X135; LCSC_PART C15008
C6: 1uF; CAPC1005X60; LCSC_PART C52923
C7, C8, C9: 0.1uF; CAPC1005X60
C10: 4.7uF; CAPC1005X60
C12: 4.7uF; CAPC1005X60; LCSC_PART C23733
D1: 5050 SMD LED; LED-TRICOLOR-5050; LCSC_PART C784540
ESP_EN: JUMPER-SMT_2_NC_TRACE_SILK; SMT-JUMPER_2_NC_TRACE_SILK
IO0: JUMPER-SMT_2_NO_SILK; SMT-JUMPER_2_NO_SILK
J2: CONN_14NO_SILK; 1X14_NO_SILK
J3: CONN_191X19_NO_SILK; 1X19_NO_SILK
J4: CONN_06NO_SILK_FEMALE_PTH; 1X06_NO_SILK
J5: CONN_01PTH_NO_SILK_YES_STOP; 1X01_NO_SILK
LED: YELLOW; LED-0603; LCSC_PART C72038
Q1: BSS138PS; ARDUINO-TRANSISTORS_SOT363; LCSC_PART C193381
Q4: BSS138PW; SOT65P210X110-3N; LCSC_PART C919583
R3: 100k; RESC1005X40; LCSC_PART C25741
R5, R11, R12, R13: 4.7k; RESC1005X40; LCSC_PART C25900
R6, R8: 10k; RESC1005X40; LCSC_PART C25744
R7: 1k; RESC1005X40; LCSC_PART C11702
R9: 12k; RESC1005X40; LCSC_PART C25752
R10: 1k; RESPACK_4X0402; LCSC_PART C25726
RESET: TS-1088-AR02016; SW2-2.6-3.9X2.9X1.5+0.4MM; LCSC_PART C720477
U1: MEGA4809; TQFP48; LCSC_PART C189475
U2: ESP-32S; LCSC_PART C277944
U4: 74HC4050; TSSOP16; LCSC_PART C352825
U5: 74AHC1G125; SOT23-5L; LCSC_PART C7468

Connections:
3.3V: C4.1, C5.1, J2.4, Q1.2 (G), Q1.5 (G), Q4.1 (G), R5.2, R8.2, R9.2, R12.1, U2.2 (3V3), U4.1 (VCC), U5.5 (VCC); also elsewhere on the board
5V: C7.1, C8.1, C9.1, C10.1, J4.6, R3.2, R6.1, R11.2, R13.1, U1.14 (VDD1), U1.28 (AVDD), U1.42 (VDD2); also elsewhere on the board
BLU: D1.6 (BLU-A), R10.5 (2)
ESP_ACK: Q1.4 (S), R12.2, U2.9 (IO33)
ESP_BLUE: R10.4 (1), U2.12 (IO27)
ESP_CS: U2.29 (IO5), U4.6 (3Y), U5.1 (!OE)
ESP_EN: C6.2, ESP_EN.2, J2.13, R9.1, U2.3 (EN)
ESP_EN_PRE: ESP_EN.1, U4.4 (2Y)
ESP_GREEN: R10.2 (1), U2.10 (IO25)
ESP_IO0: J2.14, Q4.2 (S), R8.1, U2.25 (IO0)
ESP_MISO: U2.37 (IO23), U5.2 (A)
ESP_MOSI: U2.13 (IO14), U4.15 (6Y)
ESP_RED: R10.3 (1), U2.11 (IO26)
ESP_RX: U2.34 (U0RXD), U4.10 (4Y)
ESP_RX_5V: J4.4, U4.9 (4A)
ESP_SCK: U2.30 (IO18), U4.12 (5Y)
ESP_SCL: J2.12, U2.36 (IO22)
ESP_SDA: J2.11, U2.33 (IO21)
ESP_TX: Q1.1 (S), R5.1, U2.35 (U0TXD)
ESP_TX_5V: J4.3, Q1.6 (D), R11.1
GND: C4.2, C5.2, C6.1, C7.2, C8.2, C9.2, C10.2, C11.2, C12.2, D1.1 (BLU-C), D1.2 (RED-C), D1.3 (GRN-C), J3.15, J4.5, R7.2, RESET.1, U1.15 (GND), U1.29 (GND2), U1.43 (GND3), U2.1 (GND), U2.15 (GND), U2.38 (GND), U2.GND, U4.8 (GND), U5.3 (GND); also elsewhere on the board
GRN: D1.4 (GRN-A), R10.7 (2)
IO0_5V: IO0.2, Q4.3 (D), R6.2
unnamed: LED.C, R7.1
PA0_D2: J3.3, U1.44 (PA0)
PA1_D7: J3.8, U1.45 (PA1)
PA2_D20_SDA: J3.17, U1.46 (PA2)
PA3_D21_SCL: J3.18, U1.47 (PA3)
PA4_D24_TX2: U1.48 (PA4)
PA5_D23_RX2: U1.1 (PA5)
PA6_D28: IO0.1, U1.2 (PA6)
PA7_D29: U1.3 (PA7), U4.5 (2A)
PB0_D9~: J3.10, U1.4 (PB0)
PB1_D10~: J3.11, U1.5 (PB1)
PB2_D5~: J3.6, U1.6 (PB2)
PB3_D30: U1.7 (PB3)
PB4_D27_TX0: U1.8 (PB4); also elsewhere on the board
PB5_D26_RX0: U1.9 (PB5); also elsewhere on the board
PC0_MOSI: U1.10 (PC0), U4.14 (6A); also elsewhere on the board
PC1_MISO: U1.11 (PC1), U5.4 (Y); also elsewhere on the board
PC2_SCK: U1.12 (PC2), U4.11 (5A); also elsewhere on the board
PC3_D22: U1.13 (PC3)
PC4_D1_TX1: J3.2, U1.16 (PC4)
PC5_D0_RX1: J3.1, U1.17 (PC5)
PC6_D4: J3.5, U1.18 (PC6)
PC7_D31: U1.19 (PC7)
PD0_A0: J2.5, U1.20 (PD0)
PD1_A1: J2.6, U1.21 (PD1)
PD2_A2: J2.7, U1.22 (PD2)
PD3_A3: J2.8, U1.23 (PD3)
PD4_A4: J2.9, U1.24 (PD4)
PD5_A5: J2.10, U1.25 (PD5)
PD6_A6: LED.A, U1.26 (PD6)
PD7_A7_AREF: C11.1, C12.1, J3.16, U1.27 (PD7)
PE0_D11: J3.12, U1.30 (PE0)
PE1_D12: J3.13, U1.31 (PE1)
PE2_D13: J3.14, U1.32 (PE2)
PE3_D8: J3.9, U1.33 (PE3)
PF0_D37: U1.34 (PF0)
PF1_D38: U1.35 (PF1)
PF2_D35_A12: U1.36 (PF2), U4.7 (3A)
PF3_D36_A13: Q1.3 (D), R13.2, U1.37 (PF3)
PF4_D6~: J3.7, U1.38 (PF4)
PF5_D3~: J3.4, U1.39 (PF5)
PF6_RST: J2.3, R3.1, RESET.2, U1.40 (PF6)
RED: D1.5 (RED-A), R10.6 (2)
RESETN: J3.19; also elsewhere on the board
SWCLK: J2.2; also elsewhere on the board
SWDIO: J2.1; also elsewhere on the board
UPDI_5V: U1.41 (UPDI); also elsewhere on the board

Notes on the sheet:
TX/RX2 used as NINASerial
PORTC used as NINA SPI
TX/RX1 are broken out as D0/1 as Serial1, not connected to USB Serial
TX/RX0 goes to USB
Note: LED unavailable in BLE mode RGB LEDs in 5050 SMD package might have very different pinouts and orientations. Please double check your part's datasheet carefully!
USB-C
ESP32 Module
Main Controller
Pinout
Voltage Shifting
RGB LED for ESP32
Notes: SWDIO, SWCLK and RESETN belongs to the serial converter, for program upload, 3.3V only In addition, all ESP_ prefixed pins are 3.3V only

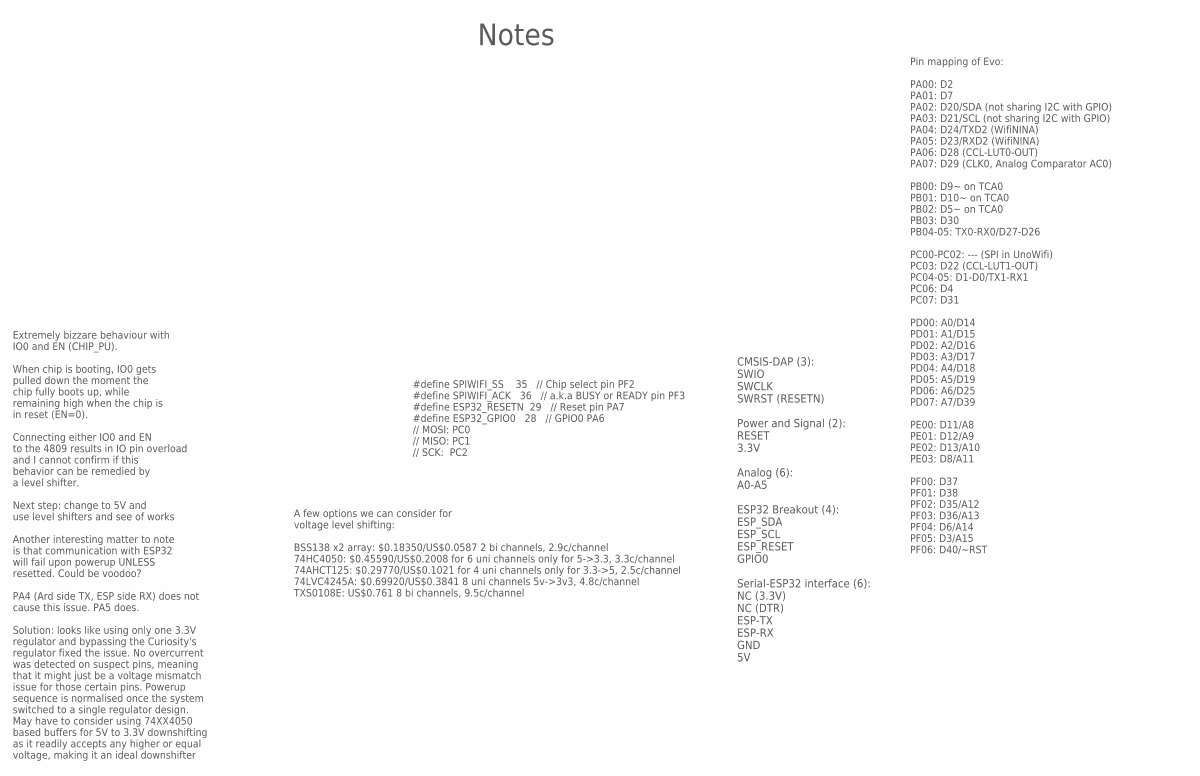
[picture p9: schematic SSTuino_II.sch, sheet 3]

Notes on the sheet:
Extremely bizzare behaviour with IO0 and EN (CHIP_PU). When chip is booting, IO0 gets pulled down the moment the chip fully boots up, while remaining high when the chip is in reset (EN=0). Connecting either IO0 and EN to the 4809 results in IO pin overload and I cannot confirm if this behavior can 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
#define SPIWIFI_SS 35 // Chip select pin PF2 #define SPIWIFI_ACK 36 // a.k.a BUSY or READY pin PF3 #define ESP32_RESETN 29 // Reset pin PA7 #define ESP32_GPIO0 28 // GPIO0 PA6 // MOSI: PC0 // MISO: PC1 // SCK: PC2
Pin mapping of Evo: PA00: D2 PA01: D7 PA02: D20/SDA (not sharing I2C with GPIO) PA03: D21/SCL (not sharing I2C with GPIO) PA04: D24/TXD2 (WifiNINA) PA05: D23/RXD2 (WifiNINA) PA06: D28 (CCL-LUT0-OUT) PA07: D29 (CLK0, Analog Comparator AC0) PB00: D9~ on TCA0 PB01: D10~ on TCA0 PB02: D5~ on TCA0 PB03: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
A few options we can consider for voltage level shifting: BSS138 x2 array: $0.18350/US$0.0587 2 bi channels, 2.9c/channel 74HC4050: $0.45590/US$0.2008 for 6 uni channels only for 5->3.3, 3.3c/channel 74AHCT125: $0.29770/US$0.1021 for 4 uni channels only for 3.3->5, 2.5c/channel 74LVC4245A: $0.69920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
Notes
CMSIS-DAP (3): SWIO SWCLK SWRST (RESETN) Power and Signal (2): RESET 3.3V Analog (6): A0-A5 ESP32 Breakout (4): ESP_SDA ESP_SCL ESP_RESET GPIO0 Serial-ESP32 interface (6): NC (3.3V) NC (DTR) ESP-TX ESP-RX GND 5V

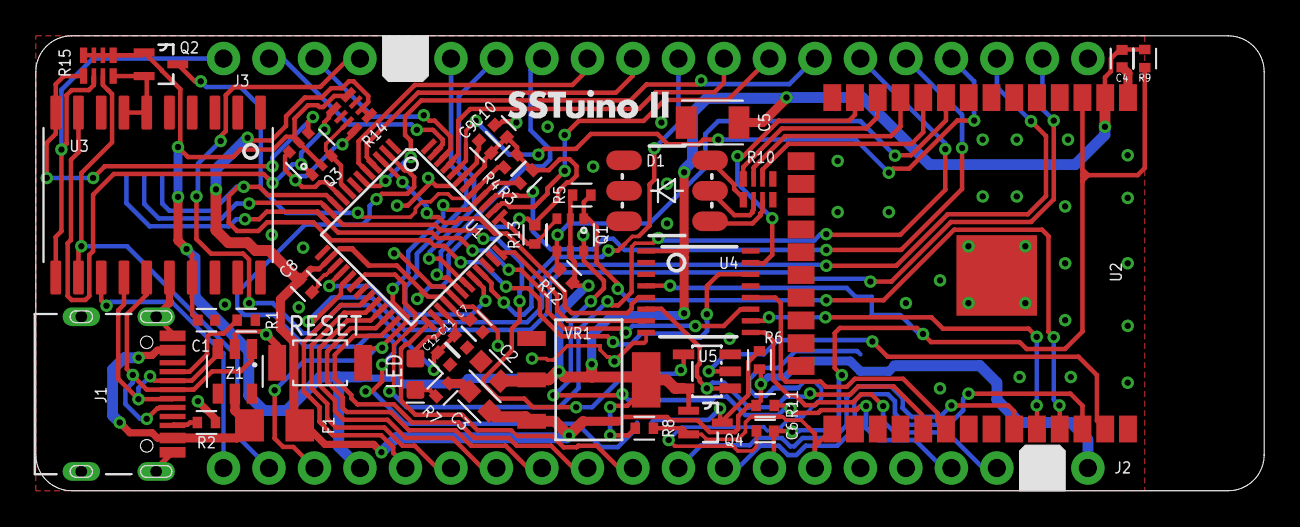
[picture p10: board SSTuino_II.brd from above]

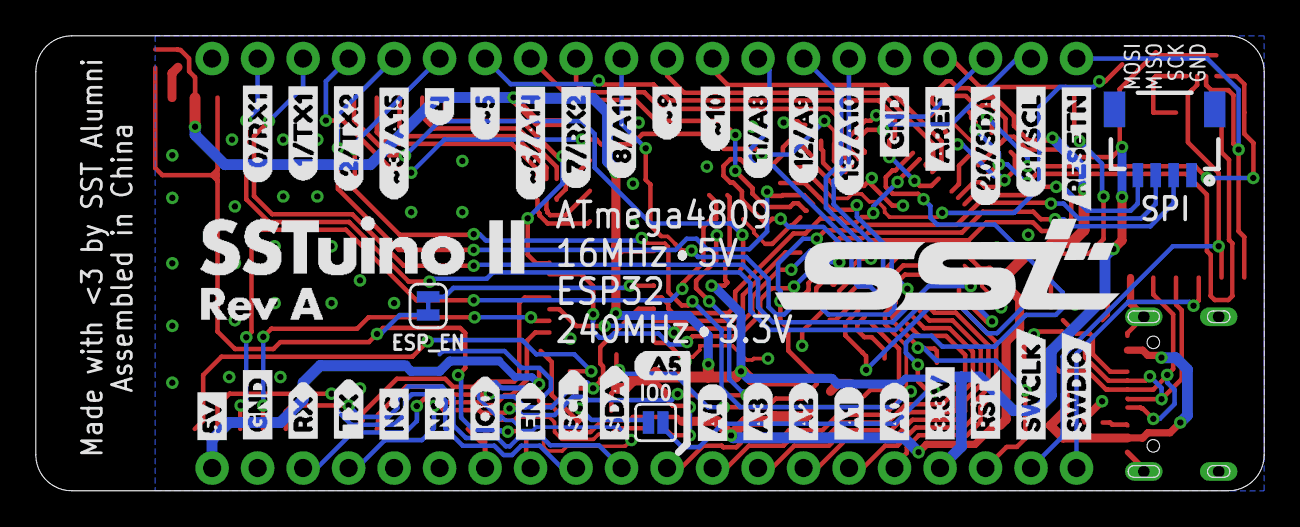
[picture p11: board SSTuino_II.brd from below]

Board: 2 copper layers, 68.6 x 25.4 mm, 92 parts (44 on the bottom side), 71 nets.

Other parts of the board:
U$1, U$2: LABEL-GND0
U$3, U$4: LABEL-NC0
U$5: LABEL-#3#A159
U$6: SSTUINOII-REVA-FUTURA-1LINE
U$7: LABEL-#6#A1412
U$8: LABEL-#511
U$9: LABEL-#916
U$10: LABEL-#1017
U$11: LABEL-0#RX17
U$12: LABEL-1#TX18
U$13: LABEL-2#TX214
U$14: LABEL-3#3V6
U$15: LABEL-7#RX213
U$16: LABEL-8#A1115
U$17: LABEL-11#A818
U$18: LABEL-12#A919
U$19: LABEL-13#A1020
U$20: LABEL-20#SDA2
U$21: LABEL-21#SCL3
U$22: LABEL-410
U$23: LABEL-AREF4
U$24: LABEL-SWCLK1
U$25: LABEL-SWDIO0
U$26: LABEL-5V5
U$27: LABEL-A01
U$28: LABEL-IO03
U$29: LABEL-A23
U$30: LABEL-A34
U$31: LABEL-A45
U$32: LABEL-A56
U$33: LABEL-EN4
U$34: LABEL-RST0
U$35: LABEL-TX8
U$36: LABEL-RX7
U$37: LABEL-SCL5
U$38: LABEL-SDA6
U$39: LABEL-RESETN9
U$40: LABEL-A10
U$41: SSTUINOII-REVA-FUTURA-2
U$42: SST-LOGO-SVG

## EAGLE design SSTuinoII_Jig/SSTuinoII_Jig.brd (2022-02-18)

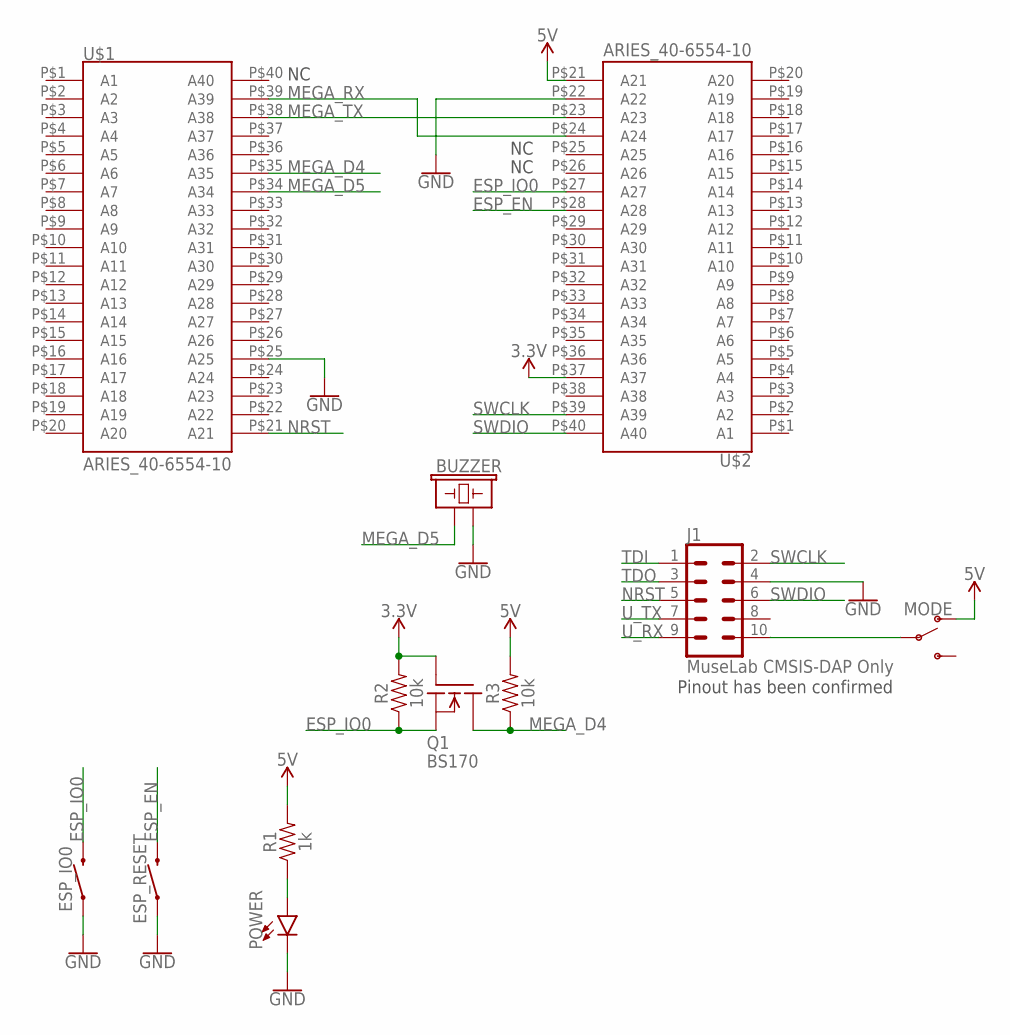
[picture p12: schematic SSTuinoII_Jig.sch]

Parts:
BUZZER: BUZZER-PTH_KIT; BUZZER-12MM-KIT
ESP_IO0: MOMENTARY-SWITCH-SPST-PTH-6.0MM-KIT; TACTILE_SWITCH_PTH_6.0MM_KIT
ESP_RESET: MOMENTARY-SWITCH-SPST-PTH-6.0MM-KIT; TACTILE_SWITCH_PTH_6.0MM_KIT
J1: MuseLab CMSIS-DAP Only; 2X5-SHROUDED_LOCK
MODE: SWITCH-SPDT-PTH-11.6X4.0MM-KIT; SWITCH_SPDT_PTH_11.6X4.0MM_KIT
POWER: LED3MM; LED_3MM
Q1: BS170; TO92
R1: 1k; AXIAL-0.3-KIT
R2, R3: 10k; AXIAL-0.3-KIT
U$1, U$2: ARIES_40-6554-10

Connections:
3.3V: Q1.2 (G), R2.P$2 (2), U$2.P$37 (A37)
5V: MODE.1 (O), R1.P$2 (2), R3.P$2 (2), U$2.P$21 (A21)
ESP_EN: ESP_RESET.3 (2), U$2.P$28 (A28)
ESP_IO0: ESP_IO0.3 (2), Q1.1 (S), R2.P$1 (1), U$2.P$27 (A27)
GND: BUZZER.- (2), ESP_IO0.1, ESP_RESET.1, J1.4, POWER.K (C), U$1.P$25 (A25), U$2.P$22 (A22)
MEGA_D4: Q1.3 (D), R3.P$1 (1), U$1.P$35 (A35)
MEGA_D5: BUZZER.+ (1), U$1.P$34 (A34)
MEGA_RX: U$1.P$39 (A39), U$2.P$24 (A24)
MEGA_TX: U$1.P$38 (A38), U$2.P$23 (A23)
unnamed: POWER.A, R1.P$1 (1)
NRST: J1.5, U$1.P$21 (A21)
PWR: J1.10, MODE.2
SWCLK: J1.2, U$2.P$39 (A39)
SWDIO: J1.6, U$2.P$40 (A40)
TDI: J1.1
TDO: J1.3
U_RX: J1.9
U_TX: J1.7

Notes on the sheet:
Pinout has been confirmed

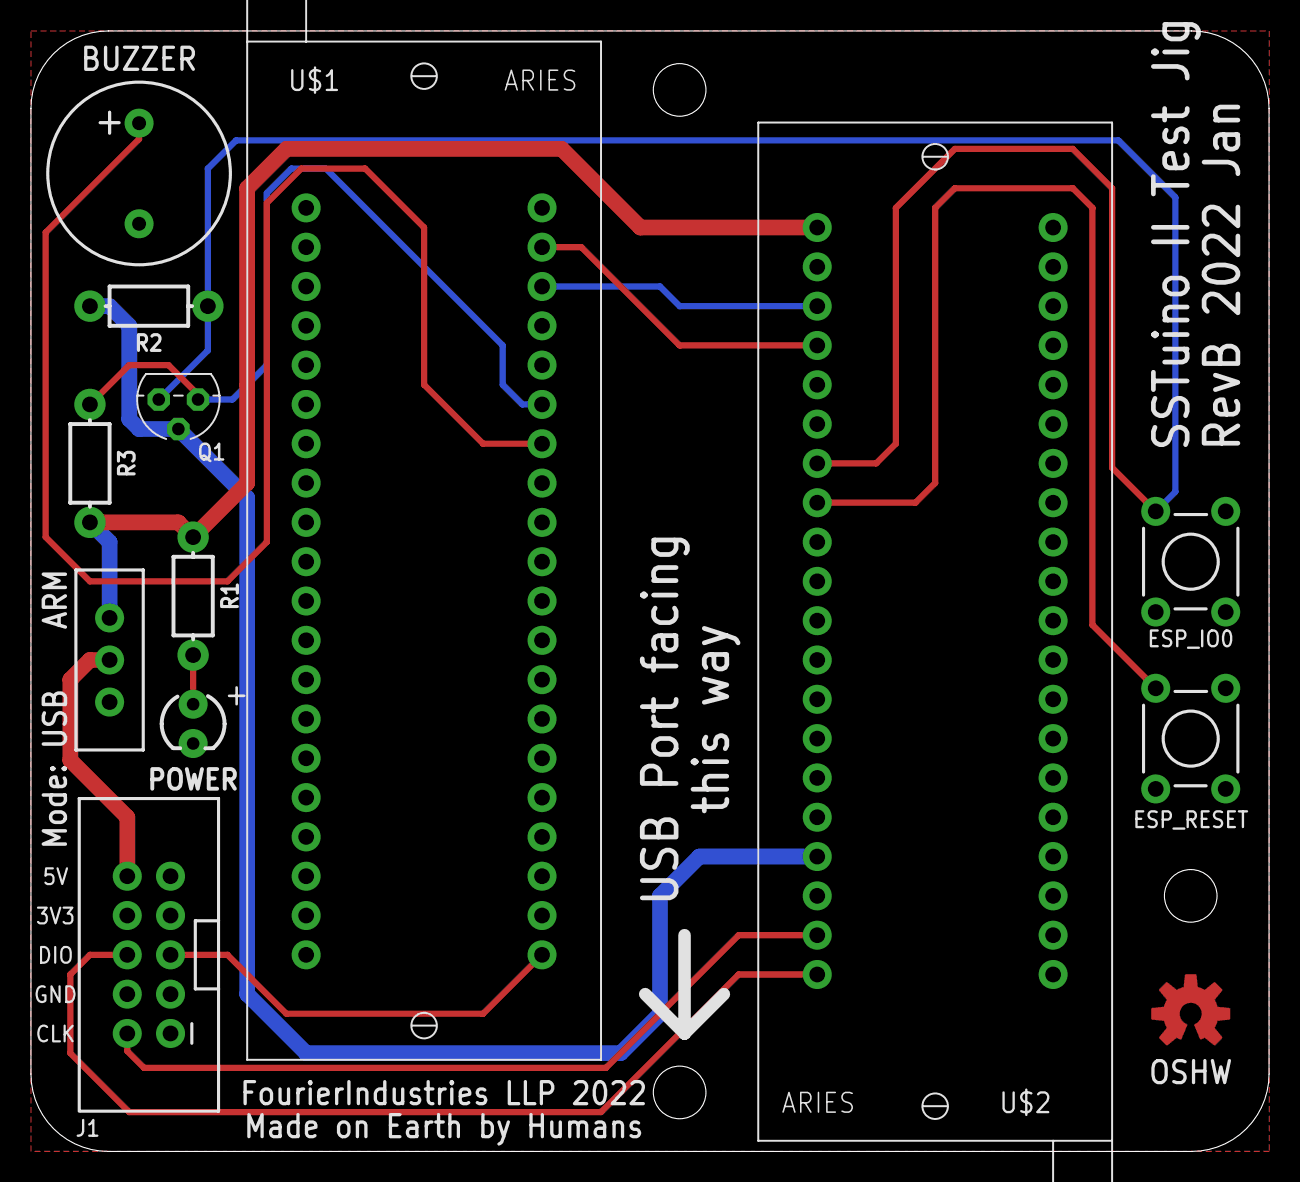
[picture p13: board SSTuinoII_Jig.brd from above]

Board: 2 copper layers, 80.0 x 72.4 mm, 13 parts (0 on the bottom side), 14 nets.

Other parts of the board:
U$3: OSHW-LOGO-M_COPPER-SOLDERMASK

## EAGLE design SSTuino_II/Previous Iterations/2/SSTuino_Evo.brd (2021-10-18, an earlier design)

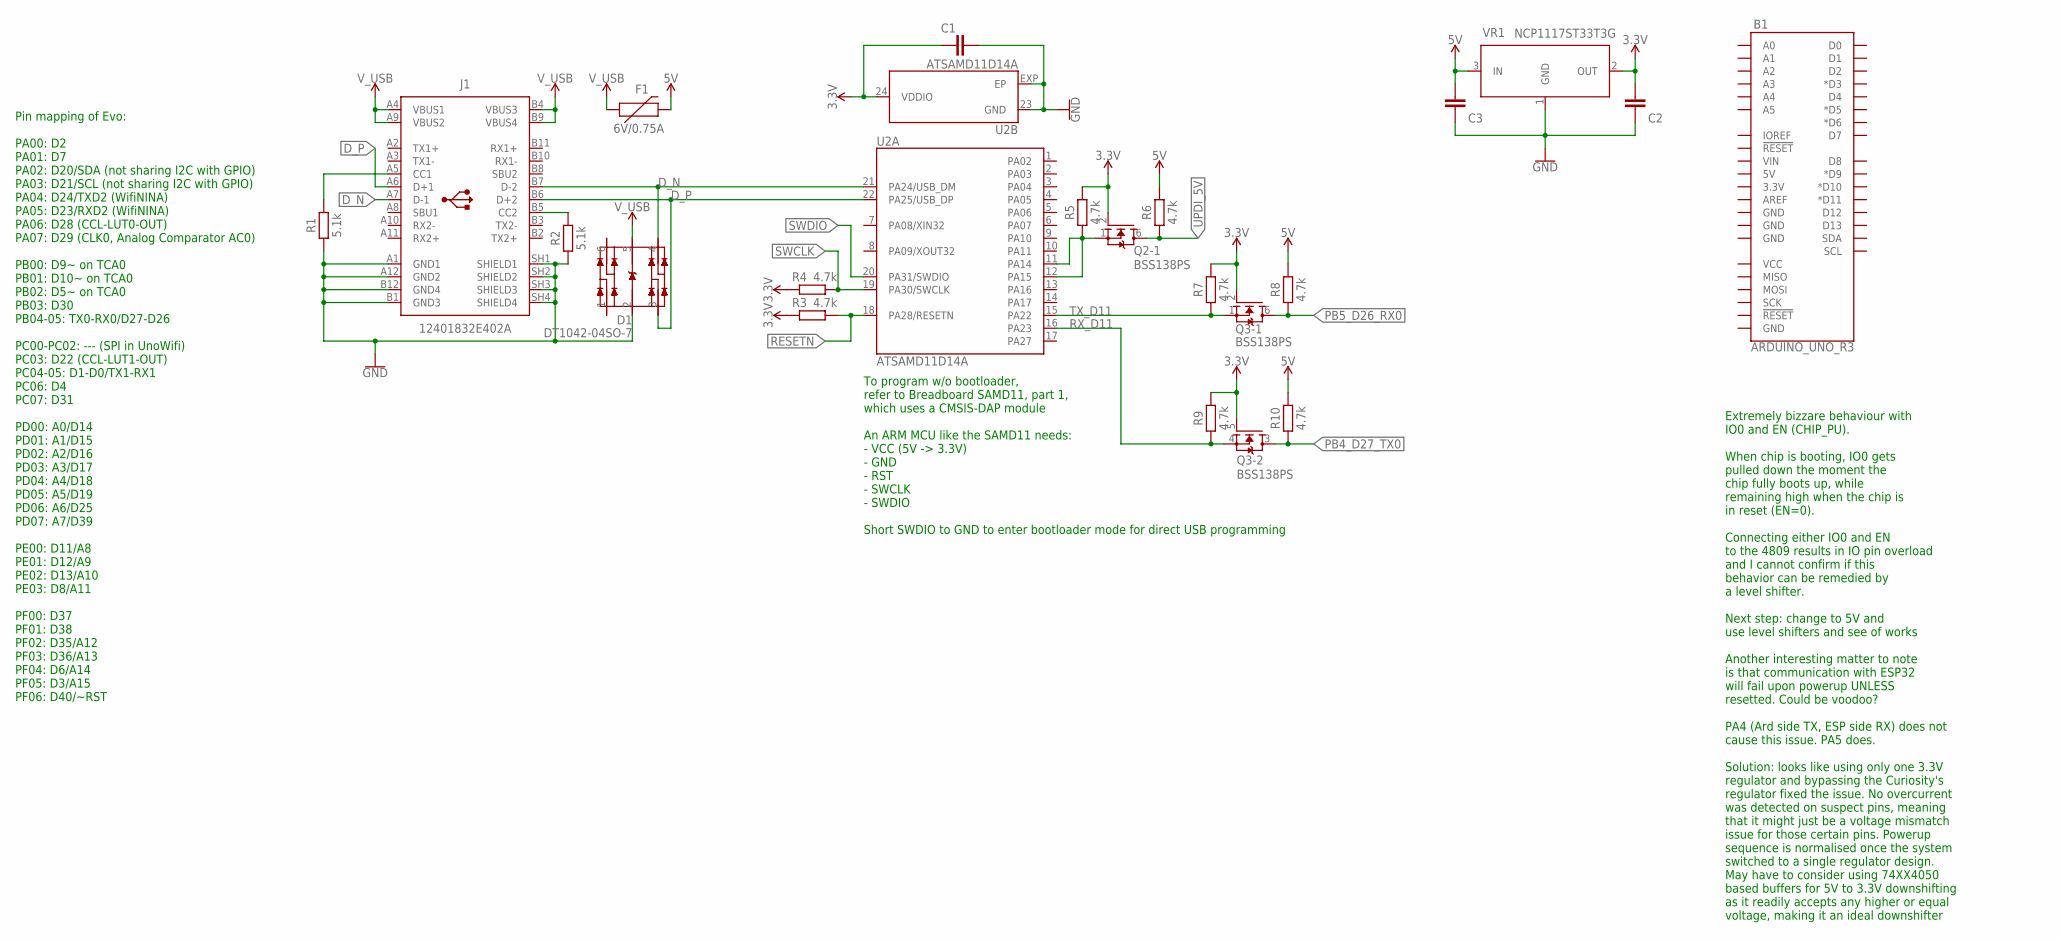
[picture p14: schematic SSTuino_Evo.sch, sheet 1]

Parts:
B1: ARDUINO_UNO_R3; ARDUINO_R3
C1: 100n; CAPC1005X60
C2, C3: 10uF; CAPC1608X85
D1: DT1042-04SO-7; SOT95P285X140-6N
F1: 6V/0.75A; 1206
J1: 12401832E402A
Q2, Q3: BSS138PS; ARDUINO-TRANSISTORS_SOT363
R1, R2: 5.1k; RESC1005X40
R3, R4, R5, R6, R7, R8, R9, R10: 4.7k; RESC1005X40
U2: ATSAMD11D14A; ARDUINO-UCS&SOCS_HVQFN24
VR1: NCP1117ST33T3G; SOT230P700X170-4

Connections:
3.3V: C1.1, C2.1, Q2.2 (G), Q3.2 (G), Q3.5 (G), R3.2, R4.2, R5.2, R7.2, R9.2, U2.24 (VDDIO), VR1.2 (OUT); also elsewhere on the board
5V: C3.1, F1.2, R6.2, R8.2, R10.2, VR1.3 (IN); also elsewhere on the board
CC1: J1.A5 (CC1), R1.2
CC2: J1.B5 (CC2), R2.2
D_N: D1.4 (IO3), J1.A7 (D-1), J1.B7 (D-2), U2.21 (PA24/USB_DM)
D_P: D1.3 (IO2), J1.A6 (D+1), J1.B6 (D+2), U2.22 (PA25/USB_DP)
GND: C1.2, C2.2, C3.2, D1.2 (VSS), J1.A1 (GND1), J1.A12 (GND2), J1.B1 (GND3), J1.B12 (GND4), J1.SH1 (SHIELD1), J1.SH2 (SHIELD2), J1.SH3 (SHIELD3), J1.SH4 (SHIELD4), R1.1, R2.1, U2.23 (GND), U2.EXP (EP), VR1.1 (GND); also elsewhere on the board
PB4_D27_TX0: Q3.3 (D), R10.1; also elsewhere on the board
PB5_D26_RX0: Q3.6 (D), R8.1; also elsewhere on the board
RESETN: R3.1, U2.18 (PA28/RESETN)
RX_D11: Q3.4 (S), R9.1, U2.16 (PA23)
SWCLK: R4.1, U2.19 (PA30/SWCLK)
SWDIO: U2.20 (PA31/SWDIO)
TX_D11: Q3.1 (S), R7.1, U2.15 (PA22)
UPDI_3V3: Q2.1 (S), R5.1, U2.11 (PA14), U2.12 (PA15)
UPDI_5V: Q2.6 (D), R6.1
V_USB: D1.5 (VCC), F1.1, J1.A4 (VBUS1), J1.A9 (VBUS2), J1.B4 (VBUS3), J1.B9 (VBUS4)

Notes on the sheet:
Pin mapping of Evo: PA00: D2 PA01: D7 PA02: D20/SDA (not sharing I2C with GPIO) PA03: D21/SCL (not sharing I2C with GPIO) PA04: D24/TXD2 (WifiNINA) PA05: D23/RXD2 (WifiNINA) PA06: D28 (CCL-LUT0-OUT) PA07: D29 (CLK0, Analog Comparator AC0) PB00: D9~ on TCA0 PB01: D10~ on TCA0 PB02: D5~ on TCA0 PB03: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
To program w/o bootloader, refer to Breadboard SAMD11, part 1, which uses a CMSIS-DAP module An ARM MCU like the SAMD11 needs: - VCC (5V -> 3.3V) - GND - RST - SWCLK - SWDIO Short SWDIO to GND to enter bootloader mode for direct USB programming
Extremely bizzare behaviour with IO0 and EN (CHIP_PU). When chip is booting, IO0 gets pulled down the moment the chip fully boots up, while remaining high when the chip is in reset (EN=0). Connecting either IO0 and EN to the 4809 results in IO pin overload and I cannot confirm if this behavior can 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

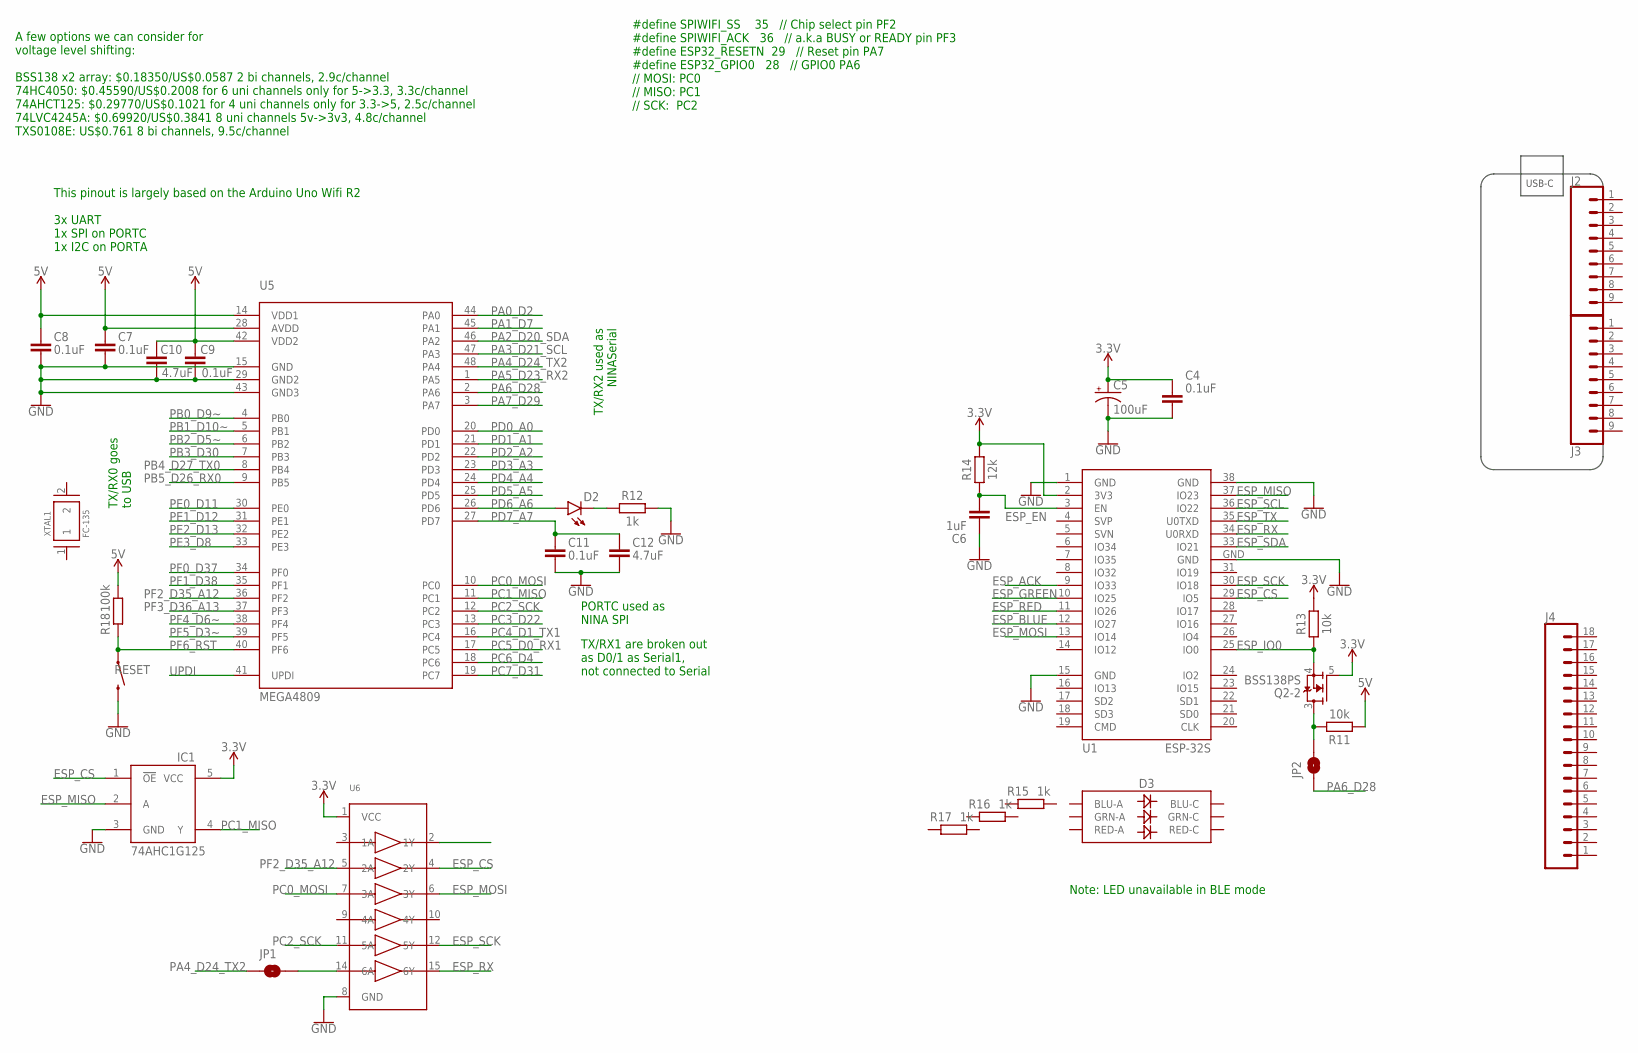
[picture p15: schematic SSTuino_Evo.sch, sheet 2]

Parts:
C4, C7, C8, C9, C11: 0.1uF; CAPC1005X60
C5: 100uF; CAPMP3216X180N
C6: 1uF; CAPC1005X60
C10, C12: 4.7uF; CAPC1005X60
D2: LED0603; LED-0603
D3: LED-RGBNO_IC; LED-TRICOLOR-5050
IC1: 74AHC1G125; SOT23-5L
J2, J3: CONN_09NO_SILK; 1X09_NO_SILK
J4: CONN_18; 1X18
JP1, JP2: JUMPER-SMT_2_NO_SILK; SMT-JUMPER_2_NO_SILK
Q2: BSS138PS; ARDUINO-TRANSISTORS_SOT363
R11, R13: 10k; RESC1005X40
R12, R15, R16, R17: 1k; RESC1005X40
R14: 12k; RESC1005X40
R18: 100k; RESC1005X40
RESET: MOMENTARY-SWITCH-SPST-SMD-4.6X2.8MM; TACTILE_SWITCH_SMD_4.6X2.8MM
U1: ESP-32S
U5: MEGA4809; TQFP48
U6: 74HC4050DTSSOP; TSSOP16
XTAL1: FC-135; XTAL330X1051X90N

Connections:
3.3V: C4.1, C5.1 (+), IC1.5 (VCC), Q2.5 (G), R13.2, R14.2, U1.2 (3V3), U6.1 (VCC); also elsewhere on the board
5V: C7.1, C8.1, C9.1, C10.1, R11.1, R18.2, U5.14 (VDD1), U5.28 (AVDD), U5.42 (VDD2); also elsewhere on the board
ESP_ACK: U1.9 (IO33)
ESP_BLUE: U1.12 (IO27)
ESP_CS: IC1.1 (!OE), U1.29 (IO5), U6.4 (2Y)
ESP_EN: C6.2, R14.1, U1.3 (EN)
ESP_GREEN: U1.10 (IO25)
ESP_IO0: Q2.4 (S), R13.1, U1.25 (IO0)
ESP_MISO: IC1.2 (A), U1.37 (IO23)
ESP_MOSI: U1.13 (IO14), U6.6 (3Y)
ESP_RED: U1.11 (IO26)
ESP_RX: U1.34 (U0RXD), U6.15 (6Y)
ESP_SCK: U1.30 (IO18), U6.12 (5Y)
ESP_SCL: U1.36 (IO22)
ESP_SDA: U1.33 (IO21)
ESP_TX: U1.35 (U0TXD)
GND: C4.2, C5.2 (-), C6.1, C7.2, C8.2, C9.2, C10.2, C11.2, C12.2, IC1.3 (GND), R12.2, RESET.3 (2), RESET.4 (2), U1.1 (GND), U1.15 (GND), U1.38 (GND), U1.GND, U5.15 (GND), U5.29 (GND2), U5.43 (GND3), U6.8 (GND); also elsewhere on the board
unnamed: JP2.2, Q2.3 (D), R11.2
unnamed: D2.C, R12.1
unnamed: JP1.2, U6.14 (6A)
PA0_D2: U5.44 (PA0)
PA1_D7: U5.45 (PA1)
PA2_D20_SDA: U5.46 (PA2)
PA3_D21_SCL: U5.47 (PA3)
PA4_D24_TX2: JP1.1, U5.48 (PA4)
PA5_D23_RX2: U5.1 (PA5)
PA6_D28: JP2.1, U5.2 (PA6)
PA7_D29: U5.3 (PA7)
PB0_D9~: U5.4 (PB0)
PB1_D10~: U5.5 (PB1)
PB2_D5~: U5.6 (PB2)
PB3_D30: U5.7 (PB3)
PB4_D27_TX0: U5.8 (PB4); also elsewhere on the board
PB5_D26_RX0: U5.9 (PB5); also elsewhere on the board
PC0_MOSI: U5.10 (PC0), U6.7 (3A)
PC1_MISO: IC1.4 (Y), U5.11 (PC1)
PC2_SCK: U5.12 (PC2), U6.11 (5A)
PC3_D22: U5.13 (PC3)
PC4_D1_TX1: U5.16 (PC4)
PC5_D0_RX1: U5.17 (PC5)
PC6_D4: U5.18 (PC6)
PC7_D31: U5.19 (PC7)
PD0_A0: U5.20 (PD0)
PD1_A1: U5.21 (PD1)
PD2_A2: U5.22 (PD2)
PD3_A3: U5.23 (PD3)
PD4_A4: U5.24 (PD4)
PD5_A5: U5.25 (PD5)
PD6_A6: D2.A, U5.26 (PD6)
PD7_A7: C11.1, C12.1, U5.27 (PD7)
PE0_D11: U5.30 (PE0)
PE1_D12: U5.31 (PE1)
PE2_D13: U5.32 (PE2)
PE3_D8: U5.33 (PE3)
PF0_D37: U5.34 (PF0)
PF1_D38: U5.35 (PF1)
PF2_D35_A12: U5.36 (PF2), U6.5 (2A)
PF3_D36_A13: U5.37 (PF3)
PF4_D6~: U5.38 (PF4)
PF5_D3~: U5.39 (PF5)
PF6_RST: R18.1, RESET.1, RESET.2 (1), U5.40 (PF6)
UPDI: U5.41 (UPDI)

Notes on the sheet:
A few options we can consider for voltage level shifting: BSS138 x2 array: $0.18350/US$0.0587 2 bi channels, 2.9c/channel 74HC4050: $0.45590/US$0.2008 for 6 uni channels only for 5->3.3, 3.3c/channel 74AHCT125: $0.29770/US$0.1021 for 4 uni channels only for 3.3->5, 2.5c/channel 74LVC4245A: $0.69920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
This pinout is largely based on the Arduino Uno Wifi R2 3x UART 1x SPI on PORTC 1x I2C on PORTA
TX/RX2 used as NINASerial
PORTC used as NINA SPI
TX/RX1 are broken out as D0/1 as Serial1, not connected to Serial
TX/RX0 goes to USB
#define SPIWIFI_SS 35 // Chip select pin PF2 #define SPIWIFI_ACK 36 // a.k.a BUSY or READY pin PF3 #define ESP32_RESETN 29 // Reset pin PA7 #define ESP32_GPIO0 28 // GPIO0 PA6 // MOSI: PC0 // MISO: PC1 // SCK: PC2
Note: LED unavailable in BLE mode
USB-C

Board: 2 copper layers, 51 parts (0 on the bottom side), 35 nets, no tracks yet.

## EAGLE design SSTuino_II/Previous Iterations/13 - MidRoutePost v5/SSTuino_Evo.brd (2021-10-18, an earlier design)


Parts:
B1: ARDUINO_UNO_R3; ARDUINO_R3
C1: 100n; CAPC1005X60
C2, C3: 10uF; CAPC1608X85
F1: 6V/0.75A; 1206; LCSC_PART C99563
J5: TYPE-C-31-M-12; HRO_TYPE-C-31-M-12; LCSC_PART C165948
Q2: BSS138PW; SOT65P210X110-3N
Q3: BSS138PS; ARDUINO-TRANSISTORS_SOT363; LCSC_PART C193381
R1, R2: 5.1k; RESC1005X40
R3, R5: 4.7k; RESPACK_4X0402; LCSC_PART C1980
R4: 4.7k; RESC1005X40
TVS1: TPUSBLC6-2SC6; SOT95P280X110-6N; LCSC_PART C558442
U3: AMS1117-3.3; SOT230P696X180-4N; LCSC_PART C6186
U4: ATSAMD11D14A-SSNT; SOIC127P1030X265-20N; LCSC_PART C2053599

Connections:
3.3V: C1.1, C2.1, Q2.1 (G), Q3.2 (G), Q3.5 (G), R3.5 (2), R3.6 (2), R3.7 (2), R3.8 (2), R5.5 (2), U3.2 (OUT), U3.4 (VOUT), U4.17 (VDD); also elsewhere on the board
5V: C3.1, F1.2, R4.2, R5.6 (2), R5.7 (2), R5.8 (2), U3.3 (IN); also elsewhere on the board
CC1: J5.A5 (CC1), R1.1
CC2: J5.B5 (CC2), R2.2
D_N: J5.A7 (DN1), J5.B7 (DN2), TVS1.3 (IO2), U4.14 (PA24/USB_DM)
D_P: J5.A6 (DP1), J5.B6 (DP2), TVS1.1 (IO1), U4.15 (PA25/USB_DP)
GND: C1.2, C2.2, C3.2, J5.A1B12 (GND), J5.B1A12 (GND), J5.S1 (SHIELD), J5.S2 (SHIELD), J5.S3 (SHIELD), J5.S4 (SHIELD), R1.2, R2.1, TVS1.2 (VSS), U3.1 (ADJ/GND), U4.16 (GND); also elsewhere on the board
PB4_D27_TX0: Q3.3 (D), R5.3 (1); also elsewhere on the board
PB5_D26_RX0: Q3.6 (D), R5.1; also elsewhere on the board
RESETN: R3.2 (1), U4.11 (PA28/RESETN); also elsewhere on the board
RX_D11: Q3.4 (S), R3.1, U4.10 (PA23)
SWCLK: R3.3 (1), U4.12 (PA30/SWCLK); also elsewhere on the board
SWDIO: U4.13 (PA31/SWDIO); also elsewhere on the board
TX_D11: Q3.1 (S), R5.4 (1), U4.9 (PA22)
UPDI: Q2.2 (S), R3.4 (1), U4.6 (PA14), U4.7 (PA15)
UPDI_5V: Q2.3 (D), R4.1; also elsewhere on the board
V_USB: F1.1, J5.A4B9 (VBUS), J5.B4A9 (VBUS), TVS1.5 (VCC)

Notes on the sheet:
Pin mapping of Evo: PA00: D2 PA01: D7 PA02: D20/SDA (not sharing I2C with GPIO) PA03: D21/SCL (not sharing I2C with GPIO) PA04: D24/TXD2 (WifiNINA) PA05: D23/RXD2 (WifiNINA) PA06: D28 (CCL-LUT0-OUT) PA07: D29 (CLK0, Analog Comparator AC0) PB00: D9~ on TCA0 PB01: D10~ on TCA0 PB02: D5~ on TCA0 PB03: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
To program w/o bootloader, refer to Breadboard SAMD11, part 1, which uses a CMSIS-DAP module An ARM MCU like the SAMD11 needs: - VCC (5V -> 3.3V) - GND - RST - SWCLK - SWDIO Short SWDIO to GND to enter bootloader mode for direct USB programming Firmware burning resources: https://www.avrfreaks.net/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
Extremely bizzare behaviour with IO0 and EN (CHIP_PU). When chip is booting, IO0 gets pulled down the moment the chip fully boots up, while remaining high when the chip is in reset (EN=0). Connecting either IO0 and EN to the 4809 results in IO pin overload and I cannot confirm if this behavior can 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
Via diameter of 0.35mm, min 0.2mm, recommend 0.5mm


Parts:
C4, C7, C8, C9, C11: 0.1uF; CAPC1005X60
C5: 100uF; CAPMP3216X180N
C6: 1uF; CAPC1005X60
C10, C12: 4.7uF; CAPC1005X60
D1: LED-RGBTC5050RGBF08; LED-TRICOLOR-5050
D2: LED0603; LED-0603
IC1: 74AHC1G125; SOT23-5L; LCSC_PART C124295
J4: CONN_06NO_SILK_FEMALE_PTH; 1X06_NO_SILK
J6: CONN_14NO_SILK; 1X14_NO_SILK
J9: CONN_191X19_NO_SILK; 1X19_NO_SILK
JP1, JP2, JP4: JUMPER-SMT_2_NO_SILK; SMT-JUMPER_2_NO_SILK
JP3: JUMPER-SMT_2_NC_TRACE_SILK; SMT-JUMPER_2_NC_TRACE_SILK
Q1: BSS138PS; ARDUINO-TRANSISTORS_SOT363; LCSC_PART C193381
Q4: BSS138PW; SOT65P210X110-3N
R6, R8: 10k; RESC1005X40
R7: 1k; RESC1005X40
R9: 12k; RESC1005X40
R10: RESISTOR_4PACK0402; RESPACK_4X0402
R13: 100k; RESC1005X40
R14, R15, R16, R17: 4.7k; RESC1005X40
SW1: SKRKAEE020; SW2-2.6-3.9X2.9X1.5+0.4MM; LCSC_PART C115357
U1: ESP-32S
U5: MEGA4809; TQFP48; LCSC_PART C189475
U6: 74HC4050DTSSOP; TSSOP16; LCSC_PART C352825

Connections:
3.3V: C4.1, C5.1 (+), IC1.5 (VCC), J6.4, Q1.2 (G), Q1.5 (G), Q4.1 (G), R8.2, R9.2, R14.2, R16.1, U1.2 (3V3), U6.1 (VCC); also elsewhere on the board
5V: C7.1, C8.1, C9.1, C10.1, J4.6, R6.1, R13.2, R15.2, R17.1, U5.14 (VDD1), U5.28 (AVDD), U5.42 (VDD2); also elsewhere on the board
BLU: D1.6 (BLU-A), R10.5 (2)
ESP_ACK: Q1.4 (S), R16.2, U1.9 (IO33)
ESP_BLUE: R10.4 (1), U1.12 (IO27)
ESP_CS: IC1.1 (!OE), U1.29 (IO5), U6.6 (3Y)
ESP_EN: C6.2, J6.13, JP3.2, R9.1, U1.3 (EN)
ESP_GREEN: R10.2 (1), U1.10 (IO25)
ESP_IO0: J6.14, Q4.2 (S), R8.1, U1.25 (IO0)
ESP_MISO: IC1.2 (A), U1.37 (IO23)
ESP_MOSI: U1.13 (IO14), U6.15 (6Y)
ESP_RED: R10.3 (1), U1.11 (IO26)
ESP_RX: U1.34 (U0RXD), U6.10 (4Y)
ESP_RX_5V: J4.4, JP1.2, U6.9 (4A)
ESP_SCK: U1.30 (IO18), U6.12 (5Y)
ESP_SCL: J6.12, U1.36 (IO22)
ESP_SDA: J6.11, U1.33 (IO21)
ESP_TX: Q1.1 (S), R14.1, U1.35 (U0TXD)
ESP_TX_5V: J4.3, JP4.2, Q1.6 (D), R15.1
GND: C4.2, C5.2 (-), C6.1, C7.2, C8.2, C9.2, C10.2, C11.2, C12.2, D1.1 (BLU-C), D1.2 (RED-C), D1.3 (GRN-C), IC1.3 (GND), J4.5, J9.15, R7.2, SW1.1, U1.1 (GND), U1.15 (GND), U1.38 (GND), U1.GND, U5.15 (GND), U5.29 (GND2), U5.43 (GND3), U6.8 (GND); also elsewhere on the board
GRN: D1.4 (GRN-A), R10.7 (2)
IO0_5V: JP2.2, Q4.3 (D), R6.2
unnamed: D2.C, R7.1
unnamed: JP3.1, U6.4 (2Y)
PA0_D2: J9.3, U5.44 (PA0)
PA1_D7: J9.8, U5.45 (PA1)
PA2_D20_SDA: J9.17, U5.46 (PA2)
PA3_D21_SCL: J9.18, U5.47 (PA3)
PA4_D24_TX2: JP1.1, U5.48 (PA4)
PA5_D23_RX2: JP4.1, U5.1 (PA5)
PA6_D28: JP2.1, U5.2 (PA6)
PA7_D29: U5.3 (PA7), U6.5 (2A)
PB0_D9~: J9.10, U5.4 (PB0)
PB1_D10~: J9.11, U5.5 (PB1)
PB2_D5~: J9.6, U5.6 (PB2)
PB3_D30: U5.7 (PB3)
PB4_D27_TX0: U5.8 (PB4); also elsewhere on the board
PB5_D26_RX0: U5.9 (PB5); also elsewhere on the board
PC0_MOSI: U5.10 (PC0), U6.14 (6A)
PC1_MISO: IC1.4 (Y), U5.11 (PC1)
PC2_SCK: U5.12 (PC2), U6.11 (5A)
PC3_D22: U5.13 (PC3)
PC4_D1_TX1: J9.2, U5.16 (PC4)
PC5_D0_RX1: J9.1, U5.17 (PC5)
PC6_D4: J9.5, U5.18 (PC6)
PC7_D31: U5.19 (PC7)
PD0_A0: J6.5, U5.20 (PD0)
PD1_A1: J6.6, U5.21 (PD1)
PD2_A2: J6.7, U5.22 (PD2)
PD3_A3: J6.8, U5.23 (PD3)
PD4_A4: J6.9, U5.24 (PD4)
PD5_A5: J6.10, U5.25 (PD5)
PD6_A6: D2.A, U5.26 (PD6)
PD7_A7_AREF: C11.1, C12.1, J9.16, U5.27 (PD7)
PE0_D11: J9.12, U5.30 (PE0)
PE1_D12: J9.13, U5.31 (PE1)
PE2_D13: J9.14, U5.32 (PE2)
PE3_D8: J9.9, U5.33 (PE3)
PF0_D37: U5.34 (PF0)
PF1_D38: U5.35 (PF1)
PF2_D35_A12: U5.36 (PF2), U6.7 (3A)
PF3_D36_A13: Q1.3 (D), R17.2, U5.37 (PF3)
PF4_D6~: J9.7, U5.38 (PF4)
PF5_D3~: J9.4, U5.39 (PF5)
PF6_RST: J6.3, R13.1, SW1.2, U5.40 (PF6)
RED: D1.5 (RED-A), R10.6 (2)
RESETN: J9.19; also elsewhere on the board
SWCLK: J6.2; also elsewhere on the board
SWDIO: J6.1; also elsewhere on the board
UPDI_5V: U5.41 (UPDI); also elsewhere on the board

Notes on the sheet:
A few options we can consider for voltage level shifting: BSS138 x2 array: $0.18350/US$0.0587 2 bi channels, 2.9c/channel 74HC4050: $0.45590/US$0.2008 for 6 uni channels only for 5->3.3, 3.3c/channel 74AHCT125: $0.29770/US$0.1021 for 4 uni channels only for 3.3->5, 2.5c/channel 74LVC4245A: $0.69920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
This pinout is largely based on the Arduino Uno Wifi R2 3x UART 1x SPI on PORTC 1x I2C on PORTA
TX/RX2 used as NINASerial
PORTC used as NINA SPI
TX/RX1 are broken out as D0/1 as Serial1, not connected to Serial
TX/RX0 goes to USB
#define SPIWIFI_SS 35 // Chip select pin PF2 #define SPIWIFI_ACK 36 // a.k.a BUSY or READY pin PF3 #define ESP32_RESETN 29 // Reset pin PA7 #define ESP32_GPIO0 28 // GPIO0 PA6 // MOSI: PC0 // MISO: PC1 // SCK: PC2
Note: LED unavailable in BLE mode
USB-C
CMSIS-DAP (3): SWIO SWCLK SWRST (RESETN) Power and Signal (2): RESET 3.3V Analog (6): A0-A5 ESP32 Breakout (4): ESP_SDA ESP_SCL ESP_RESET GPIO0 Serial-ESP32 interface (6): NC (3.3V) NC (DTR) ESP-TX ESP-RX GND 5V



Board: 2 copper layers, 62.5 x 25.4 mm, 51 parts (4 on the bottom side), 73 nets.

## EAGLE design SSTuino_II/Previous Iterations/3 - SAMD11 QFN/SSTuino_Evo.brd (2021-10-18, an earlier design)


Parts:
B1: ARDUINO_UNO_R3; ARDUINO_R3
C1: 100n; CAPC1005X60
C2, C3: 10uF; CAPC1608X85
D1: DT1042-04SO-7; SOT95P285X140-6N
F1: 6V/0.75A; 1206
J5: TYPE-C-31-M-12; HRO_TYPE-C-31-M-12
Q2, Q3: BSS138PS; ARDUINO-TRANSISTORS_SOT363; LCSC_PART C193381
R1, R2: 5.1k; RESC1005X40
R3, R5: 4.7k; RESPACK_4X0402
U2: ATSAMD11D14A; ARDUINO-UCS&SOCS_HVQFN24
U3: LM1117MP-3.3; SOT230P696X180-4N
U4: ATSAMD11D14A-SSNT; SOIC127P1030X265-20N

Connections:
3.3V: C1.1, C2.1, Q2.2 (G), Q3.2 (G), Q3.5 (G), R3.6 (2), R3.7 (2), R3.8 (2), R5.7 (2), R5.8 (2), U2.24 (VDDIO), U3.2 (OUT), U3.4 (VOUT); also elsewhere on the board
5V: C3.1, F1.2, R3.5 (2), R5.5 (2), R5.6 (2), U3.3 (IN); also elsewhere on the board
CC1: J5.A5 (CC1), R1.1
CC2: J5.B5 (CC2), R2.2
D_N: D1.4 (IO3), J5.A7 (DN1), J5.B7 (DN2), U2.21 (PA24/USB_DM)
D_P: D1.3 (IO2), J5.A6 (DP1), J5.B6 (DP2), U2.22 (PA25/USB_DP)
GND: C1.2, C2.2, C3.2, D1.2 (VSS), J5.A1B12 (GND), J5.B1A12 (GND), J5.S1 (SHIELD), J5.S2 (SHIELD), J5.S3 (SHIELD), J5.S4 (SHIELD), R1.2, R2.1, U2.23 (GND), U2.EXP (EP), U3.1 (ADJ/GND), U4.16 (GND); also elsewhere on the board
PB4_D27_TX0: Q3.3 (D), R3.4 (1); also elsewhere on the board
PB5_D26_RX0: Q3.6 (D), R5.4 (1); also elsewhere on the board
RESETN: R3.2 (1), U2.18 (PA28/RESETN)
RX_D11: Q3.4 (S), R3.3 (1), U2.16 (PA23)
SWCLK: R3.1, U2.19 (PA30/SWCLK); also elsewhere on the board
SWDIO: U2.20 (PA31/SWDIO); also elsewhere on the board
TX_D11: Q3.1 (S), R5.2 (1), U2.15 (PA22)
UPDI_3V3: Q2.1 (S), R5.1, U2.11 (PA14), U2.12 (PA15)
UPDI_5V: Q2.6 (D), R5.3 (1)
VDD: U4.17 (VDD)
V_USB: D1.5 (VCC), F1.1, J5.A4B9 (VBUS), J5.B4A9 (VBUS)

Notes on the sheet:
Pin mapping of Evo: PA00: D2 PA01: D7 PA02: D20/SDA (not sharing I2C with GPIO) PA03: D21/SCL (not sharing I2C with GPIO) PA04: D24/TXD2 (WifiNINA) PA05: D23/RXD2 (WifiNINA) PA06: D28 (CCL-LUT0-OUT) PA07: D29 (CLK0, Analog Comparator AC0) PB00: D9~ on TCA0 PB01: D10~ on TCA0 PB02: D5~ on TCA0 PB03: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
To program w/o bootloader, refer to Breadboard SAMD11, part 1, which uses a CMSIS-DAP module An ARM MCU like the SAMD11 needs: - VCC (5V -> 3.3V) - GND - RST - SWCLK - SWDIO Short SWDIO to GND to enter bootloader mode for direct USB programming
Extremely bizzare behaviour with IO0 and EN (CHIP_PU). When chip is booting, IO0 gets pulled down the moment the chip fully boots up, while remaining high when the chip is in reset (EN=0). Connecting either IO0 and EN to the 4809 results in IO pin overload and I cannot confirm if this behavior can 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
Via diameter of 0.35mm, min 0.2mm, recommend 0.5mm

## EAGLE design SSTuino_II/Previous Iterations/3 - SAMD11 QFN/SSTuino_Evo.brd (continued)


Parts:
C4, C7, C8, C9, C11: 0.1uF; CAPC1005X60
C5: 100uF; CAPMP3216X180N
C6: 1uF; CAPC1005X60
C10, C12: 4.7uF; CAPC1005X60
D2: LED0603; LED-0603
D3: LED-RGBNO_IC; LED-TRICOLOR-5050; LCSC_PART C784540
IC1: 74AHC1G125; SOT23-5L; LCSC_PART C124295
J2, J3: CONN_09NO_SILK; 1X09_NO_SILK
J4: CONN_06NO_SILK_FEMALE_PTH; 1X06_NO_SILK
J6: CONN_14NO_SILK; 1X14_NO_SILK
JP1, JP2: JUMPER-SMT_2_NO_SILK; SMT-JUMPER_2_NO_SILK
JP3: JUMPER-SMT_2_NC_TRACE_SILK; SMT-JUMPER_2_NC_TRACE_SILK
Q1, Q2: BSS138PS; ARDUINO-TRANSISTORS_SOT363; LCSC_PART C193381
R4: 4.7k; RESPACK_4X0402
R11, R13: 10k; RESC1005X40
R12, R15, R16, R17: 1k; RESC1005X40
R14: 12k; RESC1005X40
R18: 100k; RESC1005X40
RESET: MOMENTARY-SWITCH-SPST-SMD-4.6X2.8MM; TACTILE_SWITCH_SMD_4.6X2.8MM
U1: ESP-32S
U5: MEGA4809; TQFP48; LCSC_PART C189475
U6: 74HC4050DTSSOP; TSSOP16; LCSC_PART C43181

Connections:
3.3V: C4.1, C5.1 (+), IC1.5 (VCC), J6.4, Q1.2 (G), Q1.5 (G), Q2.5 (G), R4.1, R4.7 (2), R13.2, R14.2, U1.2 (3V3), U6.1 (VCC); also elsewhere on the board
5V: C7.1, C8.1, C9.1, C10.1, J4.6, R4.3 (1), R4.5 (2), R11.1, R18.2, U5.14 (VDD1), U5.28 (AVDD), U5.42 (VDD2); also elsewhere on the board
ESP_ACK: Q1.4 (S), R4.8 (2), U1.9 (IO33)
ESP_BLUE: R15.1, U1.12 (IO27)
ESP_CS: IC1.1 (!OE), U1.29 (IO5), U6.4 (2Y)
ESP_EN: C6.2, J6.13, JP3.2, R14.1, U1.3 (EN)
ESP_GREEN: R16.1, U1.10 (IO25)
ESP_IO0: J6.14, Q2.4 (S), R13.1, U1.25 (IO0)
ESP_MISO: IC1.2 (A), U1.37 (IO23)
ESP_MOSI: U1.13 (IO14), U6.6 (3Y)
ESP_RED: R17.1, U1.11 (IO26)
ESP_RX: U1.34 (U0RXD), U6.15 (6Y)
ESP_RX_5V: J4.4, JP1.2, U6.14 (6A)
ESP_SCK: U1.30 (IO18), U6.12 (5Y)
ESP_SCL: J6.12, U1.36 (IO22)
ESP_SDA: J6.11, U1.33 (IO21)
ESP_TX: J4.3, Q1.1 (S), R4.2 (1), U1.35 (U0TXD)
GND: C4.2, C5.2 (-), C6.1, C7.2, C8.2, C9.2, C10.2, C11.2, C12.2, D3.4 (BLU-C), D3.5 (RED-C), D3.6 (GRN-C), IC1.3 (GND), J2.4, J4.5, R12.2, RESET.3 (2), RESET.4 (2), U1.1 (GND), U1.15 (GND), U1.38 (GND), U1.GND, U5.15 (GND), U5.29 (GND2), U5.43 (GND3), U6.8 (GND); also elsewhere on the board
IO0_5V: JP2.2, Q2.3 (D), R11.2
unnamed: Q1.6 (D), R4.4 (1)
unnamed: D2.C, R12.1
unnamed: D3.3 (BLU-A), R15.2
unnamed: JP3.1, U6.2 (1Y)
unnamed: D3.1 (GRN-A), R16.2
unnamed: D3.2 (RED-A), R17.2
PA0_D2: J3.7, U5.44 (PA0)
PA1_D7: J3.2, U5.45 (PA1)
PA2_D20_SDA: J2.2, U5.46 (PA2)
PA3_D21_SCL: J2.1, U5.47 (PA3)
PA4_D24_TX2: JP1.1, U5.48 (PA4)
PA5_D23_RX2: U5.1 (PA5)
PA6_D28: JP2.1, U5.2 (PA6)
PA7_D29: U5.3 (PA7), U6.3 (1A)
PB0_D9~: J2.9, U5.4 (PB0)
PB1_D10~: J2.8, U5.5 (PB1)
PB2_D5~: J3.4, U5.6 (PB2)
PB3_D30: U5.7 (PB3)
PB4_D27_TX0: U5.8 (PB4); also elsewhere on the board
PB5_D26_RX0: U5.9 (PB5); also elsewhere on the board
PC0_MOSI: U5.10 (PC0), U6.7 (3A)
PC1_MISO: IC1.4 (Y), U5.11 (PC1)
PC2_SCK: U5.12 (PC2), U6.11 (5A)
PC3_D22: U5.13 (PC3)
PC4_D1_TX1: J3.8, U5.16 (PC4)
PC5_D0_RX1: J3.9, U5.17 (PC5)
PC6_D4: J3.5, U5.18 (PC6)
PC7_D31: U5.19 (PC7)
PD0_A0: J6.5, U5.20 (PD0)
PD1_A1: J6.6, U5.21 (PD1)
PD2_A2: J6.7, U5.22 (PD2)
PD3_A3: J6.8, U5.23 (PD3)
PD4_A4: J6.9, U5.24 (PD4)
PD5_A5: J6.10, U5.25 (PD5)
PD6_A6: D2.A, U5.26 (PD6)
PD7_A7_AREF: C11.1, C12.1, J2.3, U5.27 (PD7)
PE0_D11: J2.7, U5.30 (PE0)
PE1_D12: J2.6, U5.31 (PE1)
PE2_D13: J2.5, U5.32 (PE2)
PE3_D8: J3.1, U5.33 (PE3)
PF0_D37: U5.34 (PF0)
PF1_D38: U5.35 (PF1)
PF2_D35_A12: U5.36 (PF2), U6.5 (2A)
PF3_D36_A13: Q1.3 (D), R4.6 (2), U5.37 (PF3)
PF4_D6~: J3.3, U5.38 (PF4)
PF5_D3~: J3.6, U5.39 (PF5)
PF6_RST: J6.3, R18.1, RESET.1, RESET.2 (1), U5.40 (PF6)
SWCLK: J6.2; also elsewhere on the board
SWDIO: J6.1; also elsewhere on the board
UPDI: U5.41 (UPDI)

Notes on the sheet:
A few options we can consider for voltage level shifting: BSS138 x2 array: $0.18350/US$0.0587 2 bi channels, 2.9c/channel 74HC4050: $0.45590/US$0.2008 for 6 uni channels only for 5->3.3, 3.3c/channel 74AHCT125: $0.29770/US$0.1021 for 4 uni channels only for 3.3->5, 2.5c/channel 74LVC4245A: $0.69920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
This pinout is largely based on the Arduino Uno Wifi R2 3x UART 1x SPI on PORTC 1x I2C on PORTA
TX/RX2 used as NINASerial
PORTC used as NINA SPI
TX/RX1 are broken out as D0/1 as Serial1, not connected to Serial
TX/RX0 goes to USB
#define SPIWIFI_SS 35 // Chip select pin PF2 #define SPIWIFI_ACK 36 // a.k.a BUSY or READY pin PF3 #define ESP32_RESETN 29 // Reset pin PA7 #define ESP32_GPIO0 28 // GPIO0 PA6 // MOSI: PC0 // MISO: PC1 // SCK: PC2
Note: LED unavailable in BLE mode
USB-C
CMSIS-DAP (2): SWIO SWCLK Power and Signal (2): RESET 3.3V Analog (6): A0-A5 ESP32 Breakout (4): ESP_SDA ESP_SCL ESP_RESET GPIO0 Serial-ESP32 interface (6): NC (3.3V) NC (DTR) ESP-TX ESP-RX GND 5V
Warning: ESP_ACK and ESP_TX is not routed!!

Board: 2 copper layers, 49 parts (3 on the bottom side), 72 nets, no tracks yet.

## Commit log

2021-10-19 better folder structure
    [SSTuino_II_top_bom.csv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]
2021-11-29 added jig
    [SSTuinoII_Jig.brd, SSTuinoII_Jig.sch]
2021-11-29 updated documentation
    [SSTuino_II.brd]
2021-12-24 Added Explorer board
    [Explorer.brd, Explorer.sch]
2021-12-24 finalised test jig
    [SSTuinoII_Jig.brd, SSTuinoII_Jig.sch]
2021-12-24 added JST SH connector for SPI
    [SSTuino_II.brd, SSTuino_II.sch]
2022-01-16 finalised SSTuino II main board
    [PCB Specifications - 20211226.xlsx, SSTuino II BOM for Manufacturer - 20211226.xlsx, SSTuino_II.brd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]
2022-01-16 updated explorer board
    [Explorer.brd, Explorer.sch]
2022-01-16 final version of the revA jig, revB incoming soon
    [SSTuinoII_Jig.brd, SSTuinoII_Jig.sch]
2022-02-18 updated test jig
    [SSTuinoII_Jig.brd, SSTuinoII_Jig.sch]
2022-02-18 updated Explorer board to first prototype version
    [Explorer.brd, Explorer.sch]
2022-02-27 completed modifications to Explorer board for final production
    [Explorer.brd, Explorer_top_bom.xlsx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]
2022-06-07 added pinout diagram
    [Explorer_top_bom.xlsx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]
2022-07-03 updated BOM for 2022/23 batch
    [Explorer_top_bom.xlsx, PCB Specifications - 20211226.xlsx, SSTuino II BOM for Manufacturer - 20211226.xlsx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]
2022-12-29 added gerber and necessary production files
    [Explorer.brd, Explorer.sch, Explorer_top_bom.xlsx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]
2023-07-23 added PDF of schematic
    [SSTuino II BOM for Manufacturer - 20221229 RevA.1.xlsx, SSTuino_II.brd, SSTuino_II_both_bom.csv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]
2024-05-03 added auto tool
    [Explorer.GBL, Explorer.GBO, Explorer.GBP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]

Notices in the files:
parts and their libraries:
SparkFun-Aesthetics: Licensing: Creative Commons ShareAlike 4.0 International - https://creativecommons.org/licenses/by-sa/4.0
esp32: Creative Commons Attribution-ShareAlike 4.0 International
